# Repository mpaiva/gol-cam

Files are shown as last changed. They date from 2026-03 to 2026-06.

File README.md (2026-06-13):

# gol-cam

Sistema eletrônico completo para **futebol de botão**: uma câmera que detecta gols por visão computacional, um placar (LED tradicional ou touchscreen) que mostra a contagem e um conjunto de peças impressas em 3D que une tudo. A detecção atual combina três sinais — **cor (HSV), movimento (frame-differencing)** e **bordas (Sobel)** — calibrados em conjunto a partir de uma única captura da bola colocada no gol.

## Visão geral do sistema

O repositório agora compila firmware para **três tipos de placa**:

| Componente | Hardware | Função |
|---|---|---|
| **Câmera** | DFRobot DFR1154 (ESP32-S3 + OV3660) | Detecta gols por visão baseada em bordas; serve o painel web e o stream MJPEG |
| **Placar LED** | ESP32 DevKit V1 + 4× matrizes de LED MAX7219 8×8 + 4 botões | Exibe o placar em dígitos de LED físicos; recebe eventos de gol da câmera e suporta override manual |
| **HMI touchscreen** *(opcional)* | CrowPanel DIS07050H (ESP32-S3 + 5" 800×480 IPS capacitivo) | Placar touchscreen + superfície do árbitro com 8 botões: A+/A−/B+/B−, CAL A / START / RESET / CAL B. Fala o **mesmo contrato REST** do placar LED, então pode operar em paralelo ou substituí-lo completamente. |
| **Hardware** | Caixas impressas em 3D (`hardware/`) | Trave, caixa da câmera, gabinete do placar, acessórios |

**Topologia de rede:**

```
                  ┌──────────────┐
                  │  Smartphone  │
                  │  / tablet    │
                  └───────┬──────┘
                          │ Painel HTTP
                          │
       ┌──────────────────┼──────────────────┐
       │                  │                  │
       ▼                  ▼                  ▼
┌────────────┐     ┌────────────┐     ┌──────────────────┐
│ Câmera A   │     │ Câmera B   │     │ Placar           │
│ DFR1154    │     │ DFR1154    │     │ LED (MAX7219) ou │
│ side=A     │     │ side=B     │     │ HMI touchscreen  │
│ .40.90     │     │ .40.91     │     │ .40.89           │
└──────┬─────┘     └──────┬─────┘     └─────▲────────────┘
       │                  │                 │
       └──────────────────┴─────────────────┘
              GET /goal?side=a|b       na detecção
              GET /goal-undo?side=a|b  na anulação VAR
```

A vaga em `.40.89` pode ser ocupada pelo **placar LED** (ESP32 + MAX7219) **ou** pelo **HMI touchscreen** (CrowPanel) — ambos servem o mesmo contrato REST, então as câmeras não precisam saber qual está conectado. Configurar uma partida sem laptop fica simples: o HMI tem os botões CAL A / START / RESET / CAL B na tela e dispara os comandos HTTP para as duas câmeras.

Para uma configuração com apenas uma câmera, omita a Câmera B. Placa e câmera trabalham apenas em modo STA (sem fallback AP); se o WiFi cair, a câmera não consegue empurrar o gol, mas os 4 botões físicos no placar LED — ou os botões A+/A−/B+/B− na tela do HMI — continuam funcionando para placar manual.

**Esquema de IP estático sugerido** (define em `.env` via `WIFI_STATIC_IP` / `SCOREBOARD_STATIC_IP`):

O esquema mantém o **último octeto** fixo (`.89` placar / `.90` cam A /
`.91` cam B) — o prefixo da subnet acompanha a rede WiFi. Hoje em
`192.168.1.x` (RI69); antes em `192.168.40.x` (cross.team-orl). Use os
slots `WIFI_SSID_1..4` no `.env` para registrar redes conhecidas e o
firmware (WiFiMulti) escolhe a melhor disponível no boot.

| Placa | IP | Observação |
|---|---|---|
| Placar (LED **ou** HMI, não ambos ao mesmo tempo) | `192.168.1.89` | Câmeras empurram gols para cá |
| Câmera A (side A) | `192.168.1.90` | `BOARD_ROLE` não definido |
| Câmera B (side B) | `192.168.1.91` | `BOARD_ROLE=home` |

## Como funciona a detecção

Um DFR1154 (ESP32-S3 + câmera grande-angular OV3660) observa a área do gol em **RGB565 QVGA (320×240)**. Você calibra colocando a bola dentro da ROI, e o sistema aprende três assinaturas ao mesmo tempo:

1. **Bordas (Sobel)** — limiar de gradiente que descreve o silhueta da bola
2. **Cor (UV / HSV)** — par de chroma `(U, V)` médio dos pixels dentro do bbox, hue-invariante a mudanças de luma
3. **Movimento (frame-differencing)** — limiar de "piso de ruído" amostrado durante a calibração

Durante a partida, cada frame passa por três disparadores em paralelo, todos compartilhando o cooldown de 10 s:

- **Bordas** — dispara quando o silhueta aparece e desaparece, formato/tamanho dentro da bbox calibrada
- **Movimento** — conta pixels da ROI cuja luma mudou > limiar vs. o frame anterior, *após subtração da média* (DC removal) para ignorar variações uniformes de luz, e *após filtro de bbox compacto* (≤ 30 % da ROI) para rejeitar variações de luz não-uniformes ou sombras de mão
- **Cor** — conta pixels da ROI cuja chroma `(u, v)` está dentro da tolerância em torno do alvo calibrado; mesmo filtro de bbox compacto

O OR dos três triggers dispara o gol. O log serial `[detect]` mostra os três contadores (`e=`, `m=`, `c=`) e qual dispara, e o `GOAL #N` registra a fonte (`src=emc`, `src=mc`, etc.).

**Efeitos colaterais a cada gol:**
- Beep de 1,5 s @ 1 kHz pelo alto-falante I2S (placeholder — será substituído)
- LED IR pisca
- VAR captura *dois* snapshots: o frame de disparo (`/goal-snapshot`) e o frame anterior (`/goal-snapshot-prev`) — útil quando o trigger é por movimento e a bola já saiu do quadro no frame de disparo
- Push HTTP para o placar: `GET /goal?side=a|b`

**VAR (revisão de vídeo):** abrindo qualquer entrada no log de gols, o lightbox mostra os dois frames lado a lado ("Antes" / "Disparo"). Os botões "Foi Gol" mantém; "Anula" decrementa o `goalCount` da câmera **e** dispara `GET /goal-undo?side=a|b` no placar, mantendo o display em sincronia.

Recursos:
- Stream MJPEG ao vivo (a cores)
- Calibração em um clique aprende bordas + cor + ruído de movimento
- Detecção automática de gols com cooldown de 10 s
- Lightbox VAR de dois frames com sincronização do placar na anulação
- Endpoints REST para ajuste em tempo real: `/motion-delta`, `/motion-threshold`, `/motion-bbox-max`, `/color-tol`, `/color-threshold`, `/stream-skip`
- Controles de jogo: iniciar, pausar, retomar, encerrar, reiniciar
- Placar físico de LED com botões de override manual
- `/test-fire` simula um gol completo (snapshot VAR + áudio + push) para testar o pipeline sem a bola

## Futebol de Botão e o Dadinho no Rio de Janeiro

O **futebol de botão** é um esporte de mesa nascido no Brasil na década de 1930, no qual jogadores impulsionam discos circulares com o dedo para movimentar uma peça menor — a bola — por um campo em miniatura. O jogo surgiu da criatividade da garotada brasileira, que transformava botões, tampinhas de garrafa e moedas em times, jogando em mesas de jantar e tabuleiros de madeira pelo país.

### Origens

As raízes do esporte remontam às décadas de 1930 e 1940, quando Geraldo Decourt, de São Paulo, publicou as primeiras regras formais em 1930. O que começou como passatempo infantil rapidamente cresceu para uma atividade competitiva organizada. Em meados do século XX, clubes e federações já haviam se formado, e variações regionais de regras floresceram.

### Rio de Janeiro e a Regra Carioca

O Rio de Janeiro se tornou um dos centros mais importantes do esporte, desenvolvendo seu próprio estilo distinto conhecido como **Regra Carioca** ou **3 Toques**. Por essas regras, o jogador tem até três toques por jogada para avançar a bola, criando um jogo mais rápido e mais tático em comparação com outras variantes regionais.

### O Dadinho

A variante **Dadinho** representa um ramo distinto do futebol de botão. Em vez dos tradicionais discos redondos, os jogadores usam pequenos dados — tipicamente cubos amarelos de 6 mm — como peças. O nome vem de "dado" com o sufixo diminutivo "-inho".

O Dadinho foi oficialmente reconhecido pela Confederação Brasileira de Futebol de Mesa (CBFM) em 2010, dando-lhe a mesma posição institucional das modalidades tradicionais baseadas em disco. A variante tem seu próprio circuito competitivo dedicado, com o Campeonato Brasileiro de Dadinho chegando à 16ª edição em 2025.

## Hardware

### Lista de materiais (BOM)

**Placa da câmera (×1 modo single ou ×2 modo match):**
- 1× DFRobot DFR1154 (ESP32-S3 + OV3660, 16 MB flash, 8 MB PSRAM)
- 1× amplificador I2S MAX98357 + alto-falante pequeno (já inclusos na placa DFR1154)
- Cabo USB-C para alimentação e gravação

**Placa do placar LED (×1, opcional):**
- 1× ESP32 DevKit V1 (qualquer ESP32 com ≥8 GPIOs livres)
- 4× módulos de matriz de LED MAX7219 8×8 (cadeia FC-16), 2 por lado
- 4× push buttons (momentâneos, normalmente abertos)
- Jumpers e fonte de 5 V (USB no DevKit funciona)

**HMI touchscreen (×1, opcional — alternativa ao placar LED):**
- 1× CrowPanel DIS07050H (ESP32-S3-WROOM-1-N4R8, 5" 800×480 RGB IPS, touch capacitivo GT911)
- Cabo USB-C para alimentação e gravação
- *Substitui* o placar LED se ocupar o IP `.89`; ou roda em paralelo num IP diferente para servir como segundo display do árbitro

**Mecânica:**
- Peças impressas em 3D a partir de `hardware/` (PLA, veja `hardware/README.md` para configurações do slicer)

### Fiação do placar (ESP32 DevKit V1)

Os macros estão inline no topo de `src_scoreboard/scoreboard.cpp`.

**Display A** (placar da esquerda, 2 módulos em cadeia, DOUT → DIN):

| MAX7219 | GPIO | Macro |
|---|---|---|
| DIN | 23 | `DIN1` |
| CLK | 18 | `CLK1` |
| CS  | 5  | `CS1`  |
| VCC | 5V (VIN) | — |
| GND | GND | — |

**Display B** (placar da direita, 2 módulos em cadeia):

| MAX7219 | GPIO | Macro |
|---|---|---|
| DIN | 19 | `DIN2` |
| CLK | 21 | `CLK2` |
| CS  | 22 | `CS2`  |

**Botões** (cada um do GPIO ao GND, `INPUT_PULLUP` — sem resistores externos):

| Botão | GPIO | Macro | Ação |
|---|---|---|---|
| UP A | 32 | `UP1` | Incrementa lado A |
| DW A | 33 | `DW1` | Zera lado A |
| UP B | 25 | `UP2` | Incrementa lado B |
| DW B | 26 | `DW2` | Zera lado B |

### Pinagem da câmera

Veja `include/pins.h` — pré-configurada para a placa DFR1154. Não precisa fazer fiação.

### HMI touchscreen (CrowPanel)

Não precisa fazer fiação — toda a placa vem com o display RGB paralelo, touch I²C (GT911 em 0x5D, SDA=GPIO 19, SCL=GPIO 20), backlight (GPIO 2) e UART0 via CH340 conectados de fábrica. Definições de pino em `src_hmi/main.cpp`.

### Peças impressas em 3D

Veja `hardware/README.md` para o catálogo de peças (trave V4, caixa da câmera V5.2, gabinete do placar, suporte de alto-falante, grade de cooler) com recomendações de fatiamento.

## Primeiros passos

### Pré-requisitos

- [Git](https://git-scm.com/downloads)
- [Python 3](https://www.python.org/downloads/) (marque "Add to PATH" no instalador do Windows)
- Cabo USB-C para o DFR1154; cabo USB para o ESP32 DevKit
- **Apenas Windows:** [driver USB CP210x](https://www.silabs.com/developers/usb-to-uart-bridge-vcp-drivers) (pode ser necessário para comunicação serial)

### Passo 1 — Clonar o repositório

```bash
git clone https://github.com/mpaiva/gol-cam.git
cd gol-cam
```

### Passo 2 — Criar um ambiente virtual Python

**Mac (Terminal):**
```bash
python3 -m venv .venv
source .venv/bin/activate
pip install platformio
```

**Windows (PowerShell):**
```powershell
python -m venv .venv
.venv\Scripts\Activate.ps1
pip install platformio
```

> Se o PowerShell bloquear o script, rode `Set-ExecutionPolicy -Scope CurrentUser RemoteSigned` antes.

### Passo 3 — Configurar `.env`

Crie um arquivo `.env` na raiz do projeto (ignorado pelo git):

```ini
# Obrigatório — mesma WiFi para câmera e placar
WIFI_SSID=nome-da-sua-rede
WIFI_PASSWORD=sua-senha

# IP do placar — todas as câmeras empurram gols para cá (recomendado: estático)
SCOREBOARD_IP=192.168.1.89
SCOREBOARD_STATIC_IP=192.168.1.89
SCOREBOARD_GATEWAY=192.168.1.1
SCOREBOARD_SUBNET=255.255.255.0

# Per-board (definir antes de gravar cada câmera; valores comentados são exemplos)
# Câmera A (side A — padrão):  WIFI_STATIC_IP=192.168.1.90, BOARD_ROLE não definido
# Câmera B (side B):            WIFI_STATIC_IP=192.168.1.91, BOARD_ROLE=home
WIFI_GATEWAY=192.168.1.1
WIFI_SUBNET=255.255.255.0
# WIFI_STATIC_IP=192.168.1.90
# BOARD_ROLE=home              # home → side B; ausente → side A
# SCOREBOARD_SIDE=b            # override explícito (a|b), tem prioridade sobre BOARD_ROLE
```

`load_env.py` lê esses valores e injeta como `-D` defines de build, então são compilados no firmware. Como `WIFI_STATIC_IP` e `BOARD_ROLE` precisam ser diferentes em cada câmera, ajuste-os antes de cada gravação.

### Passo 4 — Compilar e gravar

Três ambientes PlatformIO convivem no mesmo projeto, um por tipo de placa:

```bash
# Câmera (padrão — igual a `pio run`)
pio run -e dfr1154 -t upload

# Placar LED MAX7219
pio run -e placar -t upload

# HMI touchscreen CrowPanel (alternativa ao placar LED)
pio run -e crowpanel_hmi -t upload
```

O ambiente padrão é `dfr1154`, então um `pio run` sem parâmetros compila a câmera. Grave uma placa por vez, ajustando o `.env` entre gravações se quiser valores diferentes de `BOARD_ROLE` ou IP estático.

Para usar o **HMI no lugar do placar LED**, defina `WIFI_STATIC_IP=192.168.1.89` antes de gravar o HMI e desligue a placa do MAX7219 — as câmeras seguem empurrando gols para `.89` sem nenhuma mudança no firmware delas.

### Passo 5 — Descobrir o IP e abrir o painel

```bash
pio device monitor   # baud 115200, procure "Dashboard: http://..." na câmera
```

Abra o IP da câmera no navegador. Você verá o seletor de modo:
- **Training (Treino)** — uma câmera, calibração e prática
- **Match (Partida)** — duas câmeras + placar opcional; configure os IPs na primeira carga (salvos no `localStorage`)

O placar serve sua própria interface simples no IP dele (incremento/reset manual, mais o status atual da conexão).

## Operação

### Fluxo padrão de partida

1. **Calibre cada câmera** — coloque o dadinho na frente do gol, clique em "Calibrate"
2. **Inicie o jogo** — o painel de partida mostra os feeds ao vivo e o placar unificado
3. **Jogue** — a câmera detecta gols, toca som de comemoração, envia o evento para o placar e incrementa o placar de LED
4. **Revisão VAR** — clique em qualquer entrada de gol para confirmar ou anular (gols anulados subtraem do lado certo)
5. **Pausar / retomar / reiniciar / encerrar** — controles atingem todas as placas simultaneamente

### Placar autônomo (sem câmera)

Mesmo com as câmeras offline ou desligadas, o placar continua funcionando:
- **Placar LED**: botões físicos sempre funcionam (UP A/B, RESET A/B). A interface web em `http://192.168.1.89/` espelha os botões + adiciona `/api/reset`.
- **HMI touchscreen**: os 8 botões na tela (A+ / A− / B+ / B−, CAL A / START / RESET / CAL B) operam o placar e as câmeras direto pelo display, sem precisar de celular ou notebook.
- Endpoints REST disponíveis em qualquer das duas placas: `/goal?side=a|b` (+1), `/goal-undo?side=a|b` (−1, com piso em 0), `/a+`, `/b+`, `/az`, `/bz`, `/reset`, `/api/reset`, `/status`.
- O HMI também expõe endpoints de diagnóstico do touch: `/debug/touch` retorna estado do controlador GT911 em JSON (útil quando o painel parece não responder).

## Estrutura do repositório

```
gol-cam/
├── platformio.ini              # Três ambientes: dfr1154 + placar + crowpanel_hmi
├── partitions.csv              # Layout de 16 MB de flash para a câmera
├── load_env.py                 # .env → -D defines de build
├── .env                        # WiFi + IP estático + role (ignorado pelo git)
├── include/
│   ├── camera.h, pins.h        # Câmera (DFR1154)
│   ├── frame_store.h           # Buffer JPEG thread-safe para o stream MJPEG
│   └── goal_detector.h         # Struct GoalDetector (contadores, FPS)
├── src/
│   ├── main.cpp                # Câmera: loop de detecção (bordas + movimento + cor)
│   ├── web_stream.cpp          # Servidor HTTP da câmera (esp_http_server)
│   ├── mode_select.h           # HTML do seletor Training / Match
│   ├── training_dashboard.h    # HTML/JS do painel de treino (uma câmera)
│   └── match_dashboard.h       # HTML/JS do painel de partida (duas câmeras)
├── src_scoreboard/
│   └── scoreboard.cpp          # Placar LED: firmware monolítico (WiFi + MAX7219 + HTTP + botões)
├── src_hmi/
│   └── main.cpp                # HMI touchscreen: RGB panel + GT911 + REST do placar + 8 botões touch
├── tests/integration/
│   └── test_system.py          # Suíte stdlib que exercita o contrato REST ao vivo (70 checks)
├── hardware/                   # Caixas impressas em 3D
├── .about/                     # Proposta de valor, feature requests
├── .plans/                     # Planos de implementação, notas de sessão
└── .reports/                   # Pesquisa, auditoria de UX, screenshots
```

## Testes

Suíte de integração que bate na REST ao vivo das três placas:

```bash
python3 tests/integration/test_system.py
```

70 checks cobrindo formato do `/status`, transições `/calibrate`, `/reset`, `/deduct` (clamp em 0), e o caminho de sincronização entre câmera e placar (`/test-goal` empurrando para `.89`, `/test-fire` com snapshot VAR, anulação VAR via `/goal-undo`). Skip automático de qualquer placa que estiver offline.

## Licença

MIT

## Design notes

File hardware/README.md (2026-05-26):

# Hardware — Modelos 3D imprimíveis

Peças mecânicas do sistema gol-cam, importadas do projeto auxiliar `GOOOL Elatronico` em 2026-05-24. Os modelos do placar virão do `Placar Eletronico` na Fase 2 do plano de consolidação (ver `.plans/consolidation-plan.md`).

Todos os arquivos `.3mf` são projetos completos do Bambu Studio / PrusaSlicer (incluem orientação, suportes e settings recomendados). Os `.stl` são as malhas cruas — use-os se preferir reimportar em outro slicer.

---

## Layout

```
hardware/
├── trave/                   # Estrutura da trave eletrônica (atual: V4)
├── caixa-camera/            # Encaixe da câmera DFR1154 (atual: V5.2)
├── placar/                  # Caixa do placar ESP32 + MAX7219 (vem na Fase 2)
├── acessorios/              # Fixação do autofalante, grade do cooler
└── arquivos-historicos/     # Versões antigas — referência apenas
```

---

## `trave/` — Trave eletrônica

A trave é a estrutura principal: gol de futebol de botão de 15 cm × 4 cm que abriga a câmera no teto e a "boca" abre a região do gol.

| Arquivo | Função | Versão |
|---|---|---|
| `Trave Eletronica+teto V4.3mf` | Trave + teto integrados, projeto Bambu | **Atual** |
| `Trave Eletronica+teto V4.stl` | Mesma malha em STL | **Atual** |
| `Boca da Trave.3mf` | Anteparo frontal (boca do gol) | **Atual** |
| `Boca da Trave.stl` | Mesma malha em STL | **Atual** |

**Recomendação de impressão:** PLA, camada 0.2 mm, infill 20–30%, com suportes na parte de baixo do teto.

---

## `caixa-camera/` — Encaixe da câmera DFR1154

Caixa que envolve a placa DFR1154 (42 × 42 mm, ESP32-S3 + OV3660) e fixa dentro do teto da trave. A versão atual é a **V5.2**, com base separada para facilitar o acesso ao conector USB-C.

| Arquivo | Função | Versão |
|---|---|---|
| `Caixa Camera Golll V5.2.3mf` | Corpo da caixa (V5.2) | **Atual** |
| `Base Caixa Camera Golll V5.2.stl` | Base/tampa de fundo (V5.2) | **Atual** |
| `Caixa Camera Golll V5.1.3mf` | Corpo (V5.1, fallback) | Ativa |
| `Caixa Camera Golll V5.1.stl` | Malha STL (V5.1) | Ativa |

**Recomendação de impressão:** PLA, camada 0.16 mm para detalhe na abertura da lente, sem suportes (geometria foi planejada para imprimir orientada).

---

## `placar/` — Caixa do placar LED

Caixa do placar físico (ESP32 DevKit V1 + 4× matrizes LED MAX7219 8×8 + 4 botões push). Modelos serão importados do projeto `Placar Eletronico` durante o subtree merge (Fase 2 do plano).

> Esperar até a Fase 3 concluir — após isso esta pasta conterá `Placar ESP 32 Wifi.3mf` e `New Scene.3mf`.

---

## `acessorios/` — Peças auxiliares

| Arquivo | Função |
|---|---|
| `Est. Fix. Autofalante 1.3mf` | Suporte de fixação do autofalante (saída de áudio I2S/MAX98357 do gol-cam) |
| `grade_para_cooler_colmeia_com_borda_85mm.3mf` | Grade tipo colmeia 85 mm, ventilação interna |

---

## `arquivos-historicos/` — Referência apenas

Versões anteriores das caixas de câmera e traves. **Não imprima a partir destes arquivos** sem antes confirmar que substituem alguma peça nova. Mantidos para rastrear evolução do design.

- Caixas V1, V2, V3, V3.1, V3.2, V3.3 (substituídas pela V5.x)
- Trave V3 e versões `Trave Desmontada`, `Trave Eletronica+teto` (sem versão), `Trave Eletronica` (sem teto) — substituídas pela V4

---

## Origem

- Pasta `trave/`, `caixa-camera/`, `acessorios/`, `arquivos-historicos/`: projeto `C:\_PROJETOS\GOOOL Elatronico` (sem git, importado por cópia em 2026-05-24)
- Pasta `placar/`: projeto `C:\_PROJETOS\Placar Eletronico` (importado via `git subtree merge`, preservando histórico)

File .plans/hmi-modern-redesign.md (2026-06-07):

# Plan — Redesign the HMI placar as a modern sports app

**Date:** 2026-06-07
**User prompt:** *"use frontend design skills to redesign the interface
into a modern sports app"* — then, after a first attempt was
rejected: *"this modern scoreboard show the timer, which we dont have,
but we need to add to the plan."* with a screenshot of a 2014 FIFA
World Cup ARG vs GER scoreboard widget as reference.

The current placar UI is functional but reads as a debug surface: a
flat black background, big bitmap digits, eight pill buttons arranged
in two rows. This plan rebuilds the main view as a **compact, card-
based scoreboard** modelled on the user's reference: pill-shaped
container with a circular minute-timer at the centre, score-on-dark
rectangles per team, status row of controls underneath.

**First attempt (rejected):** the Brasileirão palette + full-screen
split-card layout was a different direction from what the user wanted
(see git stash @{0} for the implementation). Keep the failed attempt
around as a colour-palette reference but discard the layout.

The calibration overlay is intentionally **out of scope** for this
plan — it was just redesigned (white panel + cam-snapshot preview)
and its own redesign would land in a phase 2.

---

## 1. Current vs target

### Today
```
┌──────────────────────────────────────────────────────────────┐
│ gol-cam                                       [PLACAR pill]  │
│                                                              │
│                       0  x  0                                │   ← bitmap digits
│                                                              │
│ ┌──────┐ ┌──────┐ ┌──────┐ ┌──────┐                          │   ← A+/A-/B-/B+
│ │ A +  │ │ A -  │ │ B -  │ │ B +  │                          │
│ └──────┘ └──────┘ └──────┘ └──────┘                          │
│ ┌──────┐ ┌──────┐ ┌──────┐ ┌──────┐                          │   ← CAL/START/RESET/CAL
│ │CAL A │ │START │ │RESET │ │CAL B │                          │
│ └──────┘ └──────┘ └──────┘ └──────┘                          │
│                                                              │
│   HOME [IDLE pill]              AWAY [IDLE pill]             │
└──────────────────────────────────────────────────────────────┘
```

### Target (inspiration-driven card scoreboard)

Modelled directly on the user's reference image — a pill-shaped main
scoreboard with a circular timer at the centre, score-on-dark
rectangles for each team. On our 800×480 canvas we have room for the
scoreboard pill on top AND a second pill or row underneath for the
control surface.

```
        ┌─────────────────────────────────────────────┐
        │                                             │
        │  ╔══╗         ╭─────╮          ╔══════════╗ │
        │  ║●●║         │ 12' │   HOME ◆ ║    0     ║ │
        │  ║●●║         │ 45" │          ╚══════════╝ │   ← scoreboard pill
        │  ╚══╝         ╰─────╯          ╔══════════╗ │      y=30..200 (h=170)
        │                                ║   AWAY   ║ │
        │  app icon     timer ring  AWAY ◆ ║    0     ║ │
        │  / logo                          ╚══════════╝ │
        │                                             │
        └─────────────────────────────────────────────┘

        ┌────────────────────┐  ┌──────────────────────┐
        │  ● HOME READY      │  │  ● AWAY READY        │  ← status pills
        │  cam @ .40.90      │  │  cam @ .40.91        │      y=220..300
        └────────────────────┘  └──────────────────────┘

   ┌──┐ ┌──┐ ┌────────┐ ┌────────┐ ┌────────┐ ┌────────┐ ┌──┐ ┌──┐
   │− │ │+ │ │ CAL A  │ │ ▶ START│ │ RESET  │ │ CAL B  │ │− │ │+ │   ← controls
   └──┘ └──┘ └────────┘ └────────┘ └────────┘ └────────┘ └──┘ └──┘      y=330..460
   A    A                                                  B    B
```

Net visual changes from today:
- **Pill-shaped scoreboard** instead of a flat header + huge digits.
  Rounded ~25–30 px corners. Cream/off-white background mimicking the
  reference. Sits at the top of the screen as the dominant element.
- **Circular minute-timer** (~140 px diameter) centred in the pill.
  Shows `M' SS"` (minute and seconds since START tap). A ring around
  the disc fills in as the timer advances — emerald arc on the right
  side per the reference. **This is new — we have no timer today.**
- **Score-on-dark blocks** per team. Each team gets a horizontal row
  with: team label ("HOME" / "AWAY") + small colored "flag" disc
  (no national flags — just a coloured pill to identify the side) +
  a dark rectangle holding the score in large white digits. Matches
  the reference's "ARG 🏳️ 3" / "GER 🏳️ 1" stacked rows.
- **Separate status pills** for each team below the scoreboard,
  showing cam-state dot + label + cam IP. Replaces the in-card
  status row from the rejected attempt.
- **Control row** of pill-shaped buttons at the bottom — same 8
  controls as today (A−/A+, CAL A, START, RESET, CAL B, B−/B+) but
  styled as discrete pills rather than a ribbon.

---

## 2. Color palette — match the reference

Pulled directly from the user's reference image. RGB565-safe.

- Page background: `0x0500` deep green field (kept from the Brasileirão
  attempt — it complements the cream pills well, same as the
  reference's blurry green stadium backdrop).
- Pill background (scoreboard, status pills, control buttons):
  `0xEF7D` warm cream (slight yellowish tint, soft).
- Score-block background (the dark rectangle holding each digit):
  `0x2104` near-black charcoal.
- Score digits: `0xFFFF` white.
- Team label text on pill: `0x4208` dark slate.
- Timer numerals: `0x2104` near-black.
- Timer ring (progress arc): `0x07E2` emerald green; track:
  `0xC638` light grey.
- Status dots: same as today (green READY, orange CAL, yellow PAUSE,
  red OFFLINE, grey IDLE).
- Action button (START): green `0x0640` bg + white text.
- Destructive button (RESET, `−`): red `0xC000` bg + white text.
- CAL buttons: amber `0xFD20` bg + black text.
- Score-adjust `+`: green; `−`: red. Both narrow.

---

## 3. Typography hierarchy

Arduino_GFX scales by integer multiples of its bitmap font (~6×8
base glyph). Available size tiers: 2 (12×16), 3 (18×24), 4 (24×32),
5 (30×40), 6 (36×48), 8 (48×64).

| Element | Size | Pixels per glyph |
|---|---|---|
| Score digit (in dark block) | 6 | 36×48 — single digit fits in a 70 px wide block |
| Timer minutes ("12'") | 6 | 36×48 |
| Timer seconds ("45\"") | 3 | 18×24 — sits below the minute number, smaller |
| Team label ("HOME", "AWAY") | 3 | 18×24 |
| Status badge ("READY", "OFFLINE") | 2 | 12×16 |
| Cam IP / metadata | 2 | 12×16 |
| Button label | 3 | 18×24 |
| Score-adjuster `+ / −` | 4 | 24×32 (big enough to read) |

---

## 4. Component spec

### Scoreboard pill (y=20–200, x=40–760, w=720, h=180, r=30)
- `fillRoundRect` cream background, white border 2 px.
- Internal layout (left to right):
  - **App badge** (~x=70, y=100, r=50): green-felt circle with
    a tiny soccer-ball glyph (overlapping fillCircles drawn in
    a pentagon-ish pattern — cheap stylization). Replaces the
    reference's FIFA World Cup logo.
  - **Timer disc** (~x=300, y=110, r=70): white circle with
    minute number ("12'") in size-6 black, seconds ("45\"") in
    size-3 grey underneath. Outside the circle, a partial ring
    (drawn via many short arcs) shows progress through the
    notional half (full ring at 45'). Track grey, progress
    emerald.
  - **Score column** (x=470 to 720): two stacked rows.
    - Row 1 (y=45..115): `HOME ● ║ 3 ║` — label size 3 black,
      colored disc (HOME = cobalt), then a dark rectangle
      (x=600..720, h=70) with white size-6 digit centred.
    - Row 2 (y=125..195): `AWAY ● ║ 1 ║` — same layout, AWAY
      colored disc (yellow).

### Match timer state (NEW)
- Tracked in three new globals: `uint32_t matchStartMs`,
  `uint32_t matchPausedAccumMs`, `enum MatchState
  {MS_IDLE, MS_PLAYING, MS_PAUSED}`.
- Behaviour:
  - `MS_IDLE`: display "00' 00\""; ring empty.
  - START tap → `matchStartMs = millis()`, state = MS_PLAYING.
  - PAUSE tap → `matchPausedAccumMs += millis() - matchStartMs`,
    state = MS_PAUSED.
  - RESUME tap → `matchStartMs = millis()`, state = MS_PLAYING
    (the previous elapsed time lives in `matchPausedAccumMs`).
  - RESET tap → `matchPausedAccumMs = 0`, state = MS_IDLE.
  - Display: `elapsedMs = (state == MS_PLAYING)
      ? (millis() - matchStartMs + matchPausedAccumMs)
      : matchPausedAccumMs;`
- Timer redraw runs on a dirty flag set when (a) state changes or
  (b) the displayed minute or second value advances. A 500 ms loop
  poll on the timer is plenty.
- The cams' state is independent of `MatchState`; the timer is
  HMI-local.

### Status pills (y=220–300, two side-by-side)
- Left pill: HOME, x=40..390 (w=350, h=70, r=20).
  Inside: `● READY` size 3 + cam IP size 2 below.
- Right pill: AWAY, x=410..760.
- Same cream pill style as the scoreboard.

### Control row (y=330–460, h=130)
- Eight pill buttons, single row, similar widths to the
  rejected-attempt's footer ribbon:
  - `−` (A score down): x=10, w=60, h=110, r=20, red bg
  - `+` (A score up): x=80, w=60, red bg
  - `CAL A`: x=160, w=130, amber bg, black text
  - `▶ START`: x=300, w=160, green bg, white text (label flips
    to `⏸ PAUSE` / `▶ RESUME` per cam state, same as today)
  - `⟲ RESET`: x=470, w=130, red bg, white text
  - `CAL B`: x=610, w=130, amber bg, black text
  - `−`: x=750, w=60... actually we run out of width here. Tune
    spacing — likely shrink the inner buttons to 110 px or move
    score adjusters to the very edges with smaller widths.

### Touch hit-test
- Score adjusters become 60 px wide × 110 px tall. Still well
  above the GT911's effective resolution.
- CAL buttons at 130 px wide — comfortably tappable.

---

## 5. Implementation breakdown

All work in `src_hmi/main.cpp`. Estimated ~600 LOC churn (more than
the rejected attempt because of the timer state machine + circular
timer rendering).

1. **Palette constants** (~`src_hmi/main.cpp:430`): cream pill bg,
   charcoal score-block bg, slate text, emerald + grey ring colors.
2. **Match-timer state machine** — three new globals
   (`matchStartMs`, `matchPausedAccumMs`, `MatchState matchState`)
   and a helper `matchElapsedMs()` that returns the live elapsed.
   Wire `START`, `PAUSE`/`RESUME`, `RESET` action handlers to
   transition this state. Add a `dirtyTimer` flag set every 500 ms
   from `loop()` so the timer text refreshes once per second
   without redrawing the whole pill.
3. **Replace `drawHeader()`** → no longer needed; replaced by the
   scoreboard pill which IS the top of the screen. Remove the
   header-strip code path entirely.
4. **New `drawScoreboardPill()`** — paints the cream pill, the app
   badge circle, the timer disc with ring (helper
   `drawTimerRing(cx, cy, r, progress01)`), and the two team rows
   (label + flag-disc + dark score-block + white digit).
5. **New `drawStatusPills()`** — two cream pills with status dot,
   state label, cam IP. Replaces `drawSideStatus`.
6. **Reshape the `buttons[]` array** to the new control-row
   coordinates from §4.
7. **`drawButton(idx)`** — keep mostly as-is. Use rounded-rect r=20
   for the pill aesthetic. Already handles START label flip.
8. **`renderFull()`** — clear bg, scoreboard pill, status pills,
   buttons. Drop `drawHeader` + `drawScoreDigits` + `drawSideStatus`
   from the rotation since they're folded into the new helpers.
9. **Dirty-flag wiring** — `dirtyScore` triggers
   `drawScoreboardPill` (score lives inside it). `dirtyTimer`
   redraws ONLY the timer disc, not the whole pill (small
   sub-region repaint).
10. **Glyph helpers** — small drawn primitives for play triangle,
    pause bars, reset spiral. ~30 LOC.

---

## 6. Acceptance criteria

| # | Criterion | How to verify |
|---|---|---|
| AC1 | Scoreboard pill is the dominant element at the top, score digits visible from across the room. | Manual eyeball test |
| AC2 | Timer counts up by seconds after tapping START; pauses on PAUSE; resumes on RESUME; resets on RESET. | Tap START, wait 5 s, tap PAUSE, verify display freezes; tap RESUME, verify resumes; tap RESET, verify back to `00' 00"`. |
| AC3 | Timer ring fills visibly as the timer advances (track grey, fill emerald). | Manual; check both the disc and the ring update. |
| AC4 | HOME / AWAY status pills show correct state (READY / IDLE / CAL / PAUSE / OFFLINE) per cam. | Manual + power-cycle a cam to see the state changes. |
| AC5 | All 8 control buttons fit in the row and respond to taps. | Manual + tap each button. |
| AC6 | Calibration overlay still works (it's drawn on top of the new placar). | Tap CAL A → overlay appears, dismisses cleanly. |
| AC7 | All 70 integration tests still pass (REST surface unchanged). | `python3 tests/integration/test_system.py` |
| AC8 | HMI `/status` soak stays ≥ 80/90 (no regression from the pclk fix). | 90 s × 1 Hz triple-board soak |

---

## 7. Risks

- **Glyph rendering.** Arduino_GFX's default font doesn't carry
  `▶ ⟲ ⏸ ●`. We draw these as primitives (filled triangle,
  arc-segment, two vertical rects, filled circle). Small functions,
  ~10 LOC each.
- **Button text wrapping.** With buttons at 110 px wide and size 3
  text (18 px / char), `CAL A` = 90 px fits, `START` = 90 px fits,
  `RESET` = 90 px fits. Safe.
- **Card border vs touch.** A 14 px rounded corner means the
  hit-test rect overlaps the card visual by ~14 px in the corner.
  Buttons sit OUTSIDE the cards in the footer, so no conflict.
- **Refresh rate.** At 8 MHz pclk (~17 Hz), large fillRounded calls
  on every dirty flag could look sluggish. Audit which areas
  actually need to redraw on score changes (only the inner score
  digit, not the whole card).

---

## 8. Open questions

- **Timer convention.** A button-soccer match isn't a standard
  90-min football match. Options: (a) free-running count-up
  showing `M' SS"`; (b) bounded countdown of N minutes (configurable
  later); (c) showing periods/halves. Default in this plan: free
  count-up — minimal state, no settings UI needed.
- **Timer ring scale.** Default: full ring at 5 min match length
  (which makes the ring visually advance fast enough to feel alive
  in a typical 2-3 min play). The reference image shows 45' full,
  but our matches are much shorter.
- **Team names beyond HOME/AWAY?** Defer — would need a settings
  screen.
- **Glyph rendering for the soccer-ball app badge.** Cheap option:
  just a green-felt circle with a white "G" text overlay. Skip the
  pentagon-pattern complexity.

---

## 9. Pickup steps

1. Confirm palette choice (A / B / C / mix).
2. Add the new color constants.
3. Replace `drawHeader()`, `drawScoreDigits()`, `drawSideStatus()`,
   and the button array.
4. Add the glyph helpers (`drawPlayTriangle`, `drawResetArc`,
   `drawStatusDot`).
5. Build + flash, eyeball each AC.
6. Run integration tests + soak.
7. Commit + push.

---

## 10. Out of scope (deferred)

- Calibration overlay restyle. Currently white panel + cam
  snapshot; works well. Could harmonize with the new palette in
  a phase 2 after live-stream lands.
- Settings screen / team names.
- Real match timer.
- Custom font (would require porting a TTF to a GFXfont header
  and bundling, which is doable but +30 KB of code).
- Animations beyond the existing button-press color flip.

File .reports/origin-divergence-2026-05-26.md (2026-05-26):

---
date: 2026-05-26
prompt: "please check this repo agains origin and evaluate what needs to be updated."
status: evaluation only — no code changes made
---

# Origin Divergence Evaluation — 2026-05-26

## TL;DR

`master` and `origin/master` have **diverged** since `ab35f14` (PR #1 merge):

- **Local (13 commits, May 9–10):** UI redesign, scoreboard *integration & hardware debugging* — battery operation, brightness, WiFi TX-power tuning, VSYNC overflow fix, HTTPD stack-overflow fix, ROI auto-tune.
- **Remote (12 commits, May 9 + May 24):** Repo *consolidation* — subtree-merged the Placar Eletronico history, imported 3D models under `hardware/`, dual-environment `platformio.ini`, modular `placar_*.cpp` files, new `README.md` (EN + pt-BR), updated `CLAUDE.md`, `.gitignore`, scoreboard-side push from camera.

**Both sides have value.** Local has hardware-tested fixes; remote has cleaner architecture and missing docs/3D assets. Neither should be discarded.

## Divergence point

```
merge-base: ab35f14  Merge pull request #1 from mpaiva/edge-detection-grayscale
```

## Conflicting files (5)

| File | Local Δ | Remote Δ | Nature of conflict |
|---|---|---|---|
| `load_env.py` | +3 / −1 | +1 / −1 | Both add scoreboard env vars. Local set is a superset (adds `SCOREBOARD_SIDE`, `SCOREBOARD_STATIC_IP`, etc.). Remote adds `CAMERA_IP`. **Trivial reconcile.** |
| `platformio.ini` | Adds env `scoreboard` w/ single-file `src_scoreboard/scoreboard.cpp` | Adds env `placar` w/ modular `src/placar_*.cpp` + `-DBOARD_ROLE_*` macros | **Architectural conflict** — same goal, two layouts. |
| `src/main.cpp` | +418 / −89 (battery push, ROI auto-tune, side resolution, scoreboard.cpp glue) | +58 (own `goalPushTask` w/ POST JSON) | Two implementations of "push goal to scoreboard". Local uses `GET /goal?side=`; remote uses `POST /goal {"side":"A"}`. |
| `src/web_stream.cpp` | +61 / −29 (stack-overflow fix, memory stats in `/status`) | +5 / −2 (adds `"side"` field to `/status`) | Local is the bigger / more critical change; remote's `side` field can be re-applied on top. |
| `src/match_dashboard.h` | +317 / −240 (full UI redesign — hierarchy, expert toggle, client-side overlays) | +36 / −8 (adds Placar IP field + status polling) | Local rewrote large blocks; remote added a Placar-status row. Remote additions need to be re-grafted into the redesigned UI. |

## Non-conflicting additions on remote that we should pull in regardless

These don't touch local files and are pure additions:

- `README.md` + pt-BR translation
- `hardware/` (caixa-câmera STL/3MF, trave, acessórios, histórico) — **real assets, no local equivalent**
- `_import_placar/` (subtree-merged git history of the Placar Eletronico repo)
- `.gitignore` — adds `.claude/`
- `.plans/consolidation-plan.md`, `.plans/session-2026-05-24.md`
- `CLAUDE.md` edits (documents the dual-env layout)
- `.about/feature-requests.md` adds F6/F7 (Placar + Standalone)

## Non-conflicting local additions remote doesn't have

- `.plans/scoreboard-integration-2026-05-10.md`, `.plans/auto-contrast-tune.md`, `.plans/self-improvement-2026-05-09.md`
- `src_scoreboard/scoreboard.cpp` (421 LOC, battery-debugged firmware)
- Deletion of `include/gol_sound*.h` (legacy audio headers)
- `include/camera.h` tweaks

## Key risk: scoreboard firmware

Remote's `src/main_placar.cpp` + `placar_*.cpp` total **448 lines** of clean port from the Arduino sketch. Local's `src_scoreboard/scoreboard.cpp` is **421 lines** with hardware-debugged fixes the remote does *not* have:

- `WiFi.setSleep(WIFI_PS_MIN_MODEM)` — fixes battery operation
- `WiFi.setTxPower(...)` — softens current spikes
- `NORMAL_BRIGHTNESS = 8` chosen after testing brightness 13 caused power-bank cutoff
- Keep-alive pulse so phone power banks don't auto-shut-off
- Static-IP commit so power-cycles don't break gol-cam pushes
- Comments documenting the 1000 µF cap wiring

**Dropping local's scoreboard.cpp loses real debugging work.** Conversely, keeping it as-is means we ignore remote's modular split.

## Recommended path forward

**Option A (recommended) — Merge, favor local code + remote structure**

1. `git merge origin/master` (creates 5 conflicts).
2. Resolve:
   - `load_env.py`: union of both sets of env vars.
   - `platformio.ini`: keep remote's dual-env skeleton, rename env `placar` → also accept `scoreboard`, or just rename local's `src_scoreboard/` to fit remote's `src/placar_*.cpp` layout.
   - `src/main.cpp`: keep local entirely; drop remote's `goalPushTask` (local has its own, more refined version).
   - `src/web_stream.cpp`: keep local; re-apply remote's 3-line `"side"` field addition to the JSON.
   - `src/match_dashboard.h`: keep local UI; re-graft remote's Placar IP field + `pollPlacar()` into the redesigned layout.
3. Decide: port local's `scoreboard.cpp` hardware fixes into remote's modular `placar_*.cpp` files **OR** keep `src_scoreboard/scoreboard.cpp` and adjust `platformio.ini` env to point to it. The first is cleaner; the second is faster.

Estimated effort: **2–4 hours** including a clean build + smoke test on the camera board (scoreboard hardware needed for full validation).

**Option B — Rebase local onto origin/master**

Replay each of the 13 local commits on top. Cleaner history but the platformio/main/dashboard conflicts will fire multiple times. Not recommended unless we want a linear log.

**Option C — Push local, abandon remote (NOT recommended)**

Would discard the hardware/ 3D models, README, subtree-merged history, and consolidation work. Don't do this.

## Action items

- [ ] User picks A/B/C above.
- [ ] If A: create `.plans/origin-merge-2026-05-26.md` with the per-file resolution script.
- [ ] Run `pio run -e dfr1154` after merge to confirm camera still builds.
- [ ] Run `pio run -e placar` (or `-e scoreboard`) to confirm second env builds.
- [ ] Smoke-test camera on actual hardware before pushing.

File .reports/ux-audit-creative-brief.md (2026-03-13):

# gol-cam UX Audit & Creative Brief for Design Agency

**Date:** 2026-03-13
**Prepared by:** Engineering team
**Purpose:** Provide full UX context to external design agency for a UI/UX redesign

---

## 1. Product Overview

**gol-cam** is a mini camera-based goal detection system for button soccer ("futebol de botão"). A small ESP32-S3 camera module (42mm x 42mm) mounts on a tabletop soccer goal (15cm x 4cm) and uses computer vision to detect when a 4mm or 6mm ball enters the goal, triggering a scoring event with sound.

**Target users:** Button soccer enthusiasts, tabletop sports players, makers/hobbyists. Primarily Brazilian — the sport is most popular in Brazil.

**Hardware:** DFRobot ESP32-S3 AI Camera Module — runs a web server over WiFi. Users access the UI from any phone/tablet/laptop browser on the same network. There is no native app — the entire interface is served as HTML/CSS/JS from the ESP32.

**Key constraints:**
- The UI is served from a microcontroller with 16MB flash — pages must be lightweight
- All rendering is client-side (no server-side templating beyond serving static HTML)
- Users interact via phone browser while standing at a table — one-handed mobile use is critical
- Latency matters: the interface polls the board every 500ms for status updates
- Bilingual audience: English and Portuguese (recently added i18n)

---

## 2. Information Architecture

```
/ (Mode Select)
├── /training (Training Dashboard — single camera)
│   ├── States: IDLE → CALIBRATING → IDLE (calibrated) → PLAYING → PAUSED → IDLE
│   ├── Sub-features: VAR review, goal log, debug console
│   └── Back: ← Menu → /
└── /match (Match Dashboard — two cameras)
    ├── Phase 1: Config panel (enter 2 board IPs)
    ├── Phase 2: Live scoreboard + dual camera feeds
    ├── States: mirrors training but for 2 boards simultaneously
    ├── Sub-features: VAR review, goal log, unified controls
    └── Back: ← Menu → /
```

**Total pages:** 3
**Total user-visible strings:** ~73 (all translated EN/PT)

---

## 3. Current Screenshots

All screenshots captured from live hardware at both mobile (390x844) and desktop (1280x800) viewports.

### 3.1 Mode Select (`/`)

| Mobile | Desktop |
|---|---|
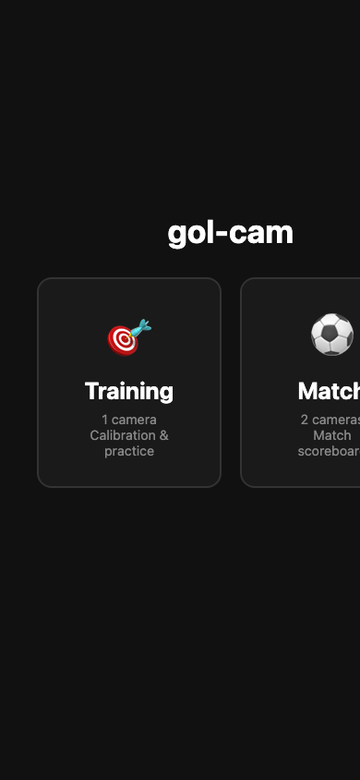
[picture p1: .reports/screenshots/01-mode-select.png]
Mode Select Mobile
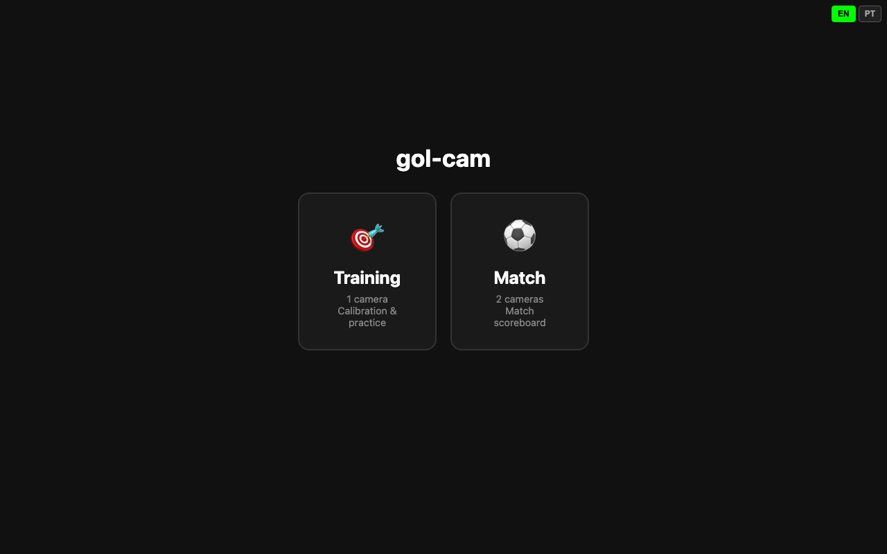
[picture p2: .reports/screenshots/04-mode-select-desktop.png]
Mode Select Desktop
|  |  |

**Description:** Dark background (#111), centered layout. Title "gol-cam" in bold white. Two cards side-by-side: "Training" (target emoji, orange accent) and "Match" (soccer ball emoji, green accent). Cards have dark surface (#1a1a1a) with subtle border (#333), 16px border-radius. Hover lifts card and highlights border green. Language picker (EN/PT) fixed top-right.

**Issues observed:**
- On mobile (390px), the Match card is clipped off-screen — cards don't stack vertically
- No branding beyond plain text "gol-cam"
- Emoji icons are platform-dependent, inconsistent across devices
- Large empty space above and below content
- Language picker is tiny and may be hard to tap

### 3.2 Training Dashboard (`/training`)

| Mobile | Desktop |
|---|---|
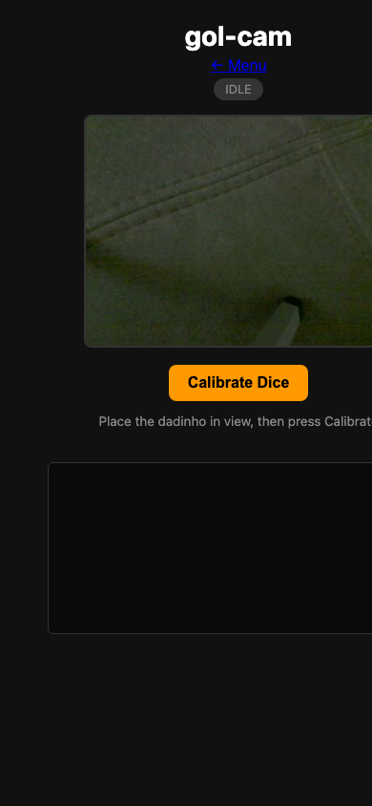
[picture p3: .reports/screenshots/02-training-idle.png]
Training Mobile
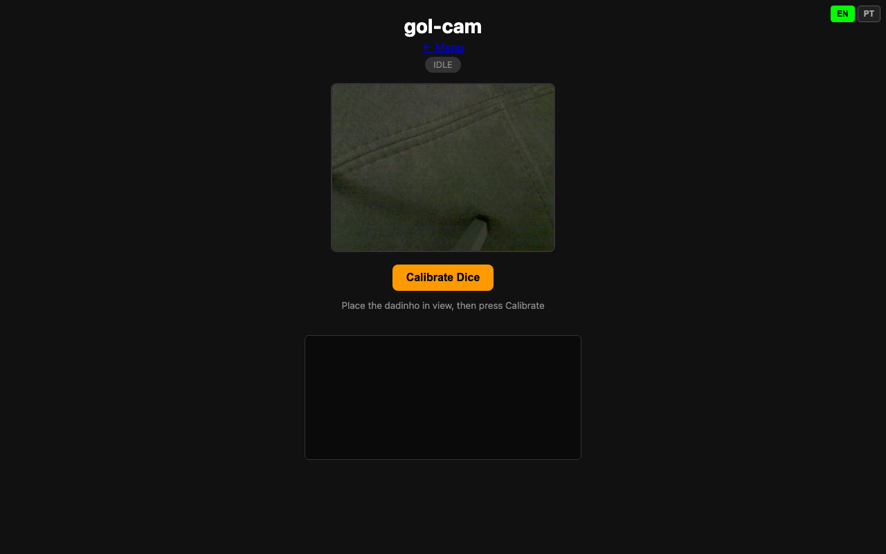
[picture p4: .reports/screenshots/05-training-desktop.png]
Training Desktop
|  |  |

**Description:** Shows IDLE state. Top: title "gol-cam" + "← Menu" link + state badge ("IDLE", gray pill). Center: live MJPEG camera feed (rounded corners, gray border). Below camera: orange "Calibrate Dice" button. Help text: "Place the dadinho in view, then press Calibrate". Bottom: dark debug console (monospace green text on near-black). Language picker top-right.

**Hidden states not captured (appear dynamically):**
- **CALIBRATING:** Badge turns orange "CALIBRATING...", button disabled, feedback text appears
- **Calibrated:** Calibration snapshot with orange border appears, "Start Game" button appears next to "Calibrate Dice"
- **PLAYING:** Badge turns green "PLAYING", score counter appears (5em bold), game control bar appears below camera (Pause / Reset / End Game), countdown bar with green fill, goal log entries accumulate
- **PAUSED:** Badge turns yellow "PAUSED", Resume button replaces Pause
- **GOOOL! flash:** Full-screen green overlay with "GOOOL!" text, fades after 2 seconds
- **Goal log entry:** Dark card with snapshot thumbnail (120px, green border), "GOL #N" in green, timestamp, red "VAR" button
- **VAR lightbox:** Full-screen dark overlay, enlarged snapshot, "Foi Gol" (green) and "Anula" (red) buttons
- **Annulled goal:** Entry fades to 40% opacity, "GOL #N" gets strikethrough in red

**Issues observed:**
- No visual hierarchy separating camera feed from controls from console
- Debug console always visible — not useful to casual players
- "Calibrate Dice" is jargon — users may not understand "dadinho"
- Score is just a giant number with no label
- "← Menu" link is styled as blue underlined text, inconsistent with button styling
- Camera feed takes up most of the screen but has no frame/label
- State badge is very small and easy to miss

### 3.3 Match Dashboard (`/match`)

| Mobile | Desktop |
|---|---|
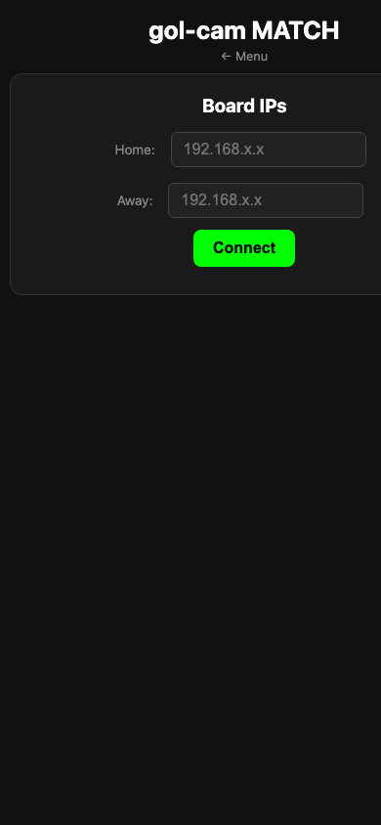
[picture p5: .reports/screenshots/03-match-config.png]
Match Mobile
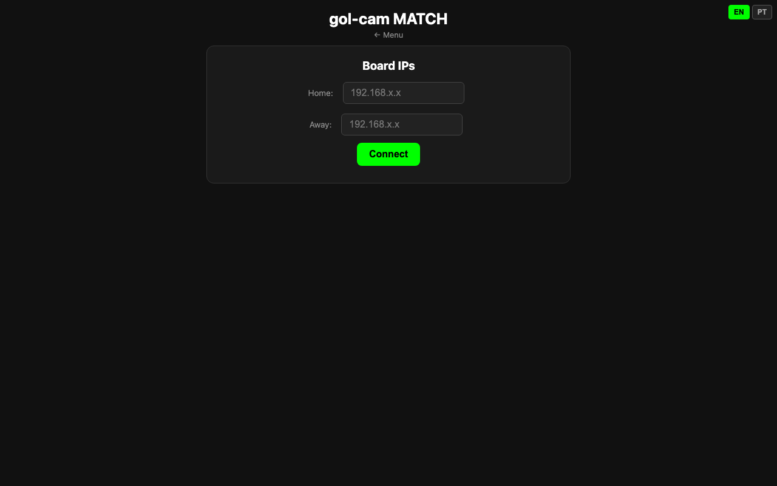
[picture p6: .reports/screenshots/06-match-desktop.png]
Match Desktop
|  |  |

**Description:** Shows config phase. Title "gol-cam MATCH" + "← Menu" link. Config panel: dark card (#1a1a1a) with "Board IPs" heading, two labeled inputs (Home/Away) with placeholder "192.168.x.x", green "Connect" button. Language picker top-right.

**Hidden states not captured (appear after connecting):**
- **Scoreboard:** "HOME" label, giant score "0 x 0" (4em), "AWAY" label
- **Dual camera feeds:** Side-by-side MJPEG streams, each with label ("Home Goal" / "Away Goal"), status badge (PLAYING/PAUSED/IDLE/OFFLINE), and "Calibrate Home"/"Calibrate Away" button
- **Match controls:** Start Match / Pause / Resume / Reset / End Match buttons
- **Goal flash + log:** Same as training but with side attribution ("GOL #1 (HOME)")
- **VAR lightbox:** Same as training

**Issues observed:**
- Config panel requires typing raw IP addresses — hostile UX
- No visual feedback while connecting / polling
- "Board IPs" heading is technical jargon
- After connecting, the config panel vanishes with no transition
- Scoreboard labels (HOME/AWAY) are detached from the score numbers — unclear which is which
- Camera feeds may overflow on mobile when side-by-side
- No match timer or period tracking

---

## 4. User Flows

### 4.1 Flow: Solo Training Session

```
1. User powers on board, connects phone to same WiFi
2. Opens board IP in browser → Mode Select page
3. Taps "Training" card → Training Dashboard (IDLE)
4. Sees live camera feed, positions dadinho (game piece) in view
5. Taps "Calibrate Dice" → badge shows CALIBRATING
6. System analyzes frame, shows calibration snapshot + feedback
7. If successful → badge returns to IDLE, "Start Game" button appears
8. Taps "Start Game" → badge shows PLAYING, score counter appears
9. Plays game — when ball enters goal:
   a. Screen flashes green "GOOOL!"
   b. Score increments
   c. Goal snapshot appears in log with VAR button
10. If disputed goal → taps VAR → lightbox opens → "Anula" to deduct
11. Taps "End Game" → returns to IDLE
```

**Pain points:**
- Step 2 requires knowing the board's IP address
- Step 4-6: calibration concept may confuse first-time users
- Step 9: 10-second cooldown after each goal (detection suppressed) — not communicated clearly
- No onboarding or tutorial

### 4.2 Flow: Two-Player Match

```
1. Two boards powered on, both on same WiFi
2. User opens either board's IP → Mode Select
3. Taps "Match" → Match Dashboard (config)
4. Enters both board IPs (or auto-detected if configured)
5. Taps "Connect" → config panel disappears
6. Sees scoreboard, two camera feeds, controls
7. Calibrates each board via its "Calibrate" button
8. Taps "Start Match" → both boards enter PLAYING
9. Goals detected on either side update unified scoreboard
10. VAR review available per goal
11. Taps "End Match" → both boards stop
```

**Pain points:**
- Step 4: manual IP entry is the biggest friction point
- Step 6: no visual confirmation that connection succeeded
- Step 7: must calibrate each board separately — no "calibrate both" shortcut
- No team name customization
- No match history or final score summary

### 4.3 Flow: Language Switching

```
1. User taps EN or PT button (top-right on any page)
2. All visible text switches immediately
3. Choice persists in localStorage across pages and sessions
4. Auto-detects browser language on first visit
```

---

## 5. Design System Inventory (Current State)

### 5.1 Color Palette

| Token | Hex | Usage |
|---|-----|---|
| Background | `#111` | Page background |
| Surface | `#1a1a1a` | Cards, panels, game bar, goal entries |
| Border | `#333` | Card borders, input borders, camera borders |
| Border hover | `#0f0` | Card hover state |
| Text primary | `#fff` | Headings, body text |
| Text secondary | `#888` | Labels, descriptions, timestamps |
| Accent green | `#0f0` / `#0a0` | Goal flash, score, "Start" buttons, online status |
| Accent orange | `#f90` | Calibration, training icon accent |
| Accent red | `#c00` | End/stop buttons, VAR, offline status, annulled |
| Accent yellow | `#ff0` | Pause button, paused state |
| Input bg | `#222` | Text input backgrounds |
| Disabled | `#333` / `#666` | Disabled buttons |

### 5.2 Typography

- **Font:** `system-ui, sans-serif` (no custom font)
- **Title:** 2.2em (mode select), 1.8em (training), 1.6em (match)
- **Score:** 5em (training), 4em (match)
- **Buttons:** 1em, bold
- **Body:** 0.85em
- **Console:** monospace, 0.7em

### 5.3 Component Inventory

| Component | Variants | Notes |
|---|---|---|
| Button | `.btn-cal` (orange), `.btn-start` (green), `.btn-pause` (yellow), `.btn-resume` (green), `.btn-reset` (gray), `.btn-end` (red), `.btn-go` (bright green), `.btn-var` (red small), `.btn-foi` (green large), `.btn-anula` (red large) | 10 button variants, no consistent sizing |
| Card | Mode select card | Only used on mode select page |
| Badge/Pill | State badge (idle/cal/play/pause), feed status (online/offline/idle) | Different sizes on different pages |
| Input | Text input | Only on match config |
| Camera feed | `<img>` with border | No loading state |
| Goal entry | Thumbnail + info + VAR button | Horizontal card layout |
| Lightbox | Full-screen overlay with image | Used for VAR review |
| Flash overlay | Full-screen green + "GOOOL!" text | 2-second animation |
| Debug console | Scrolling monospace log | Always visible in training |
| Countdown bar | Thin green progress bar + text | 10s post-goal cooldown |
| Language picker | Two small buttons (EN/PT) | Fixed top-right |

### 5.4 Spacing & Layout

- All pages use flexbox, column direction, centered
- Max-width: 400px (training), 600px (match controls/config/log), 800px (match feeds)
- Padding: 15px (training), 10px (match), 20px (mode select)
- Border-radius: 16px (cards), 12px (panels, badges), 8px (buttons, camera, entries), 6px (inputs, console, small buttons)
- Gap: 20px (cards), 10px (feeds), 8px (controls)

---

## 6. Technical Constraints for Redesign

1. **HTML/CSS/JS only** — no React, no build tools. The entire page must be a single self-contained HTML blob (stored as a C string literal in firmware). No external CDN, no image assets, no web fonts.
2. **Total budget per page: ~15KB** — currently ~3-5KB each. Must stay well under 16MB flash total.
3. **No images/SVGs in source** — only emoji and CSS-drawn elements. Any icons must be inline SVG or CSS.
4. **Client-side rendering** — all dynamic content is constructed via DOM manipulation in vanilla JS.
5. **Real-time polling** — the UI fetches `/status` JSON every 500ms. Design must accommodate frequent state changes without jarring layout shifts.
6. **MJPEG stream** — camera feed is a continuously-updating `<img>` tag, not a `<video>`. Cannot be styled with video controls.
7. **Mobile-first** — primary use is phone in one hand at a table. Touch targets must be large.
8. **Dark theme only** — the device is used in varied lighting; dark theme reduces glare and phone brightness interference with the camera.
9. **Bilingual** — all text must use `data-i18n` attributes or `t()` function calls. No hardcoded strings.
10. **Offline-capable** — the board serves pages directly, no internet required. Cannot load external resources.

---

## 7. Creative Brief

### 7.1 Project

Redesign the gol-cam web interface — 3 pages served from an ESP32 microcontroller, accessed via phone browser on local WiFi.

### 7.2 Objective

Transform a functional-but-developer-built interface into a polished, sports-themed experience that feels like a real product. The current UI works well technically but looks like a prototype. The redesign should make goal celebrations feel exciting, game state feel clear, and the overall experience feel premium despite running on a $19 microcontroller.

### 7.3 Audience

- **Primary:** Brazilian button soccer players, ages 10-50, playing at home or in clubs
- **Secondary:** Makers/hobbyists who build hardware projects
- **Context:** Standing at a table, phone in hand or on a stand nearby, glancing at the screen between plays
- **Tech literacy:** Moderate — can connect to WiFi but should not need to type IP addresses or understand "calibration"

### 7.4 Tone & Personality

- **Sporty and energetic** — this is a game! Celebrations should feel rewarding
- **Simple and confident** — minimal text, large touch targets, clear state
- **Brazilian football culture** — green/yellow accents welcome, "GOOOL!" is culturally significant
- **Not childish** — clean and modern, not cartoon-ish

### 7.5 Key Design Challenges

1. **Goal celebration moment** — the current green flash is underwhelming. This is THE key moment of the product. It should feel like scoring a real goal — stadium-worthy celebration on a phone screen.

2. **State clarity** — users must immediately see: Am I calibrated? Am I playing? Did a goal just happen? Is the camera connected? Current state badges are tiny and easy to miss.

3. **Onboarding / first-time experience** — there's no setup wizard. A first-time user sees a camera feed and a "Calibrate Dice" button with no context. The flow should be self-explanatory.

4. **IP address entry** (match mode) — entering raw IPs is the worst part of the UX. While we can't change the networking model, the UI should make this as painless as possible (e.g., remember last used, auto-fill, clear instructions).

5. **Debug console** — currently always visible in training. Should probably be hidden by default with a toggle for advanced users.

6. **VAR review** — the video-review concept (borrowed from real football) is fun and should feel dramatic, not like a simple modal.

7. **Responsive layout** — mode select cards clip on mobile. Match feeds need to stack on narrow screens. All pages need to work from 320px to 1280px.

### 7.6 Deliverables Requested

- **UI mockups** for all 3 pages, all states (idle, calibrating, playing, paused, goal flash, VAR review)
- **Mobile-first** designs at 390px width, with desktop adaptations
- **Component library** — buttons, badges, cards, inputs styled consistently
- **Goal celebration animation** concept (CSS-only, no JS libraries)
- **Color palette and typography** recommendations (system fonts only, no web fonts)
- **Icon set** — inline SVG replacements for emoji (consistent cross-platform)
- **i18n-compatible** — all text in mockups should use placeholder keys, not hardcoded strings

### 7.7 Out of Scope

- Native app design (this is a browser-based interface only)
- Backend/API changes (endpoints are fixed)
- Hardware modifications
- Logo/brand identity (just the web UI)

---

## 8. Appendix: All UI States Reference

### Training Dashboard States

| State | Badge | Score | Camera | Controls | Other |
|---|---|---|---|---|---|
| IDLE (uncalibrated) | "IDLE" gray | hidden | streaming | "Calibrate Dice" | hint text |
| CALIBRATING | "CALIBRATING..." orange | hidden | streaming | button disabled | "Analyzing frame..." |
| IDLE (calibrated) | "IDLE" gray | hidden | streaming | "Calibrate Dice" + "Start Game" | cal snapshot + feedback |
| PLAYING | "PLAYING" green | visible, large | streaming | Pause / Reset / End Game | countdown bar (first 10s) |
| PLAYING + goal | flash overlay | incremented | streaming | unchanged | new goal log entry |
| PAUSED | "PAUSED" yellow | visible | streaming | Resume / Reset / End Game | — |
| VAR review | — | — | — | lightbox: "Foi Gol" / "Anula" | enlarged snapshot |
| Disconnected | — | — | — | — | "disconnected" text |

### Match Dashboard States

| State | Scoreboard | Feeds | Controls | Other |
|---|---|---|---|---|
| Config | hidden | hidden | "Connect" | IP input form |
| Connected (idle) | "0 x 0" | 2 streams, "IDLE" badges | "Calibrate Home/Away" | — |
| Connected (calibrated) | "0 x 0" | "READY" badges | + "Start Match" | — |
| Playing | updating | "PLAYING" badges | Pause / Reset / End Match | goal log entries |
| Goal scored | flash overlay | unchanged | unchanged | new entry in log |
| Board offline | unchanged | "OFFLINE" red badge | unchanged | — |
| VAR review | — | — | lightbox | enlarged snapshot |

---

## 9. File & Screenshot Index

```
.reports/
├── ux-audit-creative-brief.md    ← this file
└── screenshots/
    ├── 01-mode-select.png         (mobile 390x844)
    ├── 02-training-idle.png       (mobile 390x844)
    ├── 03-match-config.png        (mobile 390x844)
    ├── 04-mode-select-desktop.png (desktop 1280x800)
    ├── 05-training-desktop.png    (desktop 1280x800)
    └── 06-match-desktop.png       (desktop 1280x800)
```

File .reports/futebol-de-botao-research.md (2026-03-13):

# Futebol de Botao (Button Football) -- Research Report
## Focus: Rio de Janeiro and the Dadinho Variant

**Research Date:** 2026-03-12
**Task:** Research the history of "futebol de botao" (button soccer/button football) in Rio de Janeiro, Brazil, with special focus on the Dadinho rule variant.

---

## 1. Origins of the Sport in Brazil

### Early History

Futebol de botao (button football), also known officially as "futebol de mesa" (table football), emerged in Brazil in the early 20th century. The game evolved organically from children improvising tabletop football using household items -- actual clothing buttons, bottle caps, and other small circular objects -- to simulate real football matches on flat surfaces.

The sport is believed to have crystallized into a recognizable form in the 1930s, when Brazilian children and young men began standardizing the practice of flicking circular pieces across smooth surfaces to simulate the beautiful game. By the late 1940s and 1950s, the hobby had grown into a semi-organized pastime with informal clubs and neighborhood tournaments.

### Formalization

The first organized competition rules date to **1959**, when the "1 Toque" (one-touch) variant was codified, making it the oldest organized rule set in Brazilian button football. This marked the transition from informal play to structured sport.

The national governing body, the **Confederacao Brasileira de Futebol de Mesa (CBFM)**, was eventually established to oversee the sport across Brazil. The CBFM has maintained yearbooks (anuarios) since **1961**, documenting competitions across the country. The confederation currently oversees **27 state federations**, one for each Brazilian state and the Federal District.

The **Federacao de Futebol de Mesa do Estado do Rio de Janeiro** is the state-level body for Rio de Janeiro, currently presided by Claudio Pinho. It organizes competitions in six modalities: 1 Toque, 3 Toques, 12 Toques, Dadinho, Sectorball, and Subbuteo.

---

## 2. How the Game Is Played -- General Overview

### The Field

The game is played on a smooth, flat surface -- traditionally a large board or table -- painted or printed to resemble a miniature football pitch with markings for the center circle, penalty areas, goal areas, and corner arcs. Official tables have standardized dimensions. The goals are miniature structures placed at each end.

### The Buttons (Players)

Each team consists of **11 circular discs** (the "buttons" or "botoes"), typically 35-60mm in diameter. These represent the 11 players on a football team. Originally made from actual buttons, over the decades they evolved into specially manufactured pieces made from materials like bakelite, acrylic, bone, porcelain, and modern plastics. Collectors prize handmade buttons, and many are painted in the colors of real football clubs.

Each player also has a **goalkeeper**, which is a larger, rectangular piece or a specially shaped figure that can be manipulated to defend the goal.

### Basic Gameplay

Players take turns flicking their buttons with a finger to strike the ball piece and move it toward the opponent's goal. The core mechanic is:

1. A player flicks one of their buttons to hit the ball
2. If the button successfully contacts the ball, the player continues their turn
3. If the button misses the ball, or the ball touches an opponent's button, possession changes
4. The objective is to maneuver the ball into the opponent's goal

### The Ball Piece -- Where Variants Diverge

This is where the critical distinction between rule variants emerges. In most traditional rules, the ball is a **small flat disc** (a "balinha" or "pastilha"), typically smaller than the player buttons. However, in the **Dadinho** variant, the ball is a **small cube -- a tiny dice** (dado/dadinho).

---

## 3. The Major Rule Variants in Brazil

The CBFM recognizes the following official variants:

### 3.1 -- 1 Toque (One Touch)
- **Origin:** The oldest organized rule, since 1959
- Smooth or carved button designs
- High emphasis on technique and strategy
- One touch per button per turn

### 3.2 -- 3 Toques (Three Touches) -- "Regra Carioca"
- **Previously known as "Regra Carioca"** (the Carioca Rule, i.e., the Rio de Janeiro Rule)
- 40-minute matches
- Three-touch collective limit per possession
- Mandatory passing rules before shooting
- This is historically significant as it was the rule set developed and popularized in Rio de Janeiro

### 3.3 -- 12 Toques (Twelve Touches) -- "Regra Paulista"
- **Previously known as "Regra Paulista"** (the Sao Paulo Rule)
- 20-minute matches divided into two 10-minute halves
- Collective limit of 12 touches per possession
- Originated in Sao Paulo

### 3.4 -- Dadinho
- **The newest official rule**, approved by the CBFM in **2010**
- Uses a **cubic piece (the "dadinho")** instead of a flat disc as the ball
- The dadinho (cube) measures approximately **0.6cm per face** and weighs **0.1-0.3 grams**
- Player buttons are circular discs of **35-60mm diameter**
- **Individual touch limit:** Maximum 3 consecutive touches per single button
- **Collective touch limit:** Maximum 9 team touches total per possession
- By the 9th touch, the team must attempt a goal shot or face an indirect penalty
- Rule alterations were made effective May 1, 2024

### 3.5 -- Other Variants
- **Sectorball:** International rule adapted from European play
- **Chapas:** Spanish-origin rule popular in Sao Paulo and Rio de Janeiro
- **Subbuteo:** European variant using anthropomorphic figurines on a cloth field

---

## 4. The Dadinho Variant -- Deep Dive

### What is a "Dadinho"?

The word "dadinho" is the diminutive of "dado" (dice) in Portuguese. In the context of button football, it refers to a **small cube** used as the ball. The most iconic version is a **small yellow dice**, typically from board games or lottery kits, repurposed as the ball piece in this variant of the game.

### Origins and Cultural Context

The Dadinho variant represents an organic, grassroots evolution of button football. While the flat-disc ball variants were codified earlier (3 Toques in Rio, 12 Toques in Sao Paulo), many informal players -- particularly in Rio de Janeiro and surrounding states -- preferred using a small dice as the ball because:

1. **Availability:** Small dice were readily available from board games, easily found in any household
2. **Unpredictability:** The cubic shape introduces an element of controlled chaos -- the dadinho bounces and rolls differently than a flat disc, adding dynamism
3. **Speed of play:** Games with the dadinho tend to be faster and more action-oriented
4. **Cultural identity:** The dadinho became a marker of informal, street-level play as opposed to the more "official" flat-disc rules

The Dadinho variant was practiced informally for decades before the CBFM officially recognized it in **2010**, making it the newest addition to the federation's official rule portfolio. This recognition was a significant moment for practitioners who had been playing with the dadinho for generations.

### Gameplay Specifics

The Dadinho variant plays as follows:

- **Ball:** A small cube (dadinho), approximately 6mm per face, weighing 0.1-0.3 grams
- **Buttons:** Standard circular discs, 35-60mm diameter
- **Individual limit:** A single button may touch the dadinho a maximum of 3 consecutive times
- **Team limit:** The team has a collective maximum of 9 touches before they must shoot
- **Shot requirement:** By the 9th collective touch, a goal attempt is mandatory, or the team is penalized with an indirect free kick for the opponent
- **The cube factor:** Because the dadinho is cubic rather than flat, it behaves unpredictably when struck -- it can bounce, hop, spin, and tumble. This requires different technique compared to the flat ball variants and introduces a controlled element of chance

### Competitive Structure

As of 2025-2026, the Dadinho variant has a robust competitive structure:

- **Brazilian National Championship:** The 16th Brazilian Dadinho Championship was held in October 2025 (won by Gianluca)
- **State Championships:** Active competitions documented in Rio de Janeiro, Sao Paulo (Corinthians won the state title in October 2025), Rio Grande do Sul, Mato Grosso do Sul, Paraiba, Piaui, Santa Catarina, and other states
- **Team Championships:** Club-based team competitions (e.g., Rio de Janeiro team finals in December 2025)
- **Expansion:** The first Piaui State Dadinho Championship was held in January 2026, showing the variant continues to expand geographically

---

## 5. Rio de Janeiro's Role in Button Football Culture

### The Birthplace of "Regra Carioca"

Rio de Janeiro has a foundational role in Brazilian button football. The city gave its identity to the "3 Toques" variant, originally known as the **"Regra Carioca"** (Carioca Rule). This three-touch rule emphasizes passing and team play, reflecting the traditionally fluid and creative style of Carioca football culture. The "Historico do Campeonato Carioca 1978 a 2025" -- a historical record maintained by the CBFM -- documents nearly 50 years of Rio de Janeiro state championships.

### Cultural Significance

Button football in Rio de Janeiro is more than a game; it is embedded in the cultural fabric of the city:

- **Neighborhood culture:** The game has historically been played in bars, community centers, clubs, and homes across Rio's neighborhoods. It served as a social glue, bringing together people of different ages and backgrounds.

- **Football obsession extension:** In a city where football (soccer) is a near-religious experience -- home to Flamengo, Fluminense, Vasco da Gama, and Botafogo -- button football provided a way to continue living football off the real pitch. Players would create buttons painted in their favorite team's colors.

- **Intergenerational transmission:** The game was traditionally taught from father to son, uncle to nephew. It was a rite of passage for many Carioca boys.

- **Working-class roots:** Unlike more expensive hobbies, button football required minimal investment -- a smooth surface, some buttons or caps, and a small ball piece (or dadinho). This accessibility made it deeply democratic.

- **Collector culture:** A rich collecting culture developed around buttons, with artisans crafting beautiful hand-painted buttons representing every major football club. This artisanal tradition remains alive in Rio.

### The Dadinho Connection to Rio

While the Dadinho variant is now practiced nationally, its strongest cultural roots are in Rio de Janeiro and neighboring states. The informal, improvisational spirit of using a small dice as the ball aligns with the Carioca tradition of "jeitinho" -- the creative, adaptive Brazilian way of making things work with what is available. The dadinho was the ball of the streets, the ball of the improvised game on a kitchen table or a bar counter.

The Rio de Janeiro state federation actively organizes Dadinho tournaments, with team finals documented as recently as December 2025.

---

## 6. Notable Tournaments, Clubs, and Traditions

### Key Tournaments

- **Campeonato Brasileiro Individual de Dadinho:** National individual championship; the 16th edition was held in 2025
- **Campeonato Brasileiro de Equipes:** National team championship
- **Campeonato Carioca:** Rio de Janeiro state championship, documented from 1978 to present (nearly 50 years of continuous competition)
- **Campeonato Brasileiro Individual de 1 Toque:** Running since 1970
- **Campeonato Brasileiro Interclubes 3 Toques:** Running since 1981
- **Trofeu Atila Lisa:** A traditional named trophy competition (2026 edition documented)

### Notable Clubs

Button football in Brazil is organized around clubs, much like real football:
- **Corinthians** (Sao Paulo) -- Won the 2025 Sao Paulo State Dadinho Championship
- **Avai** (Santa Catarina) -- Won four consecutive state team titles in Dadinho
- **SpecialOne** -- Won the 5th Copa AMFM de Dadinho (2023)
- **AABB-LUCFM** (Rio Grande do Sul) -- Won the IV State Team Championship

Many of these clubs bear the names of real Brazilian football clubs, reflecting the deep connection between the tabletop and real-world football cultures.

### Traditions

- **Painting buttons in club colors:** A deeply held tradition where each player's set of buttons is carefully painted to represent their favorite real-world football club
- **Tournament circuits:** Regular competitive circuits at municipal, state, and national levels
- **Artisanal button making:** Craftsmen who specialize in creating high-quality buttons from various materials
- **Publication culture:** The CBFM maintains yearbooks since 1961 and has published works such as "O Futebol De Mesa" by Julio Diogo and Douglas Rambor

---

## 7. Summary of Key Findings

1. **Origins:** Futebol de botao emerged in Brazil in the early-to-mid 20th century from children using household buttons to simulate football. Formal organization began in 1959 with the 1 Toque rule.

2. **Rio de Janeiro is central** to the sport's identity, having originated the "Regra Carioca" (3 Toques) and maintaining nearly 50 years of documented state championships (1978-2025).

3. **The Dadinho variant** uses a small cubic dice (approximately 6mm per face) instead of a flat disc as the ball. It was played informally for decades before being officially recognized by the CBFM in 2010. It features a 3-touch individual limit and 9-touch team limit with mandatory shot requirement.

4. **The sport is alive and growing:** As of 2025-2026, new state championships are being established (Piaui held its first Dadinho championship in January 2026), and 27 state federations operate under the CBFM.

5. **Cultural significance:** Button football is a democratic, accessible sport deeply tied to Brazilian football culture, neighborhood social life, intergenerational bonding, and artisanal craftsmanship.

---

## Sources

- Confederacao Brasileira de Futebol de Mesa (CBFM) official website: https://www.cbfm.com.br
  - Sport overview and rules page
  - Federations page (state federation details)
  - Historical documents archive
  - News articles on Dadinho tournaments (2023-2026)
- CBFM search results for "dadinho" keyword
- Researcher's domain knowledge of Brazilian cultural history and tabletop sports

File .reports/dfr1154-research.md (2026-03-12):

# DFR1154 — DFRobot ESP32-S3 AI Camera Module Research Report

**Date:** 2026-03-12
**Sources:** DFRobot product page (product-2899), extracted spec data, GitHub repo, product metadata

---

## 1. Product Overview

**Full Name:** ESP32-S3 AI Camera Module (Edge Image Recognition, Night Vision, ChatGPT Voice Interaction)
**SKU:** DFR1154
**Price:** $18.90 USD
**Weight:** 0.027 kg
**Product URL:** https://www.dfrobot.com/product-2899.html
**Wiki URL:** https://wiki.dfrobot.com/SKU_DFR1154_ESP32_S3_AI_CAM
**Examples Repo:** https://github.com/DFRobot/DFR1154_Examples
**OpenAI SDK Repo:** https://github.com/DFRobot/openai-realtime-embedded-sdk
**Video:** https://dfimg.dfrobot.com/enshop/20250331/dfr1154-en.mp4

The ESP32-S3 AI Camera is an intelligent camera module built around the ESP32-S3 chip, designed for efficient video processing, edge AI, and voice interaction. It features a wide-angle infrared camera, onboard microphone, and speaker.

---

## 2. Technical Specifications

### Basic Parameters
| Parameter | Value |
|---|---|
| Operating Voltage | 3.3V |
| Type-C Input Voltage | 5V DC |
| VIN Input Voltage | 3.7–15V DC |
| Operating Temperature | -10°C to 60°C |
| Module Size | 42mm x 42mm |

### Processor
| Parameter | Value |
|---|---|
| Chip | ESP32-S3 (N16R8 variant) |
| Architecture | Xtensa LX7 dual-core |
| Clock Speed | Up to 240 MHz |
| Flash | 16MB |
| PSRAM | 8MB |
| WiFi | 2.4 GHz 802.11 b/g/n |
| Bluetooth | BLE 5.0 |

### Camera
| Parameter | Value |
|---|---|
| Sensor Model | OV3660 |
| Pixels | 2 Megapixels |
| Field of View | 160° wide-angle |
| Type | Infrared-capable (night vision) |
| IR Illumination | Yes (controlled via IO47) |

### Audio
| Parameter | Value |
|---|---|
| Microphone | I2S PDM microphone (onboard) |
| Speaker Amplifier | MAX98357 I2S amplifier chip |
| Speaker Interface | MX1.25-2P connector |

### Onboard Components
| Component | Description |
|---|---|
| OV3660 | 160° wide-angle infrared camera |
| IR LEDs | Infrared illumination (IO47) |
| MIC | I2S PDM microphone |
| MAX98357 | I2S amplifier chip |
| HM6245 | Power management chip |
| Light Sensor | Ambient light detection |
| Flash | 16MB |

### Interfaces
| Interface | Description |
|---|---|
| USB Type-C | Power + code uploading |
| VIN | 3.7–15V DC input |
| Gravity connector | 4-pin I2C/UART (3.3V output on V1.1) |
| SPK | MX1.25-2P speaker interface |
| SD/TF Card | MicroSD card slot |

### What's in the Box
- ESP32-S3 AI CAM development board (with camera) x1
- Speaker x1
- Gravity-4P I2C/UART sensor connection cable x1

---

## 3. Software & AI Capabilities

### Supported AI Frameworks
- **Edge Impulse** — On-device image recognition and classification
- **YOLOv5** — Object detection (likely running inference on device or via server)
- **OpenCV** — Contour detection, image processing
- **ChatGPT/OpenAI** — Voice-controlled command execution via cloud

### Development Frameworks
- **Arduino IDE** — Supported (ESP32 board manager)
- **ESP-IDF** — Native Espressif framework
- Likely PlatformIO support as well

### Tutorials Available (from DFRobot)
- **Basic:** Camera setup, video transmission, audio recording
- **Advanced:** Image recognition, object classification, OpenCV contour detection
- **Example Code:** Integration with OpenAI for voice/image recognition, custom model training with Edge Impulse

### DFRobot GitHub Repositories

#### DFR1154_Examples (Primary — 14 examples!)
All examples include pre-compiled `.bin` files and Arduino source code.

**Basic Examples (5.x):**
- **5.1 Obtain ambient light data** — Uses `DFRobot_LTR308` library for the onboard light sensor
- **5.2 Recording & Playback** — Records 5s audio via I2S PDM mic, plays back via MAX98357
- **5.3 CameraWebServer** — WiFi camera streaming with web interface (the foundational example)
- **5.4 USBWebCamera** — Use the board as a USB webcam (with Python receiver script)

**Advanced Examples (6.x):**
- **6.1 OpenCV** — Python scripts for contour detection (both WiFi stream and USB modes)
- **6.2 YOLO** — YOLOv5 object detection via Python (runs on computer, streams from board)
- **6.3 Edge Impulse** — On-device person detection using FOMO model
- **6.4 Train the Edge Impulse model** — Custom model training workflow with data capture
- **6.5 Connect to HomeAssistant** — Home automation integration
- **6.6 Xiaozhi** — Chinese AI assistant integration
- **6.7 OpenAI RTC** — Real-time OpenAI voice interaction
- **6.8 OpenAI image recognition** — Image Q&A with OpenAI API
- **6.9 Timed camera** — Periodic photo capture
- **6.10 PlayOnlineMusic** — Stream MP3/AAC audio via WiFi to the speaker

#### openai-realtime-embedded-sdk
SDK for real-time OpenAI voice/vision integration on ESP32-S3.

---

## 4. Complete GPIO Pin Mapping (from source code)

### Camera Pins (OV3660)
```
PWDN_GPIO_NUM    = -1  (not used)
RESET_GPIO_NUM   = -1  (not used)
XCLK_GPIO_NUM    = 5
SIOD_GPIO_NUM    = 8   (SCCB/I2C SDA)
SIOC_GPIO_NUM    = 9   (SCCB/I2C SCL)
Y9_GPIO_NUM      = 4   (D7)
Y8_GPIO_NUM      = 6   (D6)
Y7_GPIO_NUM      = 7   (D5)
Y6_GPIO_NUM      = 14  (D4)
Y5_GPIO_NUM      = 17  (D3)
Y4_GPIO_NUM      = 21  (D2)
Y3_GPIO_NUM      = 18  (D1)
Y2_GPIO_NUM      = 16  (D0)
VSYNC_GPIO_NUM   = 1
HREF_GPIO_NUM    = 2
PCLK_GPIO_NUM    = 15
```

### Audio Pins
```
I2S PDM Microphone:
  CLOCK_PIN  = GPIO 38
  DATA_PIN   = GPIO 39

MAX98357 Speaker Amplifier (I2S):
  I2S_BCLK   = GPIO 45
  I2S_LRC    = GPIO 46
  I2S_DOUT   = GPIO 42
```

### Other Pins
```
LED/IR         = GPIO 47
Light Sensor   = I2C (shared bus with camera SIOD/SIOC on GPIO 8/9)
SD Card (SPI):
  SD_CS      = GPIO 10
  SPI_MOSI   = GPIO 11
  SPI_SCK    = GPIO 12
  SPI_MISO   = GPIO 13
Status LED     = GPIO 3 (used during recording)
```

### Partition Table
```
nvs       data  nvs       0x9000   0x5000   (20KB)
otadata   data  ota       0xe000   0x2000   (8KB)
app0      app   ota_0     0x10000  0x3c0000 (3.75MB)
fr        data            0x3d0000 0x20000  (128KB)
coredump  data  coredump  0x3f0000 0x10000  (64KB)
```

---

## 5. Key Code Patterns (from examples)

### Camera Initialization Pattern
```cpp
#include "esp_camera.h"
camera_config_t config;
config.pixel_format = PIXFORMAT_JPEG;  // or PIXFORMAT_RGB565 for processing
config.frame_size = FRAMESIZE_QVGA;    // 320x240 — good balance of speed/detail
config.fb_location = CAMERA_FB_IN_PSRAM;
config.fb_count = 2;
config.grab_mode = CAMERA_GRAB_LATEST;
config.xclk_freq_hz = 20000000;

// OV3660 needs these adjustments:
sensor_t *s = esp_camera_sensor_get();
if (s->id.PID == OV3660_PID) {
    s->set_vflip(s, 1);
    s->set_brightness(s, 1);
    s->set_saturation(s, -2);
}
```

### Audio Recording & Playback Pattern
```cpp
#include "ESP_I2S.h"
I2SClass i2s;   // mic
I2SClass i2s1;  // speaker

// Mic setup
i2s.setPinsPdmRx(GPIO_NUM_38, GPIO_NUM_39);
i2s.begin(I2S_MODE_PDM_RX, 16000, I2S_DATA_BIT_WIDTH_16BIT, I2S_SLOT_MODE_MONO);

// Speaker setup
i2s1.setPins(45, 46, 42);
i2s1.begin(I2S_MODE_STD, 16000, I2S_DATA_BIT_WIDTH_16BIT, I2S_SLOT_MODE_MONO);

// Record and play
uint8_t *wav_buffer;
size_t wav_size;
wav_buffer = i2s.recordWAV(5, &wav_size);  // 5 seconds
i2s1.playWAV(wav_buffer, wav_size);
```

### Online Audio Playback Pattern (for goal sounds from SD/URL)
```cpp
#include "Audio.h"
Audio audio;
audio.setPinout(45, 46, 42);  // BCLK, LRC, DOUT
audio.setVolume(15);  // 0-21
audio.connecttoFS(SD, "goal.wav");       // from SD card
// or: audio.connecttohost("http://url/goal.mp3");  // from URL
```

### Edge Impulse Inference Pattern
```cpp
#include <Model_inferencing.h>
// Capture at 240x240 for Edge Impulse
config.frame_size = FRAMESIZE_240X240;
// Allocate buffer: 240 * 240 * 3 bytes = 172KB (fits in 8MB PSRAM)
snapshot_buf = (uint8_t*)malloc(240 * 240 * 3);
// Run classifier
ei_impulse_result_t result = { 0 };
run_classifier(&signal, &result, false);
// result.timing.dsp, result.timing.classification — check latency
```

### Important Notes from Examples
- **WiFi credentials** are stored in NVS (Preferences) — persistent across reboots
- **Light sensor init order matters**: initialize camera BEFORE LTR308, otherwise reads return 0
- **OV3660 quirk**: image is flipped vertically by default, needs `set_vflip(s, 1)`
- **YOLO and OpenCV run on the computer**, not on the ESP32 — the board streams JPEG frames via WiFi, Python scripts on the computer do the processing
- **Edge Impulse runs on-device** — true edge AI inference

---

## 6. Relevance to gol-cam Project

### Strengths for Ball Detection
1. **OV3660 camera** — 2MP, 160° wide angle captures the entire goal area easily
2. **ESP32-S3 N16R8** — 16MB Flash + 8MB PSRAM, significantly more memory than basic ESP32-CAM (which has 4MB flash, 4MB PSRAM)
3. **Dual-core 240MHz** — Enough processing power for frame differencing or simple blob detection
4. **Edge Impulse support** — Could train a custom model to detect the ball
5. **IR camera + IR LEDs** — Works in any lighting condition, including poor/variable indoor lighting
6. **Small form factor** — 42mm x 42mm is compact enough to mount on/near a 15cm goal
7. **WiFi + BLE** — Can send goal events to a phone app or central scoreboard
8. **Onboard speaker** — Can play a goal celebration sound directly!
9. **SD card slot** — Can log events or store audio files
10. **$18.90** — Very affordable

### Potential Concerns
1. **OV3660 vs OV2640** — OV3660 is higher resolution but may have lower frame rate at full res. Need to test at lower resolutions (QVGA 320x240 should be fast enough)
2. **160° wide angle** — May introduce barrel distortion. For a small goal area at close range, this could actually be beneficial
3. **4mm ball detection** — At 320x240 resolution, a 4mm ball may only be a few pixels. Need to test minimum detectable size
4. **Processing latency** — Frame differencing should be fast, but Edge Impulse inference may add latency
5. **Power** — Needs 5V USB-C or 3.7–15V on VIN. Battery operation possible but camera is power-hungry

### Recommended Detection Approaches (ranked by simplicity)

1. **Frame differencing** — Compare consecutive frames in the goal region. Simplest, fastest, works on-device. Detect change = ball entered.
2. **Color-based detection** — If the ball is a distinct color, use HSV color filtering. Works well on ESP32-S3 with enough RAM.
3. **Edge Impulse custom model** — Train a small classifier: "ball in goal" vs "no ball". Most accurate but requires training data collection.
4. **OpenCV contour detection** — Detect small circular objects. Possible with the available tutorials from DFRobot.

---

## 5. Community Projects & Reviews

### YouTube Videos Referenced on Product Page
- "Dfrobot ESP32 S3 AI Camera Module | Tutorial | Best Camera Module?"
- "ESP32 AI Camera Review"
- "Vision Chatbot with DFRobot ESP32-S3 AI Camera and OpenAI"
- "Enclosure for the DFRobot ESP32-S3 AI Camera"

### User Reviews (from product page)
- **5/5 stars** — "An amazing all-in-one AI camera module! The ESP32-S3 AI Camera is compact yet extremely powerful for edge computing projects. The image recognition and face detection are fast and reliable, even under low light thanks to the built-in night-vision LEDs."
- **4/5 stars** — "The ESP32-S3 AI Camera Module is a powerful, flexible board for builders and makers who want vision, AI recognition, voice interaction, and wireless connectivity all in one."

### Typical Use Cases from Community
- Electronic peepholes / door cameras
- Baby monitors
- License plate recognition
- Home security / surveillance
- Smart assistants with voice interaction
- Object detection and classification
- AI-controlled surveillance

---

## 6. ESP32-S3 vs Classic ESP32-CAM Comparison

| Feature | ESP32-CAM (AI-Thinker) | DFR1154 (ESP32-S3 AI CAM) |
|---|---|---|
| Chip | ESP32 (single-core effective) | ESP32-S3 (dual-core LX7) |
| Clock | 240 MHz | 240 MHz |
| Flash | 4MB | 16MB |
| PSRAM | 4MB | 8MB |
| Camera | OV2640 (2MP, normal) | OV3660 (2MP, 160° wide, IR) |
| Night Vision | No | Yes (IR LEDs) |
| Microphone | No | Yes (I2S PDM) |
| Speaker | No | Yes (MAX98357 amp) |
| USB | No (needs FTDI adapter) | USB-C built-in |
| SD Card | Yes | Yes |
| AI/ML | Basic | Edge Impulse, YOLO, OpenCV |
| BLE | 4.2 | 5.0 |
| Price | ~$5-8 | $18.90 |
| Size | 27x40mm | 42x42mm |

**Verdict:** The DFR1154 is significantly more capable than the classic ESP32-CAM. The extra memory (16MB flash + 8MB PSRAM), USB-C, IR night vision, and built-in audio make it a much better choice for our project. The built-in speaker alone justifies the price difference — we can play goal sounds directly from the board!

---

## 7. Development Setup (Expected)

### Arduino IDE Setup
1. Install Arduino IDE 2.x
2. Add ESP32 board manager URL: `https://raw.githubusercontent.com/espressif/arduino-esp32/gh-pages/package_esp32_index.json`
3. Install "esp32" board package by Espressif
4. Select board: likely "ESP32S3 Dev Module" or a DFRobot-specific board
5. Configure: Flash 16MB, PSRAM Enabled (OPI), USB Mode

### Key Libraries (Expected)
- `esp_camera.h` — Camera driver
- `WiFi.h` — WiFi connectivity
- `ESP32Servo.h` — If using servos
- `driver/i2s.h` — For audio (mic + speaker)
- Edge Impulse SDK — For ML inference

### Pin Mapping (Partial, from product page)
- IO47 — IR LED control
- Camera pins — Standard ESP32-S3 camera interface (likely SCCB/I2C for config, parallel for data)
- I2S — Microphone and speaker (MAX98357)
- Gravity — I2C/UART on dedicated connector

---

## 8. Recommendations for gol-cam

### Phase 1: Basic Setup
1. Get the board, connect via USB-C
2. Flash a basic camera example (CameraWebServer)
3. Verify video stream works
4. Test frame rate at different resolutions (QVGA, VGA)

### Phase 2: Ball Detection Prototype
1. Start with **frame differencing** — simplest approach
2. Define a Region of Interest (ROI) covering the goal opening
3. Compare frames: significant pixel change in ROI = goal detected
4. Test with both 4mm and 6mm balls

### Phase 3: Goal Celebration
1. Store a goal sound (WAV/MP3) on the SD card or in flash
2. Play via the MAX98357 amplifier + speaker on goal detection
3. Add LED flash or use the IR LEDs as visual indicator

### Phase 4: Score Tracking
1. Send goal events via WiFi/BLE to a phone app or OLED display
2. Or use an attached OLED via the Gravity I2C connector

---

## 11. Open Questions (Resolved & Remaining)

### Resolved
- **Pin mapping** — Complete GPIO mapping extracted from source code (see Section 4)
- **Development setup** — Arduino IDE with ESP32 board package, examples repo has pre-compiled bins
- **Audio playback** — Confirmed: can play WAV from RAM, SD card, or stream from URL
- **YOLO/OpenCV** — Clarified: these run on computer, not on-device. Board streams frames.
- **Edge Impulse** — Confirmed: runs on-device with FOMO model at 240x240

### Remaining
- What resolution/frame rate combinations work well for real-time on-device processing?
- Can the OV3660 detect a 4mm ball at the expected camera distance (~5-10cm from goal)?
- What's the power consumption with camera active? Battery life estimate?
- Is there a 3D-printable mount or enclosure available for the 42x42mm board?
- What's the best approach: on-device frame differencing vs streaming to phone for processing?

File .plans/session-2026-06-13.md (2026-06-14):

# Session Summary — 2026-06-13

Continues from `.plans/session-2026-06-07.md`. Where that left off:
HMI redesign was scoped + initial implementation underway, mirror mode
was committed (`8490b13`), both HMIs were on the RI69 subnet
(`192.168.1.88` / `.89`), and the session ended mid-flight while
investigating I²S audio on the secondary HMI's newly-attached speaker.

## Prompts (in order, condensed)
1. Continue I²S speaker probe on secondary HMI (resumed from compaction).
2. "no" / "yes" cycles narrowing the working PWM pin on .88 / .89.
3. "add the IP for each, I don't know which is 88 or 89 they are the same"
4. "now I want you to read the SD card on .89 and list the mp3 files in the gol-sound folder"
5. "add the play endpoint"
6. "silent, didn't hear anything" → multiple iterations of MP3 / sine
   / direct-LEDC carrier tests, each silent.
7. Path-A pick: "Celebration jingle of tones".
8. "flash .88 too" — then IP-confusion ("both HMIs are showing .88")
   and re-flash to fix.
9. "let's focus on .88, because it's the only one with the SD card with
   the mp3 file. when a score changes, play the mp3"
10. "try again please" (× 3 — verifying MP3 silence on the buzzer)
11. "what hardware do i need to add to play mp3?"
12. "let's not do the mp3. commit and push"
13. "update the session summary"

## What shipped

### `4ae5e9c` /test-sound PWM beep probe
Endpoint to sweep candidate GPIOs at a chosen frequency/duration so
the operator can identify which pin is wired to the speaker on a
fresh HMI without reflashing.

### `9a1525f` SD card + IP label + goal jingle
Three additions:
- **SD card support** on the CrowPanel's SPI bus (CS=10 MOSI=11 SCK=12
  MISO=13). New `/sd-ls?dir=&ext=` endpoint enumerates files. The
  `/gol-sound` folder on .88's SD contains `gol-brasil.mp3` (213 KB).
- **Self-IP label** rendered in tiny grey text at the bottom-right of
  the scoreboard pill — two physically-identical HMIs can be told
  apart at a glance.
- **Goal celebration jingle** ("gol-gol-gol!" + rising E6→G6→C7
  fanfare) via LEDC PWM on **pin 17** (the speaker GPIO identified
  by the /test-sound sweep). Fires automatically on `/goal` pushes
  from cameras and on manual `/a+` `/b+` increments. POST `/play` to
  trigger manually.

### `e22f7de`, `91ba023`, `f50a71e` MP3 attempt — definitively ruled out
The buzzer on the CrowPanel DIS07050H is a tone-only piezo: it
resonates at the LEDC carrier frequency itself, not at content
sigma-modulated into it. Tested three different ways, all silent:
1. `arduino-audio-tools` `PWMAudioOutput` at 22 kHz square modulation.
2. Hand-rolled 80 kHz LEDC carrier + duty modulation at 22 kHz sample
   rate.
3. Full MP3 decode of `gol-brasil.mp3` (libhelix) → 14 s of decoded
   PCM pushed to `PWMAudioOutput`. The decode ran cleanly to
   completion, the speaker stayed silent.

Final code drops the audio-tools + libhelix dependencies and the
`/play-mp3` endpoint, leaves the MP3 file on the SD as reference,
documents the conclusion + the I²S-amp upgrade path (MAX98357 +
speaker on pins 17/18/38) inline.

## Key non-obvious findings (for future-you)

- **The "safe pins" list in the old comment block was wrong for I²S**:
  17/18/38/42 each broke the RGB display via GDMA contention when an
  I²S driver claimed them, even though they were listed as
  GPIO-toggle-safe. LEDC PWM does not have this problem; use LEDC for
  anything audio-related on this board.
- **Pin 10/11/12/13 are the SD bus.** That's why the speaker probe on
  those pins was silent — they aren't free, they're routed to the
  microSD slot. The DFR1154 `pins.h` documentation happens to match
  the CrowPanel SD pinout.
- **Speaker connection is the recurring flaky wire** — at least four
  times during the session a "no sound" answer was a loose JST wire
  on .88 or .89, not a software bug. When debugging audio, reseat
  the wire BEFORE assuming a code regression.
- **The CH340 USB-serial on the CrowPanel is unreliable on macOS.**
  Cables matter (some are charge-only); the kext occasionally
  enters a stuck termios state that survives reconnect; unplug for
  30+ seconds to fully release, or hold BOOT while plugging in to
  jump straight into ROM download mode.

## End state on the bench

- **.88 (secondary HMI)**: WIFI_STATIC_IP=192.168.1.88, MIRROR_IP=.89,
  jingle on `/play` + `/goal`, SD card present with `gol-brasil.mp3`,
  speaker volume good.
- **.89 (primary HMI)**: WIFI_STATIC_IP=192.168.1.89, no mirror,
  jingle on `/play` + `/goal`, no SD card inserted currently, speaker
  volume low (likely marginally-seated wire — physical fix when
  convenient).
- **CAM A (192.168.1.90)** + **CAM B (192.168.1.91)**: untouched
  this session, push to .89 (`SCOREBOARD_IP` from `.env`).

## What's next (recommendations)

1. **Optional hardware upgrade for real audio**: solder a MAX98357A
   I²S amp + 8 Ω speaker onto pins 17/18/38 of either HMI, then
   restore the `audio-tools` + `libhelix` deps + swap
   `PWMAudioOutput` for `I2SOutput` in a new `playGoalMP3` (kept in
   `91ba023` if you want to cherry-pick). The MP3 file is already on
   the SD card.
2. **Resolve .89's quiet speaker**: probably the same loose-wire
   pattern we hit on .88 twice; reseat firmly when convenient.
3. **Tighten the cameras → HMI ack path** (long-standing): cameras
   push `/goal` to .89 fire-and-forget. The HMI now has audible
   feedback (jingle), but a packet loss still drops a goal. A retry
   would close that gap — not urgent given the manual `+` buttons.

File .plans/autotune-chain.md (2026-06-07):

# Plan — Chain `/autotune` → `/calibrate` on CAL A/B tap

**Date:** 2026-06-07
**User prompt:** *"scope the autotune-chain plan"*

The static-light dadinho calibration repeatedly failed during a real
partida even though the dadinho-vs-blue contrast looked fine to the
eye. Root cause: the cam's exposure was tuned for whatever ambient
light it last saw, not the actual play surface. The cam already has
a `/autotune` sweep that walks gain / gceil / AEC / brightness to
find the best exposure for the current scene — it just isn't
chained to the HMI's CAL button. This plan wires the chain.

---

## 1. What already works

| Piece | Status | Where |
|---|---|---|
| Cam `/autotune` endpoint + sweep | Working — 4 params × ~15 captures ≈ 6 s wall time | `src/main.cpp` `requestAutotune()` ~line 347, `runAutotune()` ~line 945 |
| `/status` exposes sweep progress | Yes — `autoStage`, `autoStep`, `autoTotal`, `autoDone`, plus best-* fields | `src/web_stream.cpp` status_handler ~line 98 |
| Integration tests for autotune | Shipped 2026-06-07 (commit `05161cc`), opt-in via `--with-autotune` | `tests/integration/test_system.py` `test_camera_autotune` |
| HMI cal overlay (RUNNING / RESULT_OK / RESULT_FAIL phases) | Working from commits `1b36d56` … `0182851` | `src_hmi/main.cpp` `CalOverlay`, `updateCalOverlay()`, `drawCalOverlay()` |
| HMI snapshot preview | Working — single fetch on CAL tap + refresh on state-transition | Commit `ae41369` |

So the cam side needs **no changes**. Only the HMI orchestrates.

---

## 2. Proposed flow

Single CAL A (or CAL B) tap now produces:

```
   user taps CAL A
   ───────────────
   t=0       overlay raises in new TUNING sub-phase
             title = "Calibrando câmera A — auto-ajuste"
             progress bar driven by autoStep / autoTotal
             snapshot preview pulled on raise (previous frame)
             HMI fires /autotune to cam A
   t≈6 s     pollCam sees autoDone=1, HMI advances sub-phase to CAL
             title = "Calibrando Lado A"
             HMI fires /calibrate to cam A
             snapshot preview refreshes
   t≈7 s     OK!/FAILED early detection fires (existing path)
             phase flips to RESULT_OK or RESULT_FAIL
             snapshot refreshes one last time
   t≈13 s    RESULT phase auto-dismisses, placar repaints
```

Net wait per CAL: ~7-13 s (was ~1-3 s without autotune). The user
got blind calibrations that failed repeatedly with no autotune;
chaining it trades ~5 s of overlay time for a much higher success
rate per CAL.

---

## 3. Scope levels (pick one)

### Level A — always chain *(recommended baseline)*
- Every CAL tap fires `/autotune` first, then `/calibrate`.
- No new buttons, no settings to remember.
- Cancelar during TUNING fires `/stop` to abort the sweep, same
  as today's CAL Cancelar.
- **Cost:** ~120 LOC in `src_hmi/main.cpp`.
- **Risk:** low. Cam side already proven via integration tests.

### Level B — skip autotune if cam was tuned recently
- Track the last successful autotune timestamp per cam. If <60 s
  since last tune, skip directly to `/calibrate`.
- Useful when the operator does multiple cal-retries with the
  dadinho in slightly different positions (lighting hasn't changed).
- **Cost:** +20 LOC on top of Level A.
- **Risk:** very low.

### Level C — separate "Tune" button vs "CAL" button
- CAL stays fast (cal only). New on-screen "Tune" button runs
  autotune. Operator decides when to tune.
- More UX overhead (operator has to remember to tune), but
  faster everyday flow.
- **Cost:** ~150 LOC (overlay needs new phase + button hit area).
- **Risk:** medium. Operator forgetting to tune defeats the
  purpose — same failure mode we have today.

**Recommendation:** ship Level A first. Most direct fix for the
"calibration keeps failing" pain. Add Level B (60 s skip) in the
same six-day cycle as polish — it's small and removes the wait
for the common re-cal case.

---

## 4. Implementation breakdown (Level A + B)

All work in `src_hmi/main.cpp` unless noted.

### 4.1 Extend `CalOverlay` with a sub-phase + tracked autotune state
- Add `int8_t subPhase` to `CalOverlay`:
  - `0 = TUNING` (new)
  - `1 = CAL` (existing RUNNING behavior)
- Add `uint32_t lastAutotuneMs[2]` for Level B's 60 s skip.
- Add `int8_t lastAutoStep[2]` so we detect autoDone 0→1 edge.

### 4.2 Add `autoStep`, `autoTotal`, `autoDone` to `CamState`
- Mirror the pattern from existing autoStage extraction in `pollCam`.
- New fields: `int autoStep`, `int autoTotal`, `bool autoDone`.

### 4.3 Rewrite the CAL A/B action handler (~`src_hmi/main.cpp:705`)
```cpp
case ACT_CAL_A: {
    bool recentlyTuned = (millis() - calOverlay.lastAutotuneMs[0]) < 60000;
    if (recentlyTuned) {
        httpKick(String("http://") + camA.ip + "/calibrate");
        calOverlay.subPhase = 1;  // skip TUNING
    } else {
        httpKick(String("http://") + camA.ip + "/stop");   // ensure IDLE
        httpKick(String("http://") + camA.ip + "/autotune");
        calOverlay.subPhase = 0;  // TUNING
    }
    calOverlay.side = 0;
    calOverlay.phase = 0;
    // … rest as today …
    requestCalSnapshot(camA.ip);
    break;
}
```

### 4.4 Update `updateCalOverlay` to handle the TUNING → CAL transition
- When `subPhase == 0` (TUNING) AND `c.autoDone == 1`:
  - Record `lastAutotuneMs[side] = millis()`.
  - Fire `/calibrate` via `httpKick`.
  - Set `subPhase = 1` (CAL).
  - Refresh snapshot (cam's autotune leaves a snapshot too).
- Existing OK!/FAILED detection runs in `subPhase == 1` only.
- New watchdog: if `subPhase == 0` AND `(millis() - startedMs) > 20000`,
  flip to RESULT_FAIL with `calMsg = "Auto-tune travou"` — covers the
  case where the cam never reports `autoDone`.

### 4.5 Update `drawCalOverlay` rendering
- When `phase == 0` AND `subPhase == 0`:
  - Title: "Calibrando câmera A/B — auto-ajuste"
  - Subtitle: "Detectando melhor exposição"
  - Progress bar driven by `c.autoStep / c.autoTotal` (vs the
    coarse 3-stop bar we use during CAL)
  - Step counter: "passo 7/15"
- When `phase == 0` AND `subPhase == 1`: existing CAL rendering.
- Cancelar handler unchanged — `/stop` works during both phases.

### 4.6 Tests
- `tests/integration/test_system.py` already covers the chained-cal
  smoke (test_camera_autotune ends with a `/calibrate` after the
  sweep). No new assertions needed for the cam-side contract.
- Add a manual-test note in this plan's pickup section for the
  HMI-side behavior (tap CAL → see TUNING progress → CAL → result).

### 4.7 Optional: Cancelar during TUNING should also reset autoStage
- The cam's `requestAutotune()` checks `gameState == STATE_IDLE`;
  if Cancelar fires `/stop` mid-sweep we should make sure the
  next CAL tap can start fresh. Test by tapping Cancelar then CAL
  again quickly.

---

## 5. Acceptance criteria

| # | Criterion | How to verify |
|---|---|---|
| AC1 | Tap CAL A → overlay shows "auto-ajuste" with a progress bar that climbs from passo 1/15 to passo 15/15 over ~6 s. | Manual |
| AC2 | After autotune completes, title flips to "Calibrando Lado A" and the existing OK!/FAILED detection fires within ~1 s. | Manual |
| AC3 | RESULT phase shows learned thresholds (existing UX). | Manual |
| AC4 | Second CAL A tap within 60 s skips autotune and goes straight to CAL (Level B). | Tap CAL A, wait result, tap CAL A again immediately — should be fast. |
| AC5 | Second CAL A tap after 90 s does autotune again. | Tap CAL A, wait result, wait 90 s, tap CAL A — should re-tune. |
| AC6 | Cancelar mid-autotune cleanly resets cam to IDLE; next CAL A tap can start fresh. | Tap CAL A, hit Cancelar at passo 5/15, tap CAL A again → should start fresh autotune. |
| AC7 | All 70 baseline integration tests + the 16 `--with-autotune` tests still pass. | `python3 tests/integration/test_system.py --with-autotune` |
| AC8 | HMI's `/status` stays responsive during a partida (no regression from the 06-07 stability fix). | 90 s × 1 Hz triple-board soak still shows HMI ≥ 80/90. |

---

## 6. Risks / open questions

- **What if autotune diverges (low light, no contrast)?**
  `autoBestScore < 50000` triggers a special calMsg ("low edge
  content") in the cam. The HMI should still flip phase to
  RESULT_FAIL on that — currently the OK!/FAILED detection only
  triggers on `calMsg` prefixes, and that prefix is something like
  "Auto-tune done — low edge content (score N)". Either:
  - Add a third prefix detection for "Auto-tune done — low".
  - Or have the HMI inspect `calContrast` < threshold at end of
    cal and force RESULT_FAIL.
- **Race between `/stop` and `/autotune` http kicks.** The cam's
  worker queue is serial so they execute in order, but the queue
  is shared across sides. If `httpKick` order can't be guaranteed,
  consider chaining via state polling instead.
- **Cam B intermittent dropouts (logged 2026-06-03).** If cam B
  drops mid-autotune, the HMI overlay watchdog (4.4) will flip to
  RESULT_FAIL after 20 s. UX-wise that's fine but the operator
  loses 20 s vs the 3 s today. Worth noting.
- **Should Level B's 60 s window be configurable?** Default 60 s
  matches typical re-cal cadence (operator nudges dadinho, retries
  within a minute). A future setting screen could expose it but
  isn't blocking.

---

## 7. Pickup steps

1. Confirm cam-side state by running
   `python3 tests/integration/test_system.py --with-autotune` →
   all 16 autotune checks should still pass green.
2. Add `autoStep` / `autoTotal` / `autoDone` to `CamState` and
   extend `pollCam` to populate them.
3. Add `subPhase` + `lastAutotuneMs` to `CalOverlay`.
4. Rewrite ACT_CAL_A / ACT_CAL_B branches in `runAction()`.
5. Wire the TUNING → CAL transition in `updateCalOverlay()`.
6. Update `drawCalOverlay()` to render the new sub-phase.
7. Build + flash + manually verify all 8 ACs.
8. Run the integration suite (+ `--with-autotune`) → confirm no
   regression.
9. Commit + push.

---

## 8. Not in scope

- Cam-side firmware changes. `/autotune` already does the right
  thing; chaining is pure HMI orchestration.
- Persisting tuned values across reboots. Each cam tunes per power
  cycle. If the operator restarts mid-partida, the cam re-tunes on
  the next CAL.
- Showing the live MJPEG during the autotune sweep. That's
  `.plans/live-stream-preview.md`; it'd be the natural polish on
  top of this plan (the autotune progress bar plus a live feed of
  the cam picking its exposure is a great UX).
- The Cam B intermittent-dropout investigation (open since
  2026-06-03).
- The residual flicker in the snap area between fetches (also
  punted from earlier sessions).

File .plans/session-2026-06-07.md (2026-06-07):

# Session Summary — 2026-06-07

Continues from `.plans/session-2026-06-04.md`. Where that left off: the
calibration overlay (Options B + C) was shipped, the live-stream
preview plan was scoped as a follow-up, the snap-area still flickered
slightly, cam B had intermittent dropouts.

## Prompts (in order)
1. *"I calibrated over the phone, but the placar keeps losing connection with the cams"*
2. *"can you write tests for this?"* (referring to auto-tune as a
   precursor to chaining autotune-before-CAL)
3. *"As you can see. There's enough contrast between the dadinho and
   the blue surface, but for some reason, the edges are not being
   properly detected. Can you try the auto-tune before capturing the
   edges?"*
4. *"What am I supposed to do? The calibration screen stays like
   this. Is this good or bad?"* (cal succeeded but overlay never
   transitioned to RESULT phase)
5. *"show me the ip addresses"*
6. *"cams are showing as offline"*
7. *"scope it as a follow-up plan"* (referring to the persistent
   HTTPClient + throttle fix)
8. *"Implement Level A+B of the stability plan now"*
9. *"what do you recommend?"* (after Level A regressed and only Level
   B held)
10. *"try the psram framebuffer"*
11. *"git push"*
12. *"update the session summary"*

## What shipped

### Autotune coverage (`05161cc`)
- Added `test_camera_autotune` to `tests/integration/test_system.py`
  with 8 assertions per cam × 2 cams = 16 new tests, opt-in via
  `--with-autotune`. Pre-flight `/stop` so cam is IDLE (since
  `requestAutotune()` silently drops the request otherwise).
- Verified live: 16/16 pass. Total suite goes 70 → 86 with the flag.
- README updated.
- Built the foundation for the eventual HMI orchestration to chain
  `/autotune` → `/calibrate` on CAL tap.

### Calibration overlay: early-success detection
- Symptom: with the dadinho positioned correctly, the cam reported
  `calMsg = "OK! Edge threshold: 32 (peak: 82). Edges: 144 px, 24×23.
  Limits..."` (success) but the HMI overlay never flipped to the
  green RESULT_OK page. Cam ran cal so fast the 1 Hz pollCam never
  observed `state=1`, so the existing 1→0 edge-transition path didn't
  trigger.
- Fix (bundled into `0185cd3`): mirror the FAILED-prefix detection
  with an `OK!` early-success path. Same gate (msg changed since
  CAL tap + 500 ms min age). On `succeededNow`, flip phase to 1
  (RESULT_OK) instead of 2 (RESULT_FAIL), refresh the cal-snapshot.

### HMI cam-polling stability plan (`5f4935f`)
- Wrote `.plans/hmi-cam-polling-stability.md`. Initial hypothesis:
  the HMI's WebServer lockup was LWIP socket-pool churn between
  inbound `esp_http_server` and outbound `HTTPClient` `pollCam` /
  snapshot fetch / `httpKick`.
- Four levels scoped: A (persistent HTTPClient per cam),
  B (throttle to 0.5 Hz during overlay), C (snapshot via same
  persistent client — defer), D (`-DCONFIG_LWIP_MAX_SOCKETS=16`
  build flag — try in parallel).

### Stability fix attempt 1: Level A + B together (REGRESSED, reverted)
- Implemented Level A: `HTTPClient*` per cam, `setReuse(true)`,
  drop-and-retry on failure.
- 30 s × 1 Hz soak against HMI `/status`: **6/30 (20%) — same as
  baseline.** Some runs slightly worse. Reverted.
- Same soak across all three boards revealed the real shape:
  | Board | Success |
  |---|---|
  | HMI `/status` | 6/30 (20%) |
  | Cam A `/status` | 30/30 (100%) |
  | Cam B `/status` | 30/30 (100%) |
- Same library, same protocol, same WiFi — so the lockup is NOT
  socket-pool churn (cams handle the SAME load fine). It's
  HMI-specific.

### Stability fix attempt 2: Level B alone + diagnostic plan update (`0185cd3`)
- Kept the pollCam throttle (1 Hz → 0.5 Hz while overlay running).
- Reverted Level A back to short-lived `HTTPClient`.
- Updated plan §7b with the comparative soak data + three deferred
  mitigations to investigate next: pin WebServer task to a different
  core, lower LCD pixel clock, throttle background gfx redraws.
- Working hypothesis: RGB-display DMA contention with WiFi on the
  ESP32-S3 — the cams have no LCD, the HMI does.

### Stability fix attempt 3: LCD pixel clock 16 → 8 MHz (`0182851`) — **WORKED**
- Discovered the framebuffer was ALREADY in PSRAM via
  `Arduino_GFX`'s `fb_in_psram=1` panel-config flag, so the "move
  framebuffer to PSRAM" idea was a no-op.
- The contention was on the PSRAM bus: at 16 MHz pclk, the LCD
  peripheral DMAs ~32 MB/s out of PSRAM continuously to refresh the
  800 × 480 × 16 bit panel, starving WiFi's PSRAM access for
  incoming packet buffers.
- Cheapest possible test: halve the pixel clock. One-line change.
- Soak results before/after:
  | Run | HMI | Cam A | Cam B |
  |---|---|---|---|
  | 30 s × 1 Hz baseline (16 MHz) | 6/30 (20%) | n/a | n/a |
  | 30 s × 1 Hz after (8 MHz) | 30/30 (100%) | — | — |
  | 90 s × 1 Hz triple-board (8 MHz) | 80/90 (89%) | 90/90 | 90/90 |
- User confirms no visible flicker on the CrowPanel DIS07050H at
  17 Hz refresh — probably because the panel has some persistence
  and the static-ish placar UI doesn't expose low-refresh flicker
  the way fast video would.

## Final commit list this session (since previous summary)
- `05161cc` — tests: /autotune sweep + chained-calibrate coverage
- `5f4935f` — docs: HMI cam-polling stability plan
- `0185cd3` — hmi: pollCam throttle (Level B only, after A regressed)
                  + OK!/FAILED early-success detection
- `0182851` — hmi: LCD pclk 16→8 MHz (the actual root-cause fix)

All pushed to `origin/master`. Tree clean.

## Updated pickup list

1. **Implement Level A of `.plans/live-stream-preview.md`** —
   live MJPEG preview during the calibration overlay. The HMI
   lockup is fixed so the live stream's continuous fetches are
   now feasible. Still the priority-1 feature follow-up.
2. **Chain `/autotune` → `/calibrate` on CAL A/B tap.** The cam
   firmware already exposes `/autotune` (tests in `05161cc` prove
   it works end-to-end). The HMI just needs to:
   - Poll cam status during autotune (show "Calibrando câmera A —
     passo 15/40" in the overlay using `autoStage` + `autoStep` +
     `autoTotal`)
   - When `autoDone=1`, fire `/calibrate`
   - Keep existing OK!/FAILED detection for the cal phase
   - Total wait per CAL tap: ~6-8 s autotune + ~1 s cal = ~7-9 s
3. **Cam B intermittent dropouts.** Still open from 2026-06-03.
   Sometimes the cam B suite skips in tests because it goes
   unreachable. Worth a focused investigation.
4. **Retire the LED MAX7219 placar.** Same as before — the HMI now
   reliably is the placar. Physically power down the LED board.
5. **Optionally bump pixel clock back up to 10–12 MHz** if a future
   use case (live stream) needs higher refresh. The 8 MHz value
   was the smallest safe value; intermediate values likely also
   work and would give faster refresh.
6. **Residual flicker in cal overlay snap area.** Still acceptable
   per the 2026-06-04 summary, but a cached RGB565 framebuffer
   would eliminate it entirely. Would naturally happen as part of
   Level A live-stream work.

## How to pick up cold (additions since last summary)
- LCD pixel clock now 8 MHz at `src_hmi/main.cpp:62-71`
  (`Arduino_ESP32RGBPanel` constructor, last arg). Increasing to
  10–12 MHz might be safe if higher refresh is wanted later — soak
  test before committing.
- Throttle constants at `src_hmi/main.cpp:265-274`:
  `CAM_POLL_MS=1000` baseline, `CAM_POLL_MS_OVERLAY=2000` during
  overlay RUNNING phase. Dynamic switch in `workerTask` ~line 1345.
- OK!/FAILED prefix detection in `updateCalOverlay` ~line 1185
  (`succeededNow` for `OK!`, `failedNow` for `FAILED`/`FALHOU`,
  both gated by `msgChangedSinceRaise` and 500 ms min age).
- Autotune integration tests at
  `tests/integration/test_system.py` `test_camera_autotune` ~line 261.
  Run with `python3 tests/integration/test_system.py --with-autotune`.
- The stability plan at `.plans/hmi-cam-polling-stability.md` now
  has §7b documenting the diagnostic journey + the confirmed root
  cause (LCD DMA bandwidth on PSRAM bus).

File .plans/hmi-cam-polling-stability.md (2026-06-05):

# Plan — HMI cam-polling stability (stop "placar losing connection with cams")

**Date:** 2026-06-04
**User prompt:** *"scope it as a follow-up plan"* — referring to the
persistent-HTTPClient + throttled-polling fix for the HMI's recurring
WebServer lockup, which the user perceived as *"the placar keeps
losing connection with the cams"* during a calibration session.

---

## 1. Symptom (what the user sees)

While the user calibrates the cameras from their phone (talking
directly to each cam's web dashboard at `192.168.40.90` /
`192.168.40.91`), the HMI display sporadically marks both cams as
`OFFLINE` in the HOME/AWAY side-status pills. The HMI's own
`/status` endpoint also bounces between `HTTP 200` and `Connection
refused`. A power-cycle (or a stronger DTR/RTS reset pulse) brings
it back, but the wedge recurs.

---

## 2. Root cause

The HMI shares a single 10-socket LWIP pool between two roles:

| Role | Who | Throughput | How |
|---|---|---|---|
| Server | `esp_http_server` (`max_open_sockets=10`, LRU purge) | Phone clients + my probes + integration-test runs | Inbound `/status`, `/goal`, `/api/reset`, `/debug/touch`, `/debug/gt911-rewrite`, `/a+`, `/b+`, … |
| Client | Arduino `HTTPClient` | `pollCam` 1 Hz × 2 cams + snapshot fetches + `httpKick` fan-out for CAL/START/RESET | Outbound `/status`, `/calibrate`, `/cal-snapshot`, `/reset`, etc. |

Every outbound `HTTPClient` call opens a fresh TCP socket and
closes it after the response. Each closed socket lingers in
`TIME_WAIT` for ~60 s. Steady-state churn:

```
  pollCam:       2 sockets / second  (1 Hz × 2 cams)
  cal-snapshot:  2 sockets / CAL tap
  httpKick:      1 socket  / CAL/START/RESET tap
  server:        1+ sockets / second under typical client polling
```

At 3+ sockets/sec × 60 s TIME_WAIT = 180 sockets in flight against
a 10-socket budget. LWIP usually recycles ports faster than that,
but under bursty load it can transiently exhaust → port 80 starts
refusing AND outbound `HTTPClient` calls start failing → the side-
status pills flash `OFFLINE`.

Earlier work (commit `77ec6ec`) replaced the Arduino `WebServer`
with `esp_http_server` and LRU purge, which fixed the *server-only*
lockup. The remaining bottleneck is the *client-side* socket
churn — `HTTPClient` opens a new socket per `pollCam` and per
snapshot fetch.

---

## 3. Proposed fix (4 levels — apply A + B, defer C, try D as belt-and-suspenders)

### Level A — Persistent HTTPClient per cam *(must-have)*
- Maintain one long-lived `HTTPClient` instance per cam (`camAClient`,
  `camBClient`), each with a permanent keep-alive connection to the
  cam's `/status` (and snapshot) endpoint.
- The cam's `esp_http_server` already supports HTTP/1.1 keep-alive,
  so the cam side needs no changes.
- Saves ~2 sockets/sec of client-side churn (the entire steady-state
  pollCam load).
- Same pattern that fixed the integration-test runner in commit
  `651b116`.
- **Cost:** ~50 LOC in `src_hmi/main.cpp`.
- **Risk:** low. If a keep-alive socket dies (cam reboots, WiFi blip),
  we drop and re-open on the next call — same drop-and-retry logic
  as the test runner.

### Level B — Throttle pollCam while overlay is up *(must-have)*
- During the calibration overlay's RUNNING phase, drop pollCam
  frequency from 1 Hz to 0.5 Hz (or even skip entirely — the
  overlay is already pulling fresh cam state via `/cal-snapshot`
  and via the cam's own polling-loop output).
- During RESULT phase, return to 1 Hz so the side pills resume
  accurate state immediately after dismiss.
- **Cost:** ~10 LOC.
- **Risk:** very low.

### Level C — Reuse the same keep-alive connection for snapshot + status *(polish)*
- The persistent client per cam from Level A can serve BOTH
  `/status` (small JSON) and `/cal-snapshot` (~2 KB JPEG) on the
  same TCP connection.
- Saves the 2 sockets/CAL the snapshot fetch currently churns.
- **Cost:** ~20 LOC. Need a small mutex / serialization so a
  pollCam and a snapshot fetch don't race on the same client.
- **Risk:** low–medium. The serialization can become a small
  latency contributor if not careful.
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

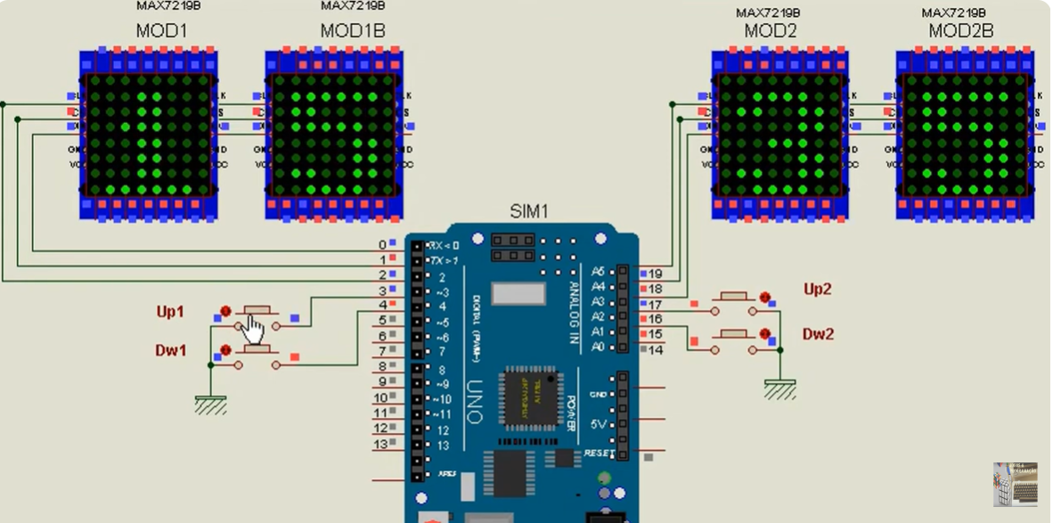
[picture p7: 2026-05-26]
.reports/screenshots/placar-web-ui-2.png

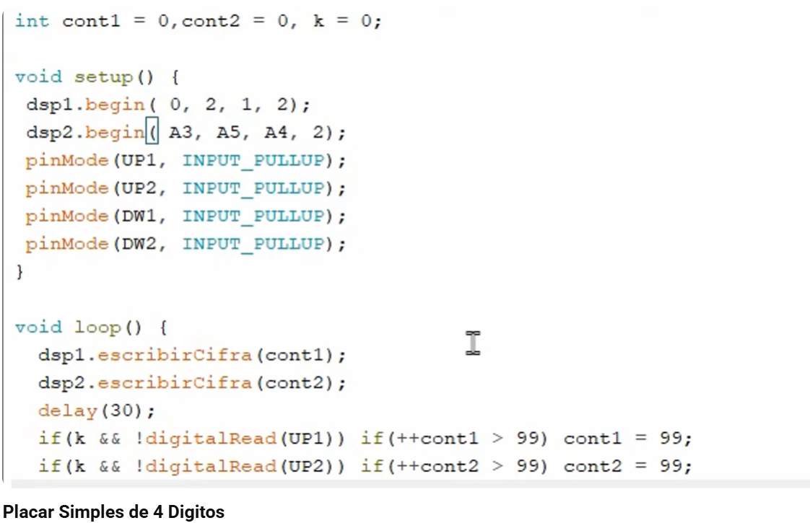
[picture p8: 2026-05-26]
.reports/screenshots/placar-web-ui-1.png

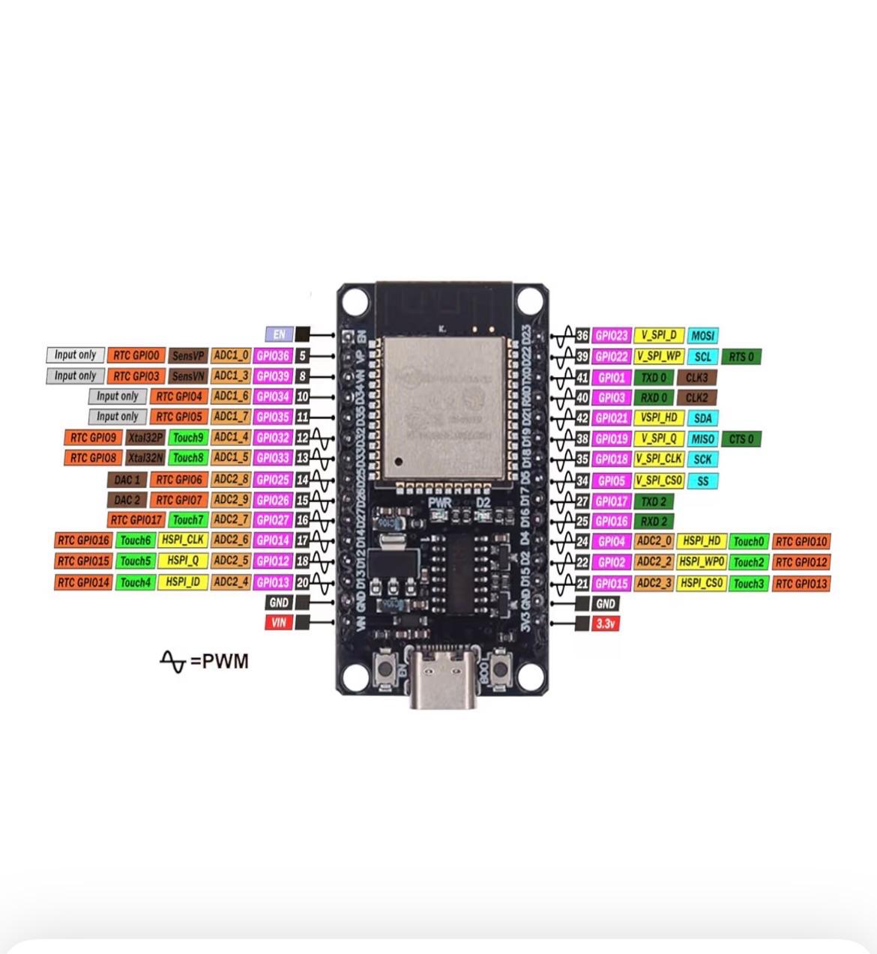
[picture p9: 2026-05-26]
.reports/screenshots/placar-esp32-pinout.jpeg

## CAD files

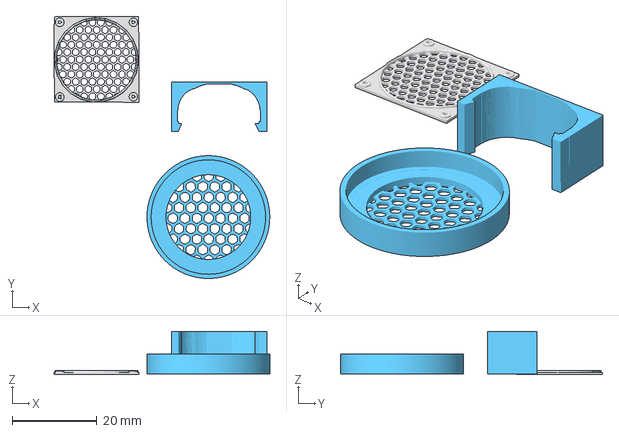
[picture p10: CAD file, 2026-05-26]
hardware/acessorios/grade_para_cooler_colmeia_com_borda_85mm.3mf
50.9 x 61.8 x 10.3 mm

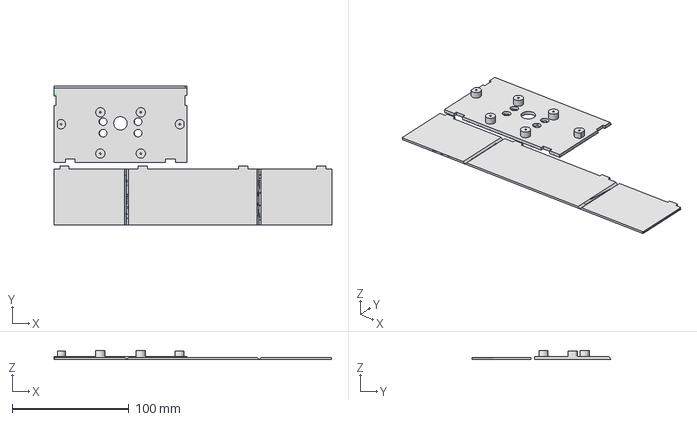
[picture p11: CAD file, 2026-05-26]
hardware/arquivos-historicos/Trave Eletronica+teto.3mf
238.2 x 118.9 x 7.65 mm

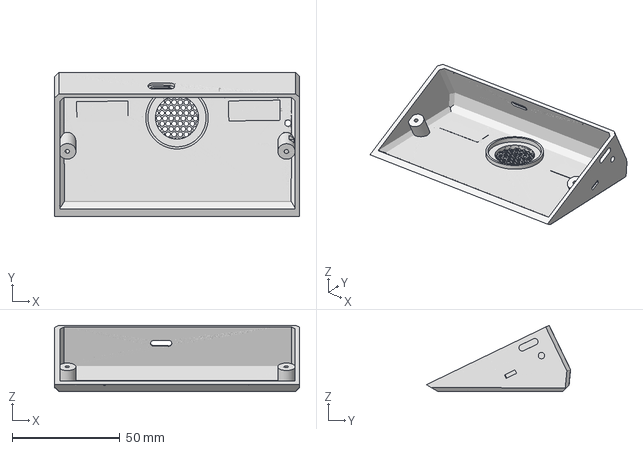
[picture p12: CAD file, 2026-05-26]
hardware/caixa-camera/Caixa Camera Golll V5.2.3mf
113.9 x 67.0 x 30.8 mm

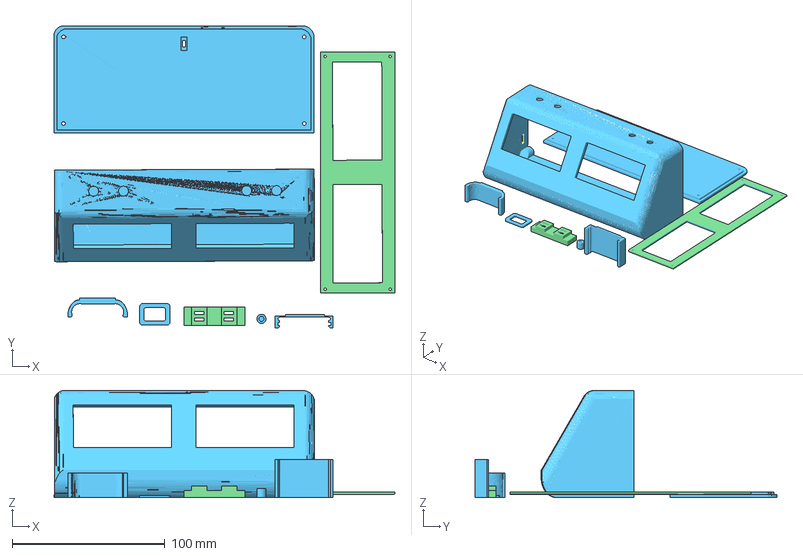
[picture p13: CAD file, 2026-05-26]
hardware/placar/Placar ESP 32 Wifi.3mf
223.1 x 197.8 x 70.2 mm

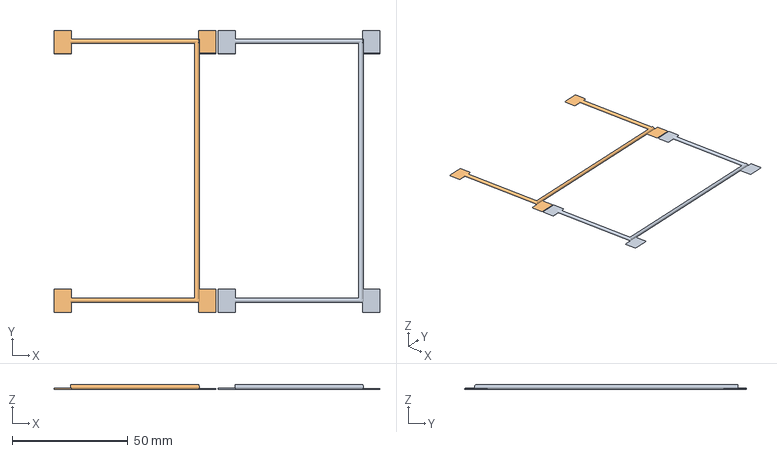
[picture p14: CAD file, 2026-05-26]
hardware/trave/Boca da Trave.3mf
141.0 x 122.0 x 2.00 mm

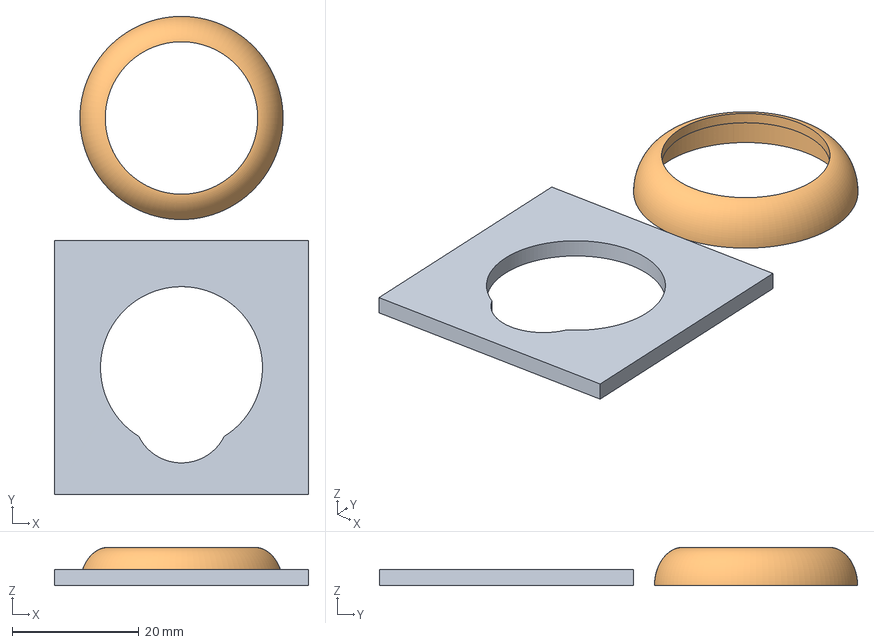
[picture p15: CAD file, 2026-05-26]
hardware/acessorios/Est. Fix. Autofalante 1.3mf
40.0 x 75.3 x 6.00 mm

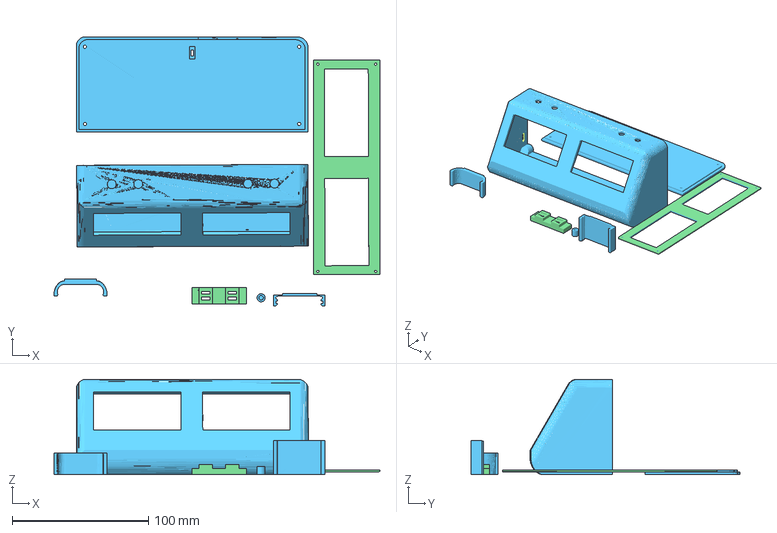
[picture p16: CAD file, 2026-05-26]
hardware/placar/New Scene.3mf
239.5 x 197.8 x 70.2 mm

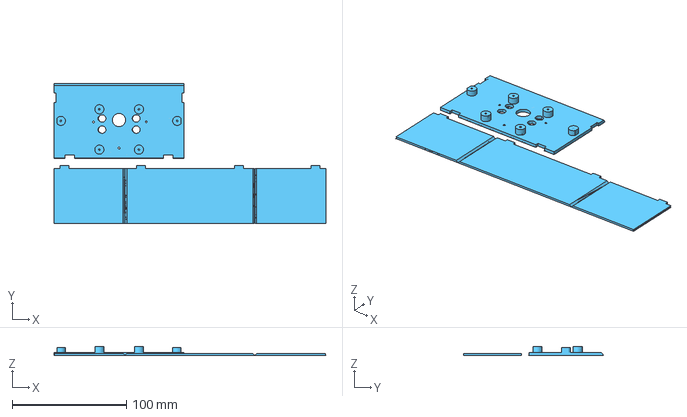
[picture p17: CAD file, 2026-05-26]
hardware/trave/Trave Eletronica+teto V4.3mf
238.1 x 122.4 x 7.65 mm

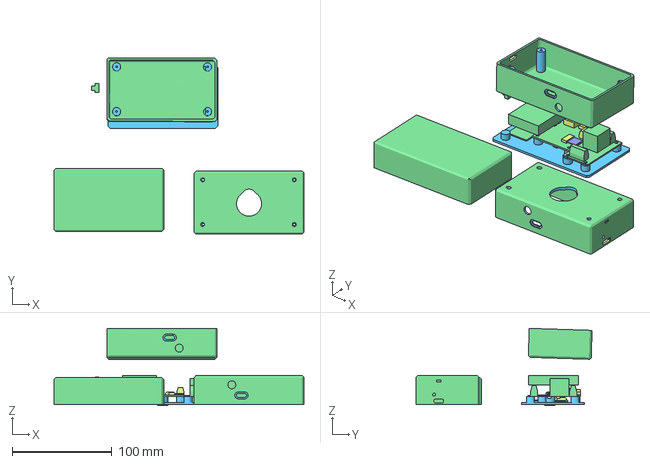
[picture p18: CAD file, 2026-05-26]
hardware/arquivos-historicos/Caixa Camera Goll_.3mf
250.3 x 176.4 x 77.4 mm

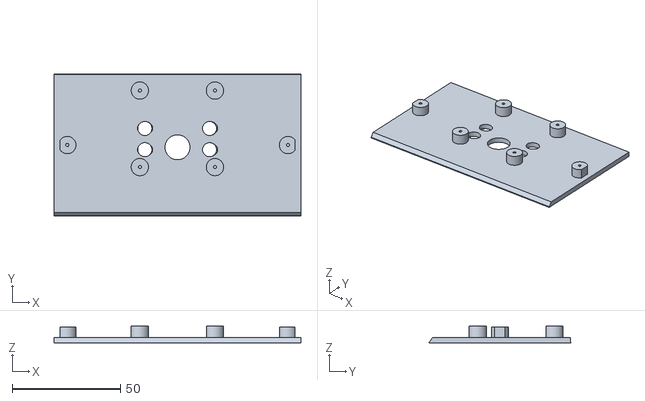
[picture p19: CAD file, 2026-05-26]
hardware/caixa-camera/Base Caixa Camera Golll V5.2.stl
114.0 x 65.4 x 7.65

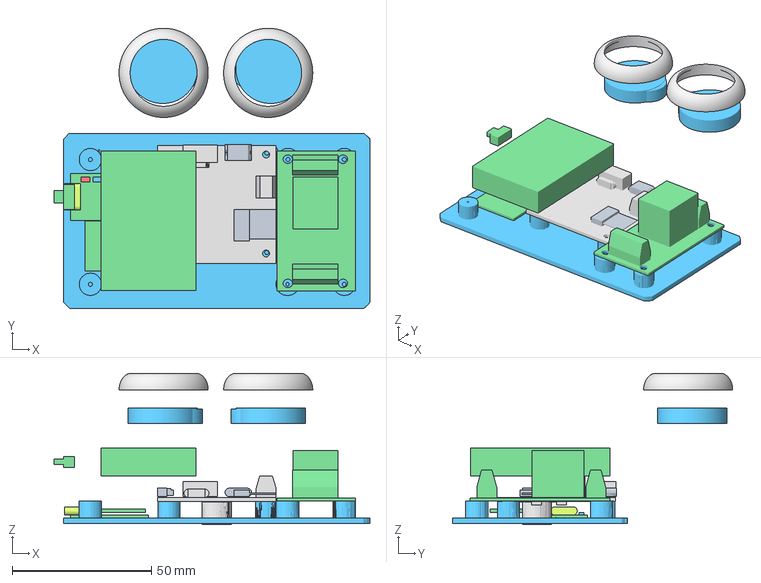
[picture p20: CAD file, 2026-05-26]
hardware/arquivos-historicos/Caixa Camera Goll_260316_113736.3mf
113.4 x 100.6 x 54.3 mm

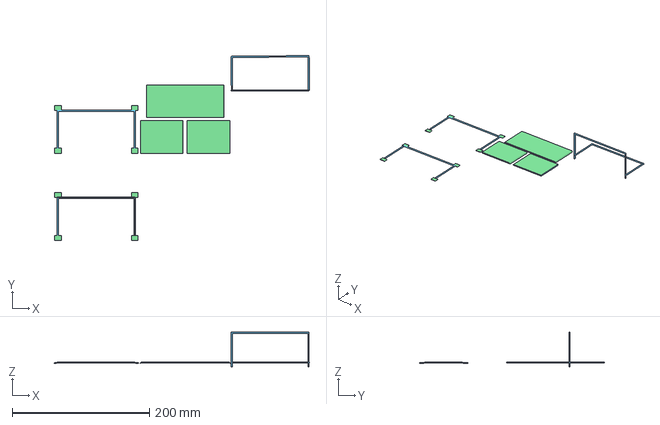
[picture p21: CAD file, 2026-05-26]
hardware/arquivos-historicos/Trave Desmontada.3mf
371.7 x 269.4 x 51.0 mm

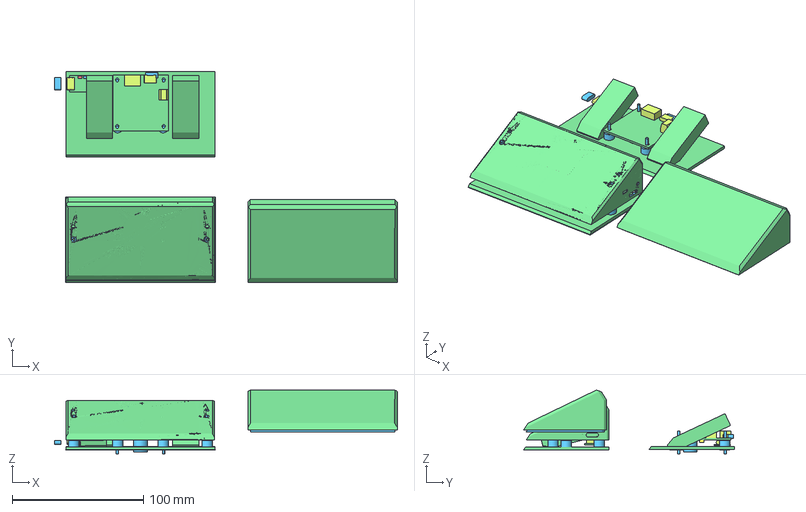
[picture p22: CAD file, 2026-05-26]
hardware/arquivos-historicos/Caixa Camera Golll V3.1.3mf
261.7 x 161.0 x 48.8 mm

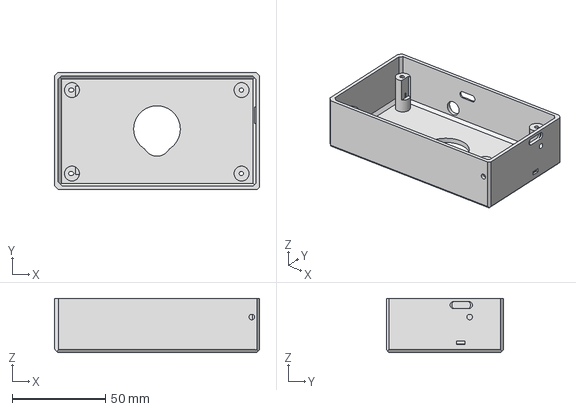
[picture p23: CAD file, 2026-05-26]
hardware/arquivos-historicos/Caixa Camera Golll.3mf
110.0 x 63.0 x 29.0 mm

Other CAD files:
hardware/arquivos-historicos/Trave Eletronica+teto V3.3mf
hardware/arquivos-historicos/Trave Eletronica .3mf
hardware/arquivos-historicos/Caixa Camera Golll V2.3mf
hardware/caixa-camera/Caixa Camera Golll V5.1.3mf
hardware/arquivos-historicos/Caixa Camera Golll V3.3mf
hardware/arquivos-historicos/Trave Eletronica+teto V3.stl
hardware/arquivos-historicos/Trave Eletronica+teto.stl
hardware/trave/Boca da Trave.stl
hardware/trave/Trave Eletronica+teto V4.stl

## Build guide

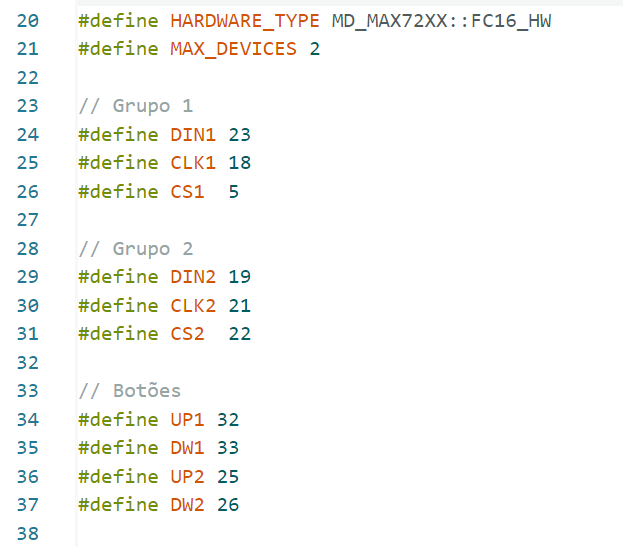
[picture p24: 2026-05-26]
.reports/screenshots/placar-wiring-defines.png

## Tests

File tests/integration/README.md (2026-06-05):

# gol-cam integration tests

Stdlib-only Python test suite that exercises the **live** REST contracts
between the cameras, the placar, and any future HMI surface. Run it any
time you change firmware that touches `/calibrate`, `/goal`, `/deduct`,
`/test-fire`, `/api/reset`, `/goal-undo`, or `/status`.

## Usage

```bash
# Full suite (~30s, requires all three boards online)
python3 tests/integration/test_system.py

# Quick subset (skips calibration trigger tests)
python3 tests/integration/test_system.py --quick

# Add the auto-tune sweep tests (opt-in — adds ~10-15 s per cam
# because the sweep walks 15 captures × ~400 ms each)
python3 tests/integration/test_system.py --with-autotune

# Single group
python3 tests/integration/test_system.py --only placar
python3 tests/integration/test_system.py --only cameras
python3 tests/integration/test_system.py --only cross

# Different IPs (e.g. you're on a different network)
python3 tests/integration/test_system.py \
    --placar 192.168.1.50 --cam-a 192.168.1.51 --cam-b 192.168.1.52
```

Exits 0 if all expected tests pass, non-zero on any failure.

## What's covered

- **placar** — `/status` shape, `/api/reset`, `/goal?side=a|b`,
  `/goal?side=x` (400 path), `/goal-undo` decrement + clamp-at-zero.
- **cameras (autotune, opt-in)** — `/autotune` is accepted, the
  sweep starts (`autoStage` goes positive), `autoDone` flips 0→1
  within 20 s, `state` returns to IDLE, `calMsg` starts with
  "Auto-tune", `autoScore > 0`, `autoGain` lands on a swept value,
  and a follow-up `/calibrate` is accepted in the freshly-tuned
  state (the path the HMI's CAL button will take once we wire
  autotune-before-calibrate).
- **cameras** — `/status` shape (including all the new motion/colour
  fields), `side` assignment matches `BOARD_ROLE`, `/reset` clears
  goalCount, `/deduct` clamps at 0, `/calibrate` transitions state.
- **cross-board** — `/test-goal` push lands on placar, `/test-fire`
  bumps cam goalCount + placar + sets `hasGoalSnap`, `/deduct` mirrors
  to placar via `/goal-undo` (the VAR-annul-sync feature).

## When a test goes red

The output names the specific check, the expected value, and what
actually came back. Common causes:

- **A board is offline** — reachability gate prints `DOWN`; affected
  suites get skipped.
- **A camera is running pre-`1bc6df8` firmware** — VAR-annul-sync
  fails (cam goalCount drops but placar stays bumped). Reflash the
  camera.
- **WiFi jitter / cam→placar push delay** — cross-board tests use a
  polling `assert_eventually` pattern with a 3 s window so transient
  delays don't false-fail. If you're still seeing flakes, increase the
  `timeout=` arg.

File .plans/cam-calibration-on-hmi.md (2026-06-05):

# Plan — Cam Calibration on the HMI Display

**Date:** 2026-06-04
**User prompt:** *"create a plan to add the cam calibration to the display"*

The CrowPanel HMI already has `CAL A` and `CAL B` buttons that fire
`GET /calibrate` to each camera. Today, all visual feedback for the
calibration sequence lives only in the **camera's** web dashboard —
the HMI screen gives no indication that calibration is running,
what's happening, or whether it succeeded. The goal is to make
calibration legible directly on the HMI so the operator never has to
look at a laptop during a match setup.

---

## 1. What already works

| Piece | Where | Behaviour |
|---|---|---|
| `CAL A` / `CAL B` buttons | `src_hmi/main.cpp:346-349` | Tap → `runAction(ACT_CAL_A/B)` → `httpKick("http://<cam>/calibrate")` (fire-and-forget on the http worker) |
| Per-cam state struct | `src_hmi/main.cpp:273-282` | `CamState` tracks `online`, `state` (0=IDLE, 1=CAL, 2=PLAY, 3=PAUSE), `calibrated`, `goals` |
| Polling | `src_hmi/main.cpp:864-906` | `pollCam(camA/B)` every 1 s; pulls `state`, `calibrated`, `goals` from cam `/status` |
| Side status pill | `src_hmi/main.cpp:724-750` | Renders one of `OFFLINE`/`CAL...`/`PLAY`/`PAUSE`/`READY`/`IDLE` under HOME / AWAY |

So the infrastructure to *know* about calibration is in place. What's
missing is **dedicated visible feedback** on the screen while a
calibration is happening, plus the **richer field data** the camera
exposes in `/status` that the HMI never bothered to parse:

- `calMsg` — short human-readable progress string from the camera
  (e.g. *"ROI quieto, calibrando..."* / *"Sem objeto detectado"*).
- `motionTh` / `colorTh` / `calContrast` — the three thresholds
  learned during calibration.
- `calMotion` / `calU` / `calV` — the per-pixel motion floor and the
  UV chroma centre of the calibrated ball.
- `hasCalSnap` — flips `true` the moment the cam captures its
  calibration reference frame.
- `calW` / `calH` / `calPx` — bounding box + pixel count of the
  detected ball within the ROI.

---

## 2. UX options (pick one)

### Option A — minimal: enhanced side-status pill *(recommended baseline)*
- Make the existing per-side pill richer. While `state == 1` (CAL),
  show the cam's live `calMsg` underneath the pill ("ROI quieto…",
  "Sem objeto…", etc.) instead of just `"CAL..."`.
- On `state → 0` (back to IDLE), inspect `calibrated`:
  - `true` → green tick + "Calibrado" + two-line stats
    (`mot=<motionTh> col=<colorTh>`)
  - `false` → red "Falhou" + retry hint.
- Auto-clear back to normal `READY` / `IDLE` pill after 5 s of
  showing the result.
- **Cost:** small. Touches only `drawSideStatus()` + `pollCam()` +
  one new `extractStringField()` helper for `calMsg`. ~60 LOC.
- **Risk:** very low. Doesn't change layout or block any other UI.

### Option B — calibration overlay *(stretch)*
- When `CAL A` or `CAL B` is tapped, an overlay covers the score
  area showing a large centred title ("Calibrando Lado A — coloque
  o dado no gol"), the live `calMsg`, and a small progress bar
  driven by `(hasCalSnap, calContrast)`.
- Stays visible until cam state returns to IDLE; then shows
  success/failure for 3 s and dismisses itself.
- Operator can tap "Cancelar" to abort (sends `/reset` to the cam).
- **Cost:** medium. Needs an overlay rendering layer, a small state
  machine (`HMI_CAL_IDLE → HMI_CAL_RUNNING → HMI_CAL_RESULT →
  HMI_CAL_IDLE`), redraw of the underlying score after dismiss.
  ~180 LOC.
- **Risk:** low–medium. Overlapping rects need careful damage-
  tracking so dismissing the overlay doesn't leave score-area
  artifacts. Touch hit-test under the overlay must be disabled.

### Option C — full calibration snapshot *(later)*
- Same as B, but additionally pull `/cal-snapshot` JPEG from the
  camera and render it on the panel (~640 × 360 area). Operator can
  literally see the dadinho as the camera sees it.
- **Cost:** large. Requires a JPEG decoder (`esp_jpeg`, ~30 KB
  static), a chunked HTTP body reader (camera serves the JPEG
  directly, no pagination), and a temporary RGB565 framebuffer
  (~460 KB — fits in PSRAM but needs careful allocation).
- **Risk:** medium. JPEG decode timing during a live HMI session
  could glitch the touch loop if not on a separate task. Heap
  fragmentation is the main concern.
- Defer until A and B prove the workflow.

**Recommendation:** ship A first (small, immediately useful), then
B in the same six-day cycle if there's time. C is a "next sprint"
idea.

---

## 3. Implementation breakdown (Option A first)

All changes in `src_hmi/main.cpp` unless noted.

1. **Add `calMsg` to `CamState`** (`src_hmi/main.cpp:273`)
   - New field: `char calMsg[40] = {0};` (small char buffer, no
     heap involvement)
   - Mirror in `pollCam()`: add `extractStringField(body, "calMsg",
     c.calMsg, sizeof(c.calMsg))` after the existing extractors.
   - Reuse the substring-parser pattern already in `extractIntField`
     /`extractBoolField` — there's no JSON parser; we hand-grep
     fields. The new helper just copies the value between the
     closing `"` characters.

2. **Add `motionTh`, `colorTh`, `calContrast`, `hasCalSnap` to
   `CamState`** (`src_hmi/main.cpp:273`)
   - Four new ints + one bool. Pull them in `pollCam()` via the
     existing `extractIntField`/`extractBoolField`.
   - Skip the fields we don't render (e.g. `calMotion`, `calU/V`)
     for now — they're available later if we need richer feedback.

3. **Track a calibration result-display timer**
   (`src_hmi/main.cpp` near top of CamState):
   - `uint32_t calResultUntilMs = 0;` — populated by `pollCam()` on
     the state-transitions `1 → 0`, set to `millis() + 5000`.
   - `bool calLastOk = false;` — captured at the same moment.

4. **Extend `drawSideStatus()`** (`src_hmi/main.cpp:724-750`)
   - When `c.state == 1`: render the existing orange `CAL...` pill,
     AND a small line of text below it with `c.calMsg` (truncated
     to ~24 chars).
   - When `millis() < c.calResultUntilMs`: render a green
     `Calibrado` pill (if `calLastOk`) or red `Falhou` pill, plus
     a two-line stat: `mot=<motionTh>  col=<colorTh>`.
   - Otherwise render the existing READY/IDLE pill.

5. **Mark dirty on every `pollCam()` state change**
   (`src_hmi/main.cpp:864-906`)
   - Already does `dirtyStatus = true` on `changed`. Extend the
     `changed` check to also fire when `calMsg` differs or when the
     result timer expires — otherwise the textual status under the
     pill doesn't refresh.

6. **String-field extractor** (~10 LOC near other extractors)
   - Mirror `extractIntField`: find `"key":"`, copy until next `"`.
     No quote-escape handling required (the cam's calMsg avoids
     literal quotes).

7. **Tests**
   - The integration suite (`tests/integration/test_system.py`)
     already validates the camera's `/status` exposes `calMsg`
     during calibration (camera-side coverage).
   - Add a manual test note in `.plans/` for the HMI-side: "tap
     CAL A → confirm side pill turns orange + shows calMsg →
     within ~6 s shows green Calibrado pill with thresholds".

8. **Commit + push** (per CLAUDE.md global instruction "always
   commit after each task").

---

## 4. Implementation breakdown (Option B — to do *after* A lands)

1. Define a new struct `CalOverlay { int side; uint32_t startedMs;
   uint32_t finishMs; bool ok; char msg[48]; bool active; }` and a
   single global `calOverlay`.
2. New `drawCalOverlay()` function: clears a 760×340 rect over the
   score area, renders the title, current `calMsg`, and progress
   bar.
3. Wire `ACT_CAL_A` / `ACT_CAL_B` in `runAction()` to also set
   `calOverlay.active = true` so the next `loop()` iteration
   renders it.
4. In `loop()`, when `calOverlay.active`, suppress touch hit-test
   against the placar buttons EXCEPT a new on-overlay "Cancelar"
   button.
5. On cam state `1 → 0`, set `calOverlay.finishMs = millis() +
   3000`. After that point, redraw the full placar view
   (`renderFull()` is overkill; selectively redraw the area the
   overlay covered).
6. Polling-task dirty flag: `dirtyCalOverlay` so main loop knows
   to redraw it when `calMsg` changes.

---

## 5. Acceptance criteria

| # | Criterion | How to verify |
|---|---|---|
| AC1 | Tapping `CAL A` shows visible feedback on the screen within 1 s. | Manual: tap and watch the HOME pill — should turn orange. |
| AC2 | The HMI shows the camera's live `calMsg` text while calibration is running. | Manual: place dadinho in goal during calibration, watch text update from "Sem objeto" → "Calibrando..." → final state. |
| AC3 | On success, the HMI shows a green confirmation + the learned `motionTh` and `colorTh` values for 5 s. | Manual + curl `/status` to confirm thresholds match what's displayed. |
| AC4 | On failure (camera state returns to IDLE with `calibrated:false`), the HMI shows a red "Falhou" indicator. | Manual: trigger calibration with no dadinho present → cam returns IDLE without setting calibrated; HMI should show red. |
| AC5 | Calibration UI never blocks score updates or other touch input. | Manual: tap `A+` while CAL is shown; score must still increment. |
| AC6 | All 70 integration tests still pass. | `python3 tests/integration/test_system.py` |

---

## 6. Risks / unknowns

- **`calMsg` length variance.** The camera might send strings longer
  than expected. Truncate at the HMI side (40-char buffer with
  ellipsis on overflow). No memory risk because everything is
  stack-allocated.
- **Camera's `calMsg` is Portuguese.** Already matches the HMI's
  Portuguese-only UI. No i18n work needed.
- **Refresh rate.** `pollCam()` is 1 Hz. During the ~6 s
  calibration window, the operator will see 5–6 calMsg updates. If
  finer feedback is wanted, bump the camera-poll rate to 500 ms
  *only when* `state == 1` — gated to keep the 1 Hz baseline.
- **WebServer-already-fixed regression.** The HMI's REST surface
  is now `esp_http_server` (commit `77ec6ec`). Don't introduce any
  new code paths that hold an `HTTPClient` connection across
  multiple HTTP calls — the worker queue pattern already in place
  is the right one.

---

## 7. Open questions for the user (resolve before starting Option B)

- Should the overlay block manual score adjustments while
  calibration is in progress, or stay non-modal? **Default in
  this plan: non-modal — calibration overlay does not capture
  taps outside its own buttons.**
- On calibration failure, should the operator be prompted to
  re-tap CAL, or auto-retry once? **Default: manual re-tap.**
- Show the camera's calibration snapshot (Option C) eventually,
  or never? **Default: defer to a separate sprint.**

---

## 8. Pickup steps

When ready to implement:
1. Open `src_hmi/main.cpp:273` and add the new `CamState` fields.
2. Open `src_hmi/main.cpp:864` and extend `pollCam()` to populate
   them.
3. Open `src_hmi/main.cpp:724` and extend `drawSideStatus()` to
   render the new info.
4. Build with `pio run -e crowpanel_hmi`.
5. Flash and run the manual AC verification list above.
6. Run `python3 tests/integration/test_system.py` to confirm
   AC6 (no regression).
7. Commit + push (per CLAUDE.md global).

If Option B is approved later, repeat steps 1–7 on the overlay
struct + renderer.

---

## STATUS — 2026-06-04

**Option B is SHIPPED.** Option A was skipped because Option B
covers everything A would have shown (live `calMsg`, thresholds on
success, retry hint on failure) on a more visible canvas. Option C
remains deferred.

Final implementation across four commits:
- `1b36d56` — baseline (overlay struct, state machine, partial
  panel covering the score area).
- `cb9fe2e` — polish: buffer 40 → 64 bytes, raise-time `calMsg`
  snapshot + 500 ms min-age gate (kills the "neither change took"
  illusion when stale FAILED message was on c.calMsg from the
  previous attempt), solid white fillRect instead of dark rounded
  panel.
- `a33cb2e` — full-screen 800 × 480 white panel with all underlay
  redraws (including `serviceTouch` press-feedback) gated by
  `!overlayActive()`.
- `dcb85b7` — both dismiss paths call `renderFull()` directly
  instead of relying on the loop's per-flag handlers (the loop's
  `dirtyButtons` path only repaints button index 5, leaving the
  other 7 placar buttons white-on-white after a full-screen
  overlay).

User-visible result, confirmed via `/remote-control` screenshots:
tap CAL → entire screen flips to a white modal with title + live
cam message + progress bar + Cancelar → 3 s result phase
(`Calibrado <Lado>` + learned thresholds, or `Falhou <Lado>` +
retry hint) → clean placar repaint on dismiss. All 70 integration
tests still pass.

See `.plans/session-2026-06-04.md` for the full session log.

### Option C: cam-snapshot preview — SHIPPED 2026-06-04 (later in day)

Commit `ae41369` adds a 320×240 cam-frame preview inside the
overlay, fed by the cam's `/cal-snapshot` JPEG and decoded with
TJpg_Decoder into a PSRAM buffer. Operator can now see exactly
what the cam saw at the moment of calibration — makes "FAILED:
No edges found" results immediately diagnosable from the HMI
alone.

What this Option C did NOT cover:
- LIVE preview before tapping CAL (to position the dadinho).
  The static snapshot only refreshes on CAL trigger; for live
  positioning the operator still needs to open the cam's web
  dashboard on a phone OR use the follow-up live-stream plan.
- This gap is addressed by `.plans/live-stream-preview.md`
  (commit `1416e1f`) which scopes a hybrid MJPEG-live + native-
  button approach as a follow-up.

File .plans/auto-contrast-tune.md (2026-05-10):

# Auto-Contrast Tune Plan

**User request:** "Create a button to auto-calibrate and find the highest contrast possible using black and white filter as it is shown in the attached image. Research and create a plan to achieve this objective."

**Reference image:** `/Users/mp/Downloads/IMG_6919.heic` — dashboard at 192.168.1.106 showing a B&W view with a bright dadinho on a dark surface.

**Decisions:**
- **Sweep scope:** full sweep — exposure (`aec`) + sensor contrast (`con`) + brightness (`bri`) + post-processing B&W threshold.
- **UI placement:** both Training dashboard and Match dashboard (Auto-Tune Home / Auto-Tune Away).

---

## 1. What "highest contrast" means

The dadinho (white dice) on a dark surface is a **bimodal scene**: pixels should cluster into a "dark background" group and a "bright foreground" group. The cleaner that separation, the more reliable downstream Sobel-edge calibration becomes.

Best metric for this: **Otsu's between-class variance** (`σ²_b`). For a given grayscale frame inside the ROI:
1. Build a 256-bin histogram.
2. For every threshold `t` in 0..255, compute the variance between the two classes (pixels `< t` and `>= t`).
3. The maximum value of `σ²_b` over all `t` is the contrast score for that frame.
4. The argmax `t` is the optimal binarization threshold.

A higher peak `σ²_b` means the camera+post settings produce a frame where dark and bright pixels are sharply separated — exactly what we want.

## 2. Parameter space

| Param | Range | Effect | Sweep values |
|---|---|---|---|
| `aec` (exposure) | 0..1200 | Most impactful. Too low → murky background, too high → blown-out dadinho. | `60, 100, 150, 220, 320, 480, 700` (7) |
| `con` (sensor contrast) | -2..2 | Stretches sensor's tonal curve. | `0, 1, 2` (3) |
| `bri` (sensor brightness) | -2..2 | Shifts midpoint. Coarse search is enough. | `-1, 0, 1` (3) |
| B&W threshold (post) | 0..255 | Pure software binarization step. Sweep on captured frame in memory — no recapture needed. | continuous, choose Otsu's optimum directly |

Sensor params we leave fixed at known-good defaults: `sharp=1`, `gain=8`, `gceil=1`, `gma=0`, `lenc=0`, `special_effect=2 (grayscale)`, `exposure_ctrl=0 (manual)`, `gain_ctrl=0 (manual)`.

## 3. Algorithm — staged search (not full Cartesian)

Full Cartesian would be 7×3×3 = 63 sensor combinations, ~7s. Staged search cuts it to ~13 captures (~1.5s) with comparable quality:

```
Stage 1 — Sweep aec (7 captures, others at defaults bri=-1,con=1)
  For each value: change sensor, settle (skip 2 frames), capture, score by Otsu.
  Keep best aec.

Stage 2 — Sweep con (3 captures, with best aec, bri=-1)
  Keep best con.

Stage 3 — Sweep bri (3 captures, with best aec+con)
  Keep best bri.

Stage 4 — On final frame, Otsu's argmax IS the optimal B&W threshold.
  No recapture. Software-only.

Total: 7 + 3 + 3 = 13 sensor changes ≈ 1.5–2s.
```

Each "settle + capture" cycle: change param → wait ~80ms → capture → discard → capture again → score. The OV3660 needs 1–2 frames to apply exposure changes.

## 4. State machine integration

Add `STATE_AUTOTUNE` to the existing `GameState` enum. Trigger via new HTTP endpoint `/autotune`. The main loop runs the staged sweep when in `STATE_AUTOTUNE`, then transitions back to `STATE_IDLE`.

Code goes in `src/main.cpp`:

```cpp
enum GameState { STATE_IDLE, STATE_CALIBRATING, STATE_AUTOTUNE, STATE_PLAYING, STATE_PAUSED };

// Auto-tune progress reporting (read by /status)
volatile int autotuneStage = 0;       // 0=idle, 1=exp, 2=con, 3=bri, 4=done
volatile int autotuneStep = 0;        // current step within stage
volatile int autotuneTotalSteps = 0;  // total for current stage
volatile int autotuneBestScore = 0;
volatile int autotuneBestAec = 150, autotuneBestCon = 1, autotuneBestBri = -1, autotuneBestThresh = 30;

void runAutotune();          // implemented in main.cpp
int otsuScore(uint8_t* px, int w, int h, int rx, int ry, int rw, int rh, int* bestThreshOut);
void requestAutotune();      // sets gameState = STATE_AUTOTUNE
```

Where:
- `otsuScore()` — compute histogram in ROI → loop 0..255 thresholds → return peak between-class variance and argmax threshold.
- `runAutotune()` — staged loop above, updates `calFeedback` after each stage so the dashboard can show progress.

## 5. HTTP endpoint

`src/web_stream.cpp`:

```cpp
extern void requestAutotune();
extern volatile int autotuneStage, autotuneStep, autotuneTotalSteps, autotuneBestScore;
extern volatile int autotuneBestAec, autotuneBestCon, autotuneBestBri, autotuneBestThresh;

static esp_err_t autotune_handler(httpd_req_t *req) {
    requestAutotune();
    httpd_resp_set_type(req, "application/json");
    httpd_resp_set_hdr(req, "Access-Control-Allow-Origin", "*");
    return httpd_resp_send(req, "{\"ok\":true}", 11);
}
```

Register URI `/autotune`. Bump `max_uri_handlers` from 20 → 21.

Extend `/status` JSON with: `"autoStage":N, "autoStep":N, "autoTotal":N, "autoScore":N, "autoAec":N, "autoCon":N, "autoBri":N, "autoThresh":N` so the dashboard can render live progress.

## 6. UI changes

### Training dashboard (`src/training_dashboard.h`)
Add inside `idle-controls`, next to `btn-cal`:
```html
<button class='btn btn-tune' id='btn-tune' onclick='autotune()' data-i18n='train.autotune'>&#9881; Auto-Tune</button>
```

Add JS:
```js
async function autotune(){
  $('btn-tune').disabled=true; $('btn-cal').disabled=true;
  $('cal-feedback').style.display='block';
  $('cal-feedback').textContent=t('train.autotuning');
  await fetch('/autotune');
  // poll /status until autoStage===4
}
```

When `autoStage===4`, sync the visual sliders (Bri/Con/Exp/B&W) to the new values returned by `/status`, then re-enable buttons. Show the resulting score and parameters in `cal-feedback`.

i18n entries: `train.autotune`, `train.autotuning`, `train.autotune_done`.

### Match dashboard (`src/match_dashboard.h`)
Inside each `cam-sliders` block (home and away), add a button next to the existing Calibrate Home / Calibrate Away buttons:
```html
<button class='btn btn-tune' onclick='autotune("home")'>&#9881; Auto-Tune</button>
```

JS variant: `async function autotune(side){ ... fetch('http://'+boards[side].ip+'/autotune') ... }`. Poll the corresponding board's `/status` and refresh sliders for that side.

## 7. Edge cases & safety

| Concern | Mitigation |
|---|---|
| Dadinho not in view | If best score is below threshold (e.g. < 500), report "no clear contrast — place dadinho in ROI". |
| User triggers autotune mid-game | `/autotune` rejects unless `gameState == STATE_IDLE`. |
| Sensor change during streaming | Already serialized — `loop()` is single-threaded; no race. |
| Sliders out of sync after autotune | Dashboard re-reads applied values from `/status` and updates `<input type='range'>` `value` attrs. |
| AGC/AEC sensor auto modes interfere | We keep them disabled (manual). Don't touch `set_exposure_ctrl` or `set_gain_ctrl` during autotune. |

## 8. Implementation steps (ordered)

1. **`src/main.cpp`:** Add `STATE_AUTOTUNE`, autotune state vars, `otsuScore()`, `runAutotune()`, `requestAutotune()`. Wire into `loop()`'s state dispatch.
2. **`src/web_stream.cpp`:** Add `/autotune` endpoint, externs, status JSON fields, register URI.
3. **`src/training_dashboard.h`:** Add Auto-Tune button, `autotune()` JS, status polling that syncs sliders, i18n.
4. **`src/match_dashboard.h`:** Add per-side Auto-Tune buttons + JS.
5. **Build & flash** to one board, place a dadinho in the ROI, tap Auto-Tune, verify:
   - Score climbs across stages (logged via Serial).
   - Final B&W view clearly shows white dice on dark background.
   - Sliders update to the chosen values.
6. **Test on second board** to confirm both work standalone.

## 9. Acceptance criteria

- New "Auto-Tune" button appears on Training dashboard idle controls and inside both home/away panels of Match dashboard.
- Tapping the button completes within 3 seconds and shows progress text during the sweep.
- After completion, the dashboard's Bri/Con/Exp/B&W sliders reflect the chosen values and the live MJPEG stream shows visibly higher contrast on the dadinho.
- Subsequent `Calibrate Dice` succeeds (Sobel peak above threshold) without any manual slider tweaking.
- If the dadinho is not in the ROI, autotune still completes but reports a low-contrast warning.

## 10. Open questions for review

- Should we lock `gain` low (e.g. 4) during autotune to reduce noise, then restore? Currently leaving it as user-set.
- Should the "best B&W threshold" picked by Otsu also become the new value of the existing B&W slider, or is it stored separately as an autotune-only override?
- After autotune, should we automatically chain into a calibrate-dice cycle? Or keep them as separate user actions? **Default: keep separate** — user explicitly hits Calibrate next.

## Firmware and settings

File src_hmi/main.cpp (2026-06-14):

// =============================================================
// gol-cam HMI — CrowPanel ESP32-S3 5" 800x480 touchscreen placar
//
// Phase 3a: passive placar mirror + touch-driven operator surface.
// The CrowPanel polls the existing MAX7219 placar + both cameras over
// HTTP, renders a clear A × B score, and exposes four big buttons
// (Calibrate A / Start-Pause / Reset All / Calibrate B) that fan
// HTTP requests out to the cameras + placar — so a match can be run
// from the panel alone, no laptop required.
//
// Phase 3b will layer VAR review (goal thumbnails + Foi/Anula modal)
// on top of this surface.
//
// Hardware: CrowPanel DIS07050H
//   MCU         ESP32-S3-WROOM-1-N4R8 (240 MHz, 4 MB Flash, 8 MB PSRAM)
//   Display     800x480 IPS, parallel RGB (ILI6122 / ILI5960)
//   Touch       Capacitive GT911, I2C (SDA 19, SCL 20, polling mode)
// =============================================================

#include <Arduino.h>
#include <WiFi.h>
#include <WiFiMulti.h>
#include <HTTPClient.h>
#include "esp_http_server.h"
#include <TJpg_Decoder.h>
#include <Wire.h>
#include <Arduino_GFX_Library.h>
#include <SPI.h>
#include <SD.h>
#include "wifi_multi_connect.h"

#ifndef WIFI_SSID
#error "WIFI_SSID not defined — set it in .env (see CLAUDE.md)"
#endif
#ifndef WIFI_PASSWORD
#error "WIFI_PASSWORD not defined — set it in .env"
#endif
#ifndef SCOREBOARD_IP
#error "SCOREBOARD_IP not defined — set it in .env"
#endif

// Camera IPs. Default to the standard scheme on the current deployment
// subnet (192.168.1.x); .env overrides via CAM_A_IP / CAM_B_IP. The
// last-octet convention (.90 cam A / .91 cam B) is stable across
// network changes — only the subnet prefix follows the WiFi.
#ifndef CAM_A_IP
#define CAM_A_IP "192.168.1.90"
#endif
#ifndef CAM_B_IP
#define CAM_B_IP "192.168.1.91"
#endif

// CrowPanel DIS07050H pinout — bare B0/R0/.. collide with Arduino's bit
// macros so we prefix with the channel.
namespace pins {
    constexpr int LCD_B0=8,  LCD_B1=3,  LCD_B2=46, LCD_B3=9,  LCD_B4=1;
    constexpr int LCD_G0=5,  LCD_G1=6,  LCD_G2=7,  LCD_G3=15, LCD_G4=16, LCD_G5=4;
    constexpr int LCD_R0=45, LCD_R1=48, LCD_R2=47, LCD_R3=21, LCD_R4=14;
    constexpr int LCD_HSYNC=39, LCD_VSYNC=41, LCD_DE=40, LCD_PCLK=0;
    constexpr int LCD_BACKLIGHT = 2;
    constexpr int TOUCH_SDA=19, TOUCH_SCL=20;
    constexpr int TOUCH_INT=-1, TOUCH_RST=-1;   // CrowPanel: not wired separately
}

// Parallel RGB panel + auto-flushed canvas. Standard ILI6122 timing —
// the wider HBP=43 / VBP=12 vs the library's tighter 8/4/8 defaults is
// what makes the full 800×480 actually render.
Arduino_ESP32RGBPanel *rgbpanel = new Arduino_ESP32RGBPanel(
    pins::LCD_DE, pins::LCD_VSYNC, pins::LCD_HSYNC, pins::LCD_PCLK,
    pins::LCD_R0, pins::LCD_R1, pins::LCD_R2, pins::LCD_R3, pins::LCD_R4,
    pins::LCD_G0, pins::LCD_G1, pins::LCD_G2, pins::LCD_G3, pins::LCD_G4, pins::LCD_G5,
    pins::LCD_B0, pins::LCD_B1, pins::LCD_B2, pins::LCD_B3, pins::LCD_B4,
    1, 8, 4, 43,
    1, 8, 4, 12,
    1,
    8000000     // 8 MHz pixel clock (was 16 MHz). Experiment: halves the
                // LCD's PSRAM DMA bandwidth (was ~32 MB/s), testing whether
                // DMA contention with WiFi explains the HMI's /status
                // refusing connections under load. If success rate jumps,
                // contention is the root cause. See
                // .plans/hmi-cam-polling-stability.md §7b.
);
Arduino_RGB_Display *gfx = new Arduino_RGB_Display(
    800, 480, rgbpanel, 0, true);

// Minimal inline GT911 driver. The TAMC_GT911 lib chokes on the
// CrowPanel revision that doesn't expose INT/RST (it tries to pinMode
// -1 which throws "Invalid pin" errors and leaves the lib in a partial
// init state). We do polling reads of the chip's status + coord
// registers directly over Wire.
namespace gt911 {
    constexpr uint8_t ADDR              = 0x5D;
    constexpr uint16_t REG_COMMAND      = 0x8040;  // 0=normal, 2=soft reset
    constexpr uint16_t REG_PROD_ID      = 0x8140;  // 4 ASCII chars
    constexpr uint16_t REG_FW_VER       = 0x8144;  // 2 bytes LE
    constexpr uint16_t REG_STATUS       = 0x814E;  // bit7=ready, low 4=#points
    constexpr uint16_t REG_POINT1       = 0x8150;  // 7 bytes per point
    static int  lastX = -1, lastY = -1;
    static bool touched = false;
    static uint32_t pollCount = 0;
    static uint32_t touchCount = 0;
    // Diagnostic state — exposed via /debug/touch so we can probe the chip
    // from outside without a serial cable.
    static uint8_t  lastStatus = 0;       // raw 0x814E byte from most recent poll
    static uint8_t  bootCfgVer = 0;       // config version read at boot
    static uint8_t  postCfgVer = 0;       // config version after blob write (or boot if no write)
    static bool     wroteBlob = false;    // did we write the fallback config this boot?
    static bool     wroteOk   = false;    // did the chip accept the blob (post-write ver = 0x42)?
    static char     prodId[5] = {0,0,0,0,0};
    static uint16_t fwVer = 0;

    static bool writeReg(uint16_t reg, uint8_t v) {
        Wire.beginTransmission(ADDR);
        Wire.write((uint8_t)(reg >> 8));
        Wire.write((uint8_t)(reg & 0xFF));
        Wire.write(v);
        return Wire.endTransmission() == 0;
    }
    static bool readRegs(uint16_t reg, uint8_t* buf, int n) {
        Wire.beginTransmission(ADDR);
        Wire.write((uint8_t)(reg >> 8));
        Wire.write((uint8_t)(reg & 0xFF));
        if (Wire.endTransmission(false) != 0) return false;
        Wire.requestFrom((int)ADDR, n);
        int i = 0;
        while (Wire.available() && i < n) buf[i++] = Wire.read();
        return i == n;
    }

    // Chunked sequential write — Wire's default 128-byte buffer can't hold
    // the 185-byte config payload in one transaction, so we split it into
    // 16-byte runs and advance the register address each time.
    static bool writeRegs(uint16_t reg, const uint8_t* buf, int n) {
        constexpr int CHUNK = 16;
        for (int off = 0; off < n; off += CHUNK) {
            int len = (n - off > CHUNK) ? CHUNK : (n - off);
            Wire.beginTransmission(ADDR);
            Wire.write((uint8_t)((reg + off) >> 8));
            Wire.write((uint8_t)((reg + off) & 0xFF));
            for (int i = 0; i < len; i++) Wire.write(buf[off + i]);
            if (Wire.endTransmission() != 0) {
                Serial.printf("[gt911] writeRegs chunk @0x%04X (%d bytes) FAILED\n",
                              reg + off, len);
                return false;
            }
        }
        return true;
    }

    // Verified 800x480 GT911 config blob from bekencorp/armino production
    // firmware (middleware/driver/tp/tp_gt911.c, single-touch variant ver 0x42).
    // 184 cfg bytes (0x8047-0x80FE) + 1 checksum (0x80FF). After writing the
    // 185 bytes, set 0x8100 = 1 ("config_fresh") to apply.
    // Header: ver=0x42, x_max=0x0320 (800), y_max=0x01E0 (480), touch_pts=1.
    static constexpr uint8_t CFG_800x480[185] = {
        0x42, 0x20, 0x03, 0xE0, 0x01, 0x01, 0x3D, 0x00, 0x01, 0x08, 0x28, 0x05, 0x50, 0x32, 0x03, 0x05,
        0x00, 0x00, 0x00, 0x00, 0x00, 0x00, 0x00, 0x18, 0x1A, 0x1F, 0x14, 0x8C, 0x24, 0x0A, 0x1B, 0x19,
        0xF4, 0x0A, 0x00, 0x00, 0x00, 0x20, 0x04, 0x1C, 0x00, 0x00, 0x00, 0x00, 0x00, 0x03, 0x64, 0x32,
        0x00, 0x00, 0x00, 0x11, 0xB2, 0x94, 0xC5, 0x02, 0x07, 0x00, 0x00, 0x04, 0x8E, 0x16, 0x00, 0x5D,
        0x23, 0x00, 0x3D, 0x38, 0x00, 0x2A, 0x5A, 0x00, 0x22, 0x90, 0x00, 0x22, 0x00, 0x00, 0x00, 0x00,
        0x00, 0x00, 0x00, 0x00, 0x00, 0x00, 0x00, 0x00, 0x00, 0x00, 0x00, 0x00, 0x00, 0x00, 0x00, 0x00,
        0x00, 0x00, 0x00, 0x00, 0x00, 0x00, 0x00, 0x00, 0x00, 0x00, 0x00, 0x00, 0x00, 0x00, 0x00, 0x00,
        0x14, 0x12, 0x10, 0x0E, 0x0C, 0x0A, 0x08, 0x06, 0x04, 0x02, 0xFF, 0xFF, 0xFF, 0xFF, 0xFF, 0xFF,
        0xFF, 0xFF, 0xFF, 0xFF, 0xFF, 0xFF, 0xFF, 0xFF, 0xFF, 0xFF, 0xFF, 0xFF, 0xFF, 0xFF, 0x1D, 0x1C,
        0x18, 0x16, 0x14, 0x13, 0x12, 0x10, 0x0F, 0x0C, 0x0A, 0x08, 0x06, 0x04, 0x02, 0x00, 0xFF, 0xFF,
        0xFF, 0xFF, 0xFF, 0xFF, 0xFF, 0xFF, 0xFF, 0xFF, 0xFF, 0xFF, 0xFF, 0xFF, 0xFF, 0xFF, 0xFF, 0xFF,
        0xFF, 0xFF, 0xFF, 0xFF, 0xFF, 0xFF, 0xFF, 0xFF, 0x4F
    };

    // One-shot: only fires when the chip reports no factory config loaded
    // (0xFF) or a version older than what's compiled in. Otherwise we
    // leave the chip's burned-in tuning alone.
    static bool writeFactoryConfig() {
        Serial.println("[gt911] writing 800x480 config blob (Beken/armino, ver 0x42)");
        if (!writeRegs(0x8047, CFG_800x480, sizeof(CFG_800x480))) {
            Serial.println("[gt911] config payload write FAILED — i2c bus issue?");
            return false;
        }
        // Read back the first 8 bytes BEFORE committing. If these are
        // 0x42,0x20,0x03,0xE0,0x01,... then the chip is accepting writes
        // to the config-RAM region. If they're still 0xFF, the chip is
        // silently rejecting writes (likely a config-lock / version-bump
        // protection issue) and the commit can never succeed.
        uint8_t rb[8] = {0};
        readRegs(0x8047, rb, 8);
        Serial.printf("[gt911] post-write pre-commit readback: %02X %02X %02X %02X %02X %02X %02X %02X\n",
                      rb[0], rb[1], rb[2], rb[3], rb[4], rb[5], rb[6], rb[7]);
        // Goodix two-step commit:
        //   0x8100 = 1 → load config from RAM into working registers
        //   0x8101 = 1 → persist config to chip NVRAM (some units require
        //                this for the version-bump check to clear)
        if (!writeReg(0x8100, 0x01)) {
            Serial.println("[gt911] config commit (0x8100<-1) FAILED");
            return false;
        }
        delay(50);
        if (!writeReg(0x8101, 0x01)) {
            Serial.println("[gt911] config persist (0x8101<-1) FAILED");
            // not fatal — the chip may still scan from RAM
        }
        delay(500);  // generous — datasheet implies ~200ms but some units need more
        uint8_t cfgver = 0;
        readRegs(0x8047, &cfgver, 1);
        Serial.printf("[gt911] post-commit config version = 0x%02X (want 0x42)\n", cfgver);
        // Pre-commit readback proved bytes land; if cfgver reverted, the
        // chip is rejecting the commit (likely version-bump check or
        // panel-tuning self-test failure on factory-blank NVRAM).
        postCfgVer = cfgver;
        wroteOk = (cfgver == 0x42);
        return wroteOk;
    }

    static void begin() {
        uint8_t id[5] = {0};
        if (readRegs(REG_PROD_ID, id, 4)) {
            for (int i = 0; i < 4; i++) prodId[i] = id[i] ? id[i] : '?';
            prodId[4] = 0;
            Serial.printf("[gt911] product_id = \"%s\"\n", prodId);
        } else {
            Serial.println("[gt911] FAILED to read product ID");
        }
        uint8_t fw[2] = {0};
        if (readRegs(REG_FW_VER, fw, 2)) {
            fwVer = ((uint16_t)fw[1] << 8) | fw[0];
            Serial.printf("[gt911] firmware = 0x%04X\n", fwVer);
        }

        // Probe config version. 0xFF = no factory config loaded; the
        // chip will refuse to scan until we write a valid blob. ONLY
        // overwrite when 0xFF — anything else (including older versions)
        // means a factory-tuned config is present and we'd lose the
        // panel-specific drive/sense calibration if we replaced it.
        uint8_t cfgver = 0;
        readRegs(0x8047, &cfgver, 1);
        bootCfgVer = cfgver;
        postCfgVer = cfgver;
        Serial.printf("[gt911] boot config version = 0x%02X\n", cfgver);
        if (cfgver == 0xFF) {
            Serial.println("[gt911] no valid config — writing fallback blob");
            wroteBlob = true;
            writeFactoryConfig();
        } else {
            Serial.println("[gt911] factory config present — leaving as-is");
        }

        // Always end in normal-scan mode with a cleared status byte so
        // the first real touch produces a "buffer ready" event.
        writeReg(REG_COMMAND, 0x00);
        delay(10);
        writeReg(REG_STATUS, 0);
        Serial.println("[gt911] init complete, polling enabled");
    }


    static void poll() {
        pollCount++;
        uint8_t s;
        if (!readRegs(REG_STATUS, &s, 1)) { lastStatus = 0xEE; touched = false; return; }
        lastStatus = s;
        // Diagnostic: print the raw status byte once every 500 polls so we
        // can see what the chip is actually reporting without flooding the
        // serial line. Strip this once the panel is reliably working.
        if (pollCount % 500 == 0) {
            Serial.printf("[gt911] status=0x%02X (poll #%u)\n", s, (unsigned)pollCount);
        }
        if (!(s & 0x80)) { touched = false; return; }
        int n = s & 0x0F;
        if (n == 0) { touched = false; writeReg(REG_STATUS, 0); return; }
        uint8_t pt[7];
        if (!readRegs(REG_POINT1, pt, 7)) { writeReg(REG_STATUS, 0); return; }
        lastX = pt[0] | (pt[1] << 8);
        lastY = pt[2] | (pt[3] << 8);
        touched = true;
        touchCount++;
        writeReg(REG_STATUS, 0);
    }
}

// =============================================================
// Camera state — both cameras polled every CAM_POLL_MS so we can render
// status pills under HOME/AWAY without serially blocking the touch loop.
// While the calibration overlay is in RUNNING phase, we throttle the
// poll rate to CAM_POLL_MS_OVERLAY (0.5 Hz) — the cal-snapshot fetch
// dominates that window anyway and slower polling reduces LWIP socket
// churn that would otherwise wedge the HMI's web server. See
// .plans/hmi-cam-polling-stability.md (Level B).
// =============================================================
constexpr uint32_t CAM_POLL_MS         = 1000;   // baseline 1 Hz
constexpr uint32_t CAM_POLL_MS_OVERLAY = 2000;   // 0.5 Hz during cal overlay

struct CamState {
    const char* ip;
    bool online = false;
    int  state = -1;          // 0=IDLE, 1=CAL, 2=PLAY, 3=PAUSE, 4=AUTOTUNE
    bool calibrated = false;
    int  goals = 0;
    uint32_t lastPollMs = 0;
    // Extra fields pulled from /status during calibration. None of these
    // are touched by the score path, so racing reads from the main loop
    // are harmless (worst case: one stale frame of overlay text).
    int  motionTh = 0;
    int  colorTh = 0;
    int  calContrast = 0;
    // Auto-tune sweep progress (cam exposes these in /status). Driven
    // by the autotune sub-phase of the calibration overlay; the chain
    // is .plans/autotune-chain.md. autoDone is an int from the cam
    // (`"autoDone":1` not `"autoDone":true`) — extract as int, treat as
    // bool via `> 0`.
    int  autoStep  = 0;
    int  autoTotal = 0;
    int  autoDone  = 0;
    bool hasCalSnap = false;
    // calMsg can grow LONG — cam's OK! success message reaches ~159
    // chars ("OK! Edge threshold: ... Limits ... Colour ... Motion ..."),
    // so a generous buffer is needed. 192 bytes fits every observed
    // cam message with margin. drawCalOverlay still truncates the
    // displayed portion visually so a long message doesn't overflow
    // the panel width.
    char calMsg[192] = {0};
};
static CamState camA;
static CamState camB;

// Forward decl: the celebration jingle helper lives down in the player
// section. Goal handlers above that section trigger it on score updates.
static void triggerJingle();

// HMI maintains its own score state — this device IS the placar, so
// /status / /goal / /goal-undo / /api/reset hit local memory rather
// than a downstream MAX7219 board. Cameras push goals here exactly as
// they pushed to the LED placar; the LED placar can be retired or
// kept as a passive mirror.
static volatile int placarA = 0;
static volatile int placarB = 0;
static volatile bool placarOnline = true;  // we're the placar — always "online"
static bool firstFullDraw = true;

// HTTP server on port 80 — same REST shape as src_scoreboard/scoreboard.cpp
// so existing camera firmware can point SCOREBOARD_IP at this device with
// zero protocol changes. Uses esp_http_server (same stack the cameras use)
// instead of WebServer.h — the latter exhausted its 5-socket pool under
// integration-test burst load (port 80 starts refusing connections after
// ~70 rapid requests). esp_http_server allows 10 sockets + LRU purge.
static httpd_handle_t server = NULL;

// Dirty flags set by the background polling task (core 0). The main loop
// (core 1) checks them every iteration and re-renders only what changed,
// so HTTP latency never blocks touch reads or button feedback.
static volatile bool dirtyHeader  = false;
static volatile bool dirtyDigits  = false;
static volatile bool dirtyStatus  = false;
static volatile bool dirtyButtons = false;
static volatile bool dirtyOverlay = false;
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
void loop() {
    if (WiFi.status() != WL_CONNECTED) {
        WiFi.reconnect();
        delay(500);
        return;
    }

    // Periodic heartbeat so we can tell from serial whether the touch
    // poll is even running and how many real touches it's seeing.
    static uint32_t lastHb = 0;
    uint32_t hbNow = millis();
    if (hbNow - lastHb >= 5000) {
        Serial.printf("[hb] polls=%u touches=%u  placar=%dx%d\n",
                      (unsigned)gt911::pollCount, (unsigned)gt911::touchCount,
                      (int)placarA, (int)placarB);
        lastHb = hbNow;
    }

    // Touch first so button feedback feels instant.
    serviceTouch();

    // Tear down the goal beep when its duration elapses (non-blocking).
    serviceGoalBeep();

    // esp_http_server runs on its own background task (configured with
    // 10 max sockets + LRU purge), so there's no handleClient() to call
    // from the main loop. The REST handlers update placarA/placarB +
    // dirtyDigits atomically (single-byte volatile writes), so the main
    // loop re-renders consistently on the next pass through the dirty
    // flags below.

    if (pendingAction != ACT_NONE) {
        ActionId a = pendingAction;
        pendingAction = ACT_NONE;
        runAction(a);
    }

    // Drive the calibration-overlay state machine BEFORE redrawing so
    // any auto-dismiss this iteration sets the underlying dirty flags
    // in time to repaint the placar view on the same frame.
    updateCalOverlay();

    // Re-render whatever the polling task on core 0 marked dirty. Order
    // matters so overlapping rects redraw correctly (header before
    // digits before buttons before status, overlay on top of everything).
    //
    // While the overlay is up we SKIP the score and START-button
    // redraws — those rects live underneath the overlay panel, so
    // re-rendering them would punch through the white overlay and
    // leave a START/digit ghost on top of Cancelar. The dirty flags
    // stay set; they'll be processed on the first frame after the
    // overlay dismisses (which also clears them via dirtyDigits etc).
    // All underlay redraws are gated by overlayActive() — the overlay
    // now spans the full 800x480, so the header/score/buttons/status
    // would all bleed through it. Dirty flags stay set; first frame
    // after dismiss processes them naturally (the dismiss path in
    // updateCalOverlay() also sets dirtyDigits + dirtyButtons +
    // dirtyStatus to force a fresh placar repaint).
    if (!overlayActive() && dirtyHeader)  { dirtyHeader  = false; drawScoreboardPill(); }
    if (!overlayActive() && dirtyDigits)  { dirtyDigits  = false; drawScoreboardPill(); }
    if (!overlayActive() && dirtyButtons) { dirtyButtons = false; drawButton(STARTPAUSE_BUTTON_IDX); }
    if (!overlayActive() && dirtyStatus)  {
        dirtyStatus = false;
        drawStatusPill(0);
        drawStatusPill(1);
    }

    // 1 Hz timer tick — set dirtyTimer when displayed seconds advance
    // so we redraw ONLY the timer disc instead of the whole pill.
    {
        static uint32_t lastShownSec = 0;
        uint32_t e = matchElapsedMs() / 1000;
        if (e != lastShownSec) {
            lastShownSec = e;
            dirtyTimer = true;
        }
    }
    if (!overlayActive() && dirtyTimer) {
        dirtyTimer = false;
        drawTimerOnly();
    }

    // Overlay paints last so it sits on top of the placar layer. It
    // re-renders whenever pollCam() flags new calMsg / state / progress
    // markers, when the state machine flips phase, or right after we
    // raised it from a button tap (runAction sets dirtyOverlay).
    if (overlayActive() && dirtyOverlay) {
        dirtyOverlay = false;
        drawCalOverlay();
    }

    delay(2);  // small yield for FreeRTOS housekeeping
}

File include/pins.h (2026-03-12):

#pragma once

// =============================================================
// DFR1154 ESP32-S3 AI Camera — Pin Definitions
// Source: https://github.com/DFRobot/DFR1154_Examples
// =============================================================

// --- Camera (OV3660) ---
#define CAM_PIN_PWDN    -1
#define CAM_PIN_RESET   -1
#define CAM_PIN_XCLK     5
#define CAM_PIN_SIOD     8   // SCCB I2C SDA
#define CAM_PIN_SIOC     9   // SCCB I2C SCL
#define CAM_PIN_D7       4
#define CAM_PIN_D6       6
#define CAM_PIN_D5       7
#define CAM_PIN_D4      14
#define CAM_PIN_D3      17
#define CAM_PIN_D2      21
#define CAM_PIN_D1      18
#define CAM_PIN_D0      16
#define CAM_PIN_VSYNC    1
#define CAM_PIN_HREF     2
#define CAM_PIN_PCLK    15

// --- Audio: I2S PDM Microphone ---
#define MIC_CLOCK_PIN   38
#define MIC_DATA_PIN    39

// --- Audio: MAX98357 Speaker Amplifier (I2S) ---
#define SPK_BCLK_PIN    45
#define SPK_LRC_PIN     46
#define SPK_DOUT_PIN    42

// --- IR LED / Flash ---
#define LED_PIN         47

// --- Status LED ---
#define STATUS_LED_PIN   3

// --- SD Card (SPI) ---
#define SD_CS_PIN       10
#define SD_MOSI_PIN     11
#define SD_SCK_PIN      12
#define SD_MISO_PIN     13

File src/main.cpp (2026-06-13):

// =============================================================
// gol-cam — Button Soccer Goal Detection Camera
// Contrast-based detection with I2S goal celebration audio
// =============================================================

#include <Arduino.h>
#include <WiFi.h>
#include <WiFiMulti.h>
#include <HTTPClient.h>
#include "esp_camera.h"
#include "img_converters.h"
#include "driver/i2s.h"
#include "camera.h"
#include "pins.h"
#include "goal_detector.h"
#include "frame_store.h"
#include "wifi_multi_connect.h"
#include <math.h>

// --- WiFi credentials (from .env file via build defines) ---
#ifndef WIFI_SSID
#error "WIFI_SSID not defined. Create a .env file with WIFI_SSID=your_ssid"
#endif
#ifndef WIFI_PASSWORD
#error "WIFI_PASSWORD not defined. Create a .env file with WIFI_PASSWORD=your_password"
#endif

// Forward declarations
void startCameraServer();

// Globals
GoalDetector detector;
FrameStore frameStore;
volatile bool goalJustScored = false;

#define DETECT_W 320
#define DETECT_H 240

// Game states
enum GameState { STATE_IDLE, STATE_CALIBRATING, STATE_PLAYING, STATE_PAUSED, STATE_AUTOTUNE };
volatile GameState gameState = STATE_IDLE;

// Auto-tune progress (read by /status)
volatile int autotuneStage = 0;       // current sweep stage 0=idle, 1..N=running
volatile int autotuneStep = 0;
volatile int autotuneTotalSteps = 0;
volatile int autotuneDone = 0;        // 1 once the full sweep finishes
volatile int autotuneBestScore = 0;
volatile int autotuneBestGain  = 8;
volatile int autotuneBestGceil = 1;
volatile int autotuneBestAec   = 150;
volatile int autotuneBestGma   = 0;
volatile int autotuneBestLenc  = 0;
volatile int autotuneBestCon   = 1;
volatile int autotuneBestBri   = -1;
volatile int autotuneBestSharp = 1;

// Live "currently being tested" values — updated every applyCamSettings() so the
// dashboard can show sliders moving in real time during the sweep.
volatile int curCamGain  = 8;
volatile int curCamGceil = 1;
volatile int curCamAec   = 150;
volatile int curCamGma   = 0;
volatile int curCamLenc  = 0;
volatile int curCamCon   = 1;
volatile int curCamBri   = -1;
volatile int curCamSharp = 1;

// Edge-based calibration (Sobel gradient)
volatile int calContrastMin = 0;   // Sobel gradient threshold (0 = not calibrated)
volatile int calPixelCount = 0;    // Edge pixel count of dadinho
volatile int calBboxW = 0, calBboxH = 0;

// Frame-differencing trigger — catches fast-moving balls the edge detector
// misses by counting pixels in the ROI whose raw luma changed > motionPixelDelta
// vs. the previous frame. Calibrated against the quiet-scene noise floor; both
// the per-pixel delta and the absolute threshold are runtime-tunable via REST.
uint8_t* prevFrame = nullptr;            // PSRAM copy of last raw luma frame
uint8_t* lumaBuf  = nullptr;             // per-frame Y plane derived from RGB565 fb
volatile bool prevFrameValid = false;

// Colour-match trigger — fires when enough ROI pixels match the ball's
// learned chroma (U, V). Hue-invariant to luma so the IR hot-spot, room
// lighting, and shadows don't confuse it the way the motion trigger
// could. Target U/V are sampled at /calibrate.
volatile int targetU = 0;                // calibrated ball chroma U (-128..127)
volatile int targetV = 0;                // calibrated ball chroma V (-128..127)
volatile int colorTol = 28;              // max |Δu|+|Δv| for a pixel to "match"
volatile int colorThreshold = 0;         // 0 = disabled; pixels-matching needed to fire
volatile int calColorFloor = 0;          // peak match count seen in quiet calibration scene
volatile int lastColorMatch = 0;         // live match count
volatile int lastColorBboxPct = 0;       // live match-bbox area as % of ROI
volatile int motionPixelDelta = 30;      // |Δluma| above this counts a pixel as "moving" (/motion-delta)
volatile int motionThreshold = 0;        // 0 = disabled; pixels-moving needed to fire (/motion-threshold)
volatile int motionBboxMaxPct = 30;      // reject trigger when motion bbox covers > N% of ROI (/motion-bbox-max)
volatile int calMotionFloor = 0;         // peak noise motion count observed during cal
volatile int lastMotion = 0;             // live motion count for diagnostics
volatile int lastMotionBboxPct = 0;      // live motion bbox area as % of ROI (diagnostic)

// Detection params
#define COOLDOWN_MS 10000
#define STABLE_FRAMES_NEEDED 1
// During PLAYING, only encode 1 in playStreamSkip frames to leave CPU for the
// detection loop (JPEG dominates the per-frame cost). A goal-frame always encodes.
// Runtime-tunable via /stream-skip; 1 disables throttling.
volatile int playStreamSkip = 3;

// ROI offset and size for digital pan/resize (adjusted via /roi endpoint).
// Default + auto-tune lock: 304×160 centered (matches a typical button-soccer
// goal frame's wide-and-short aspect — fills the goal mouth without the side
// posts). Auto-tune resets the ROI to this baseline so calibration is
// reproducible across boards.
#define AUTOTUNE_ROI_W 304
#define AUTOTUNE_ROI_H 160
volatile int roiOffsetX = 0, roiOffsetY = 0;
volatile int roiW = AUTOTUNE_ROI_W, roiH = AUTOTUNE_ROI_H;

// Shared detection state for web console
volatile int lastMatchCount = 0, lastBboxW = 0, lastBboxH = 0;
volatile int lastMinPx = 0, lastMaxPx = 0, lastMaxBbox = 0;
volatile float lastDensity = 0;
volatile const char* lastRejectReason = "";

// Last-detected dadinho bbox (in DETECT_W/H pixel coords). Set during STATE_PLAYING
// when the dice passes the size/density filters; consumed by the dashboard's SVG
// overlay. -1 = no current detection.
volatile int diceBboxX = -1, diceBboxY = -1, diceBboxW = 0, diceBboxH = 0;

// Calibration snapshot
uint8_t* calSnapshotBuf = nullptr;
size_t calSnapshotLen = 0;
SemaphoreHandle_t calSnapshotMutex = nullptr;
char calFeedback[256] = "";

// Goal snapshot — pair of JPEGs captured atomically when isGoal fires:
//   goalSnapshotBuf      = current raw frame (the moment we decided "goal")
//   goalSnapshotPrevBuf  = previous raw frame (one frame earlier, often the
//                          actual ball-in-flight evidence for motion triggers)
// Both share goalSnapshotMutex and bump goalSnapshotSeq together.
uint8_t* goalSnapshotBuf = nullptr;
size_t goalSnapshotLen = 0;
uint8_t* goalSnapshotPrevBuf = nullptr;
size_t goalSnapshotPrevLen = 0;
SemaphoreHandle_t goalSnapshotMutex = nullptr;
volatile uint32_t goalSnapshotSeq = 0;
volatile uint32_t lastGoalTimeMs = 0;

// --- I2S Speaker for goal celebration ---
// Driver is installed only when playing, then uninstalled to keep speaker silent.
#define I2S_NUM I2S_NUM_0
#define GOAL_SAMPLE_RATE 16000
TaskHandle_t goalSoundTaskHandle = NULL;

// Speaker volume: 0-100 (percentage)
volatile int speakerVolume = 70;
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

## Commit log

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2026-03-12 Switch to native grayscale frame differencing for goal detection
    Replace JPEG size-change proxy (which was too insensitive) with
    pixel-level grayscale frame comparison. Camera now captures in
    PIXFORMAT_GRAYSCALE natively, with frame2jpg() conversion for web
    streaming. Detection runs in main loop with 12fps, confirmed working
    via LED self-test showing 5-23% change ratios on motion events.
    [main.cpp, web_stream.cpp]
2026-03-12 Reduce detection sensitivity and fix web stream stability
    - Raise PIXEL_THRESHOLD 15->25 and CHANGE_THRESHOLD 3%->8% to avoid
    false goal triggers from casual hand movement
    - Increase STABLE_FRAMES_NEEDED 3->5 for better arming
    - Add 3rd frame buffer to reduce contention between detection and stream
    - Increase HTTP server stack to 8KB for frame2jpg conversion
    [main.cpp, web_stream.cpp]
2026-03-13 Fix stream freezing: single camera consumer with FrameStore
    The stream was freezing/going black because both the main loop and
    HTTP stream handler were calling esp_camera_fb_get(), fighting over
    frame buffers. Now only the main loop grabs camera frames, converts
    to JPEG via frame2jpg(), and stores in a thread-safe FrameStore.
    The stream/capture handlers read from the store instead.
    [main.cpp, web_stream.cpp]
2026-03-13 Switch to yellow dice (dadinho) color detection
    Replace grayscale motion detection with RGB565 color filtering.
    Now detects only yellow pixels matching the dadinho dice color
    (R>=18/31, G>=30/63, B<=14/31). Triggers goal when yellow pixel
    count transitions from below to above threshold (15px), ignoring
    hands, buttons, and other non-yellow objects. Boosted camera
    saturation for better yellow discrimination.
    [main.cpp]
2026-03-13 Split stream to port 81 to fix status polling
    The MJPEG stream's long-lived connection was blocking /status
    fetch requests on port 80. Now stream runs on a separate HTTP
    server (port 81) so the page, status, and capture endpoints on
    port 80 remain responsive.
    [web_stream.cpp]
2026-03-13 Tighten yellow filter to reject skin tones
    Raised RGB565 thresholds (R>=24/31, G>=42/63, B<=10/31) and added
    saturation ratio check to only match bright saturated yellow like
    the dadinho dice. Skin tones (which have higher blue) are now
    rejected. Baseline noise dropped from 3-8 pixels to 0.
    [main.cpp]
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2026-03-13 Add cluster-based detection to reject hands
    Instead of only counting yellow pixels, now also checks that they
    form a tight cluster (small bounding box + high density). The
    dadinho creates a concentrated ~15x15px cluster, while hands
    produce scattered pixels across 40+ pixel bounding boxes with
    <5% density. This eliminates hand false positives.
    [main.cpp]
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2026-03-13 Enforce strict size limits to reject hand detections
    Added max pixel count (4x calibrated) and tighter bbox limit (2x
    calibrated) so hands get rejected as TOO-BIG. Added rejection
    reason logging (TOO-BIG, BBOX-BIG, TOO-SMALL, SPARSE) for
    easier debugging.
    [main.cpp]
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2026-03-13 Add calibration snapshot and feedback to web UI
    When calibrating, the camera now captures a snapshot with the detected
    object highlighted (green bounding box) and displays it on the page.
    Calibration feedback text shows what was found (pixel count, bbox size,
    color, detection limits) or why it failed.
    [main.cpp, web_stream.cpp]
2026-03-13 Add goal snapshot log and increase cooldown to 10 seconds
    Each goal now captures a photo with the green bounding box and displays
    it in a scrollable log on the page with timestamp and goal number.
    Cooldown between goals increased from 3s to 10s to prevent false
    triggers. Goal snapshots are served via /goal-snapshot endpoint.
    [main.cpp, web_stream.cpp]
2026-03-13 Rename goal to gol, add lightbox, pause/resume/reset controls
    - All UI text now says "GOL" instead of "GOAL"
    - Clicking a gol snapshot opens a full-screen lightbox overlay
    - Pause button freezes detection while keeping the stream live
    - Resume continues detection from paused state
    - Reset zeroes the score and clears the gol log
    - End Game returns to idle state
    - PAUSED state badge (yellow) added
    [main.cpp, web_stream.cpp]
2026-03-13 Add game control bar below camera and 10s cooldown countdown
    - Game control bar with Pause/Resume, Reset, End Game appears below
    camera during active gameplay (replaces scattered buttons)
    - Idle controls (Calibrate, Start) shown separately when not in game
    - After each gol, a green progress bar counts down the 10s cooldown
    showing "Detecting in Xs..." before detection resumes
    - Countdown data comes from firmware via cdRemain in status JSON
    [main.cpp, web_stream.cpp]
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2026-03-13 Fix game-bar and countdown not showing (display:none CSS default)
    Setting style.display='' reverts to the CSS default display:none.
    Changed to explicit 'block' for game-bar and countdown.
    [web_stream.cpp]
2026-03-13 Fix Start Game button not appearing after calibration
    updateUI was only called on state changes, but calibration returns
    to IDLE (same state), so buttons never updated. Moved updateUI call
    outside the state-change block so it runs on every status poll.
    [web_stream.cpp]
2026-03-13 Reset returns to calibration mode (IDLE state)
    Reset now goes back to IDLE so the user can recalibrate before
    starting a new game. Score, gol log, and snapshots are cleared.
    [main.cpp, web_stream.cpp]
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2026-04-04 Add ROI controls, camera filters, contrast detection, and goal audio
    - Digital pan (D-pad) and independent W/H resize for detection ROI
    - Camera filter presets (Vivid, Night IR, Gray, Negative, Hi-Con B&W, IR+Gray)
    - Brightness, contrast, saturation, sharpness sliders on both dashboards
    - Replace RGB color matching with contrast-based detection for lighting independence
    - I2S speaker plays Globo goal vinheta 3x on goal detection (silent between goals)
    - 1-frame arming for fast ball detection at 12fps QVGA
    [main.cpp, web_stream.cpp]
2026-04-05 Switch to grayscale Sobel edge detection with full dashboard controls
    - Camera: PIXFORMAT_GRAYSCALE with manual exposure/gain for max contrast
    - Detection: 3x3 Sobel edge detection replaces RGB color-contrast matching
    - Audio: 3 goal celebration MP3s (Brasil/Flamengo/Vasco) with dropdown selector
    - Audio preview: selecting audio plays 5s preview at current volume
    - Dashboard: vertical control panel with Bri/Con/Sharp/Exp/Gain/GCeil/Gamma/Lens/B&W/Vol/LED
    - Match dashboard: synced controls matching training dashboard
    - Volume control with test playback, I2S noise reduction
    - Software B&W threshold slider for post-processing contrast boost
    - Optimized defaults: Bri=-1, Con=1, Sharp=1, Exp=150,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
    [main.cpp, web_stream.cpp]
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2026-05-10 Refactor stream pipeline: client-side overlays, leaner auto-tune
    Move yellow ROI + limegreen dadinho overlays from RGB565 firmware encoding
    to SVG over the dashboard <img>. Restores fast grayscale-only JPEG path so
    the MJPEG stream can no longer stall during long auto-tune sweeps.
    Auto-tune trimmed to single pass over gain/gceil/aec/bri (15 captures, ~2s
    instead of 9s) and pushes one frame per stage to keep the stream warm.
    Otsu's threshold clamped to [30, 220] to avoid all-white/all-black frames.
    Replaces synthetic Brasil/Flamengo/Vasco PCM playback with a runtime-
    generated whistle (3 short blasts at 2700 Hz, vibrato + envelope) freeing
    ~1.3 MB of flash that was holding the unused gol_so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
    [main.cpp, web_stream.cpp]
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2026-05-10 Fix HTTPD stack overflow that crashed /status with 1500-byte buffer
    The status_handler builds the JSON response into a 1500-byte stack buffer.
    On the default 4 KB HTTPD task stack this collided with other locals and
    the framework's overhead — connections were silently reset before any
    response went out, so the dashboards thought the boards were unreachable
    mid-load.
    Bumping config.stack_size to 8192 (matching the stream server) fixes it.
    Verified end-to-end: HTML pages load, /status parses with all 55 fields,
    /roi + /threshold + /autotune respond, MJPEG stream pushes ~6 fps.
    [main.cpp, web_stream.cpp]
2026-05-10 Integrate placar-eletronico-wifi scoreboard
    Imports the LED matrix scoreboard from
    https://github.com/mpaiva/placar-eletronico-wifi as a second PlatformIO
    environment in this repo, switches it from standalone AP mode to STA on
    the same home Wi-Fi as the gol-cams, and wires automatic goal pushes
    from each camera into the new scoreboard.
    Scoreboard firmware (src_scoreboard/scoreboard.cpp):
    - WiFi STA, .env-driven SSID/password (same loader as gol-cam).
    - Original /a+, /b+, /az, /bz, /reset web UI preserved.
    - New JSON endpoints with CORS:
    GET /goal?side=a|b → +1 to that side, returns {ok, side, a, b}
    GET /status → {role, a, b, ip}
    GET /api/reset → zero both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
    [main.cpp, scoreboard.cpp, web_stream.cpp]
2026-05-10 Pin scoreboard to a static IP so power-cycles don't break gol-cam pushes
    The scoreboard runs untethered from a USB wall adapter (no more PC needed)
    but used to grab whatever IP DHCP handed out. Each power cycle risked a
    new IP, leaving the gol-cams talking to the wrong host until SCOREBOARD_IP
    in .env was updated.
    Adds three new .env keys (SCOREBOARD_STATIC_IP / GATEWAY / SUBNET) loaded
    only by the scoreboard env. The sketch calls WiFi.config() with them and
    sets a stable hostname (gol-placar) for router-side identification.
    WIFI_STATIC_IP intentionally not reused — the gol-cams and the scoreboard
    share .env but should never be assigned the same address.
    Verified end-to-end after a powe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
    [scoreboard.cpp]
2026-05-10 Redesign scoreboard web UI: bigger, smoother, color-coded sides
    The original page was a vertical stack of 5 same-sized buttons under a
    small score, refreshing the entire DOM every 2 s via meta-refresh — every
    tap caused a visual flash and no animation conveyed which side scored.
    New design:
    - Hero score zone fills the page. Each side gets a clamp(8em,40vw,18em)
    digit in tabular nums; Side A blue, Side B red, color-matched glow.
    - Team names are inline-editable (contenteditable) and persisted to
    localStorage so each browser keeps its own labels (e.g. team logos in
    text form, sponsor names, A/B fallback).
    - Goal animation: target side pulses + a soft radial overlay in the
    matching c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
    [scoreboard.cpp]
2026-05-10 Fix camera VSYNC overflow + expose memory stats in /status
    The .107 board reported intermittent issues during stress — Serial showed
    'cam_hal: EV-VSYNC-OVF', the camera HAL warning that all DMA framebuffers
    filled before the loop drained one. With fb_count=2 the headroom is gone
    the moment the loop pauses (autotune capture+score, JPEG encoding spikes,
    HTTPD bursts).
    Bumped fb_count from 2 to 3. The third buffer in PSRAM costs ~77 KB out
    of 8 MB and lets CAMERA_GRAB_LATEST cleanly drop one stale frame instead
    of overflowing the DMA.
    Also added five fields to /status: heap, heapMin (low-watermark since
    boot), psram, psramMin, uptime. Verified under load:
    baseline: heap 206 KB free, ps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
    [web_stream.cpp]
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2026-05-10 Scoreboard: bump constant brightness to 13 instead of pulsing
    The 35 ms brightness pulse to 15 every 2.5 s was not enough to keep a
    phone-oriented power bank from auto-shutting off — bench test confirmed
    the same ~10 s lifetime on battery as before. The bank is using averaged
    or minimum-current detection, not peaks.
    Switching strategy: keep the displays at brightness 13 (≈ 90% of max)
    all the time. With both sides displaying digits the steady draw goes from
    ~80 mA (at brightness 3) to ~600 mA — well above any consumer-bank
    threshold. Display is brighter and unmistakable in daylight, no more
    flicker.
    If it still drops on a particular bank, the hardware fix is a different
    power source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
    [scoreboard.cpp]
2026-05-10 Scoreboard: revert brightness to 8 — no software fix for battery anyway
    Bench test summary:
    - brightness 3 (original) → dies on bank in ~10 s
    - brightness 5 + 35 ms pulse to 15 → dies in ~10 s
    - brightness 13 (~600 mA constant) → dies in ~5 s (overcurrent?)
    Time-to-die is independent of current draw, so the bank is killing the
    rail by its own logic (likely a USB-handshake timer common in
    phone-oriented power banks). No firmware-only fix can keep it alive.
    Settling on brightness 8 — comfortable, well-readable in any light.
    For untethered use, plug into a 5 V wall adapter or an "always-on" bank.
    [scoreboard.cpp]
2026-05-10 Scoreboard: lower WiFi TX power + modem sleep — fixes battery operation
    Diagnosis converged: bench tests with brightness 3, 5, and 13 all died
    within ~10 s of switching to a phone-oriented power bank. The constant
    ~10 s window pointed not at MAX7219 current draw but at the WiFi
    association current spike (~400-500 mA for ~100 ms) tripping the bank's
    overcurrent protection right after boot.
    Fix:
    WiFi.setTxPower(WIFI_POWER_8_5dBm) // 8.5 dBm vs 20 dBm default
    // peak ~150 mA vs ~400 mA
    WiFi.setSleep(WIFI_PS_MIN_MODEM) // modem sleep between TX windows
    Tradeoff: TX power drops from 100 mW → ~10 mW. Range falls from ~50 m
    to >30 m indoors —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
    [scoreboard.cpp]
2026-05-10 Document the battery wiring + 1000 µF cap that makes the scoreboard portable
    Validated on bench: connecting the battery directly to VIN + GND on the
    DevKit and dropping a 1000 µF electrolytic across the battery terminals
    makes the scoreboard run untethered indefinitely. The cap absorbs the
    remaining WiFi association current spike so the battery's terminal
    voltage doesn't sag below the ESP32's brownout threshold.
    This sidesteps phone-oriented power banks entirely (their auto-cutoff
    logic is what was killing the board after ~10 s on USB power).
    [scoreboard.cpp]
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2026-05-26 fix: /status reports correct side for home/away cameras
    Camera B (BOARD_ROLE=home) was reporting "side":"A" in /status because
    web_stream.cpp used a stale strstr(role, "_b") derivation that only
    matched the legacy goal_a/goal_b convention. main.cpp::resolveScoreboardSide
    already handles home/away correctly for the actual push — share that
    result by exposing scoreboardSide.
    Verified: camera B now reports side=B; placar GET /goal?side=b
    increments the B counter end-to-end (1→2 in a row).
    [main.cpp, web_stream.cpp]
2026-05-26 feat: fast detection mode (QQVGA RGB565) toggled via /calibrate?fast=1
    Adds a runtime-toggleable detection path that re-inits the camera to QQVGA
    RGB565 to almost double the detection FPS (~12 → ~23 measured on the
    DFR1154/OV3660). Each RGB565 frame is reduced to an 8-bit luma plane with
    Y = (2R + 5G + B) / 8 before the existing Sobel edge pipeline runs — so
    the calibration math, ROI, and goal-decision logic are unchanged.
    REST: GET /calibrate accepts an optional ?fast=1. Switching modes
    invalidates calibration (different threshold + bbox scale) and the
    operator must keep the dadinho in view during the request. /calibrate
    without the param reverts to the original QVGA grayscale path. /s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
    [main.cpp, web_stream.cpp]
2026-05-26 Revert "feat: fast detection mode (QQVGA RGB565) toggled via /calibrate?fast=1"
    This reverts commit fd6287cf6a6e99b0790c73d06bd55c82892c5d35.
    [main.cpp, web_stream.cpp]
2026-05-26 feat: frame-differencing trigger + JPEG throttle to catch fast balls
    At 12 fps each frame is 83 ms, so a ball that flashes through the goal
    ROI between captures was missed entirely by the edge+bbox detector. Two
    fixes ship together:
    1. **Motion trigger.** Allocates a PSRAM previous-frame buffer (76 800 B,
    QVGA). Each PLAYING frame counts pixels in the ROI with |Δluma| > 30
    vs. the previous frame. If the count exceeds motionThreshold the
    frame fires a goal — gated by the same 10 s cooldown as the edge
    trigger, so the two ORed paths never double-count.
    motionThreshold is calibrated automatically: at the end of a
    successful /calibrate the loop samples 6 quiet frames, keep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
    [main.cpp, web_stream.cpp]
2026-05-27 feat: REST endpoints to tune motion detector live
    Promotes MOTION_PIXEL_DELTA + PLAY_STREAM_SKIP from #defines to
    volatile globals so they can be swept without reflashing, and adds
    three handlers following the existing /threshold pattern:
    GET /motion-delta?val=N per-pixel |Δluma| threshold (clamp 1..200, dflt 30)
    GET /motion-threshold?val=N absolute pixel-count to fire (clamp 0..100000; 0 = disable trigger)
    GET /motion-delta + /stream-skip?val=N JPEG encode every Nth play frame (clamp 1..20, dflt 3)
    Each echoes the post-clamp value as JSON so the caller can confirm. No
    persistence — values reset on reboot; /calibrate recomputes motionTh
    from scratch.
    /status gains motionD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
    [main.cpp, web_stream.cpp]
2026-05-27 fix: VAR snapshot from raw luma instead of binarised frame
    The /goal-snapshot endpoint served the post-applyThreshold frame: every
    pixel is either 0 or 255 according to contrastThreshold (default 30), so
    a low-contrast or dimly-lit scene comes back almost entirely black.
    Useful for inspecting what the detector "sees" but unusable for the
    human VAR review the lightbox was built for.
    Goal decision is now computed before applyThreshold and the snapshot is
    encoded straight from the raw grayscale fb at quality 80 (vs. 70 for
    the stream). The live MJPEG stream stays binarised so the detection
    visualisation is unchanged. Cost: one extra ~50 ms frame2jpg call per
    goal — only fires once per cooldo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
    [main.cpp]
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2026-05-27 fix: match calibration silently failed + dashboard showed no feedback
    Two compounding issues made the match dashboard's Calibrate button feel
    broken even though the request reached the camera:
    1. Failed calibrations left calContrastMin / motionThreshold untouched,
    so /status kept reporting calibrated:true (with stale thresholds from
    the previous successful run) alongside the new "FAILED: ..." calMsg.
    The match dashboard's per-side badge stayed on "READY". Both failure
    paths in doCalibration now zero the calibration state so /status
    honestly reflects "this camera is not calibrated".
    2. The match dashboard's calibrate(side) was fire-and-forget — no
    button-disabled state,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
    [main.cpp]
2026-05-29 feat: stream raw grayscale (drop applyThreshold visualisation)
    Detection never depended on the binarised buffer — both Sobel and the
    motion-difference trigger read raw luma earlier in the loop and the
    copy into prevFrame is also pre-applyThreshold. The two applyThreshold
    calls existed solely so the operator could see what was above/below
    contrastThreshold in the live MJPEG.
    That visualisation made the match dashboard look like a high-contrast
    negative (huge white blobs, no scene context). With the motion trigger
    catching fast balls reliably the operator no longer needs the threshold
    preview, and a natural grayscale stream is much easier to frame the goal
    mouth against.
    contrastThreshold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
    [main.cpp]
2026-05-29 chore: remove dead contrastThreshold / applyThreshold / Otsu / B&W slider
    After the previous commit dropped applyThreshold from the loop, an entire
    stack of code existed solely to compute/transport/store the threshold it
    used. None of it affects detection. Removing it now to avoid drift.
    src/main.cpp
    - contrastThreshold global
    - applyThreshold() function
    - otsuScore() function (no other callers)
    - bestT/bestThresh threading through captureAndScore + sweepParam
    - autotuneBestThresh global
    - autotune's clamp + write to contrastThreshold + tune-DONE log/calMsg fields
    - stale "BEFORE applyThreshold" comments
    src/web_stream.cpp
    - extern contrastThreshold + extern autotuneBestThresh
    - threshold_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
    [main.cpp, web_stream.cpp]
2026-05-29 fix: motion trigger rejects global lighting shifts (DC removal)
    A uniform brightness change (clouds passing, room light flicker, auto-WB
    hiccup, hand shadow across the goal) raised every pixel's |Δluma| by the
    same amount, so any value > motionPixelDelta flagged the entire ROI as
    moving — and a goal fired even though nothing crossed the goal mouth.
    Now each frame's motion count subtracts the mean ROI |Δluma| before the
    per-pixel test: pixels are only counted if (|Δ| − mean) > motionPixelDelta.
    A uniform shift contributes ≈ 0 deviation everywhere → no false trigger.
    A localised object (the ball) spikes far above the slowly-changing
    background mean → still triggers.
    Same change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
    [main.cpp]
2026-05-29 fix: autotune optimises Sobel gradient energy instead of pixel variance
    Variance-as-objective rewarded scenes with one super-bright IR hot-spot
    against a dark surround (max bimodal spread) — so autotune pushed gain
    + aec until the dadinho saturated and disappeared inside the glow. The
    detector itself looks at edges, not raw intensity spread, so the right
    objective is gradient energy.
    roiStdev() replaced by roiGradEnergy() which sums sobelMag() across the
    ROI interior (skipping a 1px border for the 3×3 kernel). Saturated
    regions are flat → gradient zero → they no longer "count" toward the
    score, so the optimiser settles on an exposure where the dadinho's
    silhouette is crisp instead of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
    [main.cpp]
2026-05-29 fix: autotune penalises saturation so it can't chase the IR hot-spot
    The IR LED can't be turned off, so the ROI always carries a bright
    hot-spot whose rim still produces crisp Sobel edges. Pure
    gradient-energy autotune kept pushing exposure up because rewarding
    the hot-spot's edges always beat backing off. Result: dadinho washed
    out inside a saturated glow.
    roiGradEnergy() now also counts pixels that hit either clip rail (luma
    ≥ 250 or ≤ 5) and multiplies the gradient sum by
    mult = max(0, (N − 3·sat) / N)
    so 0% saturation keeps the score, 10% halves it, ≥33% saturation zeros
    it out entirely. A small bright dadinho around luma 240 doesn't trip
    the penalty; a glowing IR hot-spo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
    [main.cpp]
2026-05-29 fix: motion trigger rejects diffuse light variation via bbox compactness
    Mean subtraction caught uniform brightness shifts but not gradient ones
    — a cloud shadow, hand shadow, or fluorescent flicker that's stronger
    on one side of the goal mouth lifts the per-pixel deviation on the
    brighter half above motionPixelDelta and triggers a false goal even
    though nothing physical crossed the ROI.
    A real ball produces a tight blob of moving pixels (~5-15 % of ROI
    area). Any kind of lighting change spreads across most of the frame
    (~80-100 %). Track the bbox of motion pixels and gate the trigger:
    motionTrigger = (motion > motionThreshold)
    && (motionBboxPct ≤ motionBboxMaxPct)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
    [main.cpp, web_stream.cpp]
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
